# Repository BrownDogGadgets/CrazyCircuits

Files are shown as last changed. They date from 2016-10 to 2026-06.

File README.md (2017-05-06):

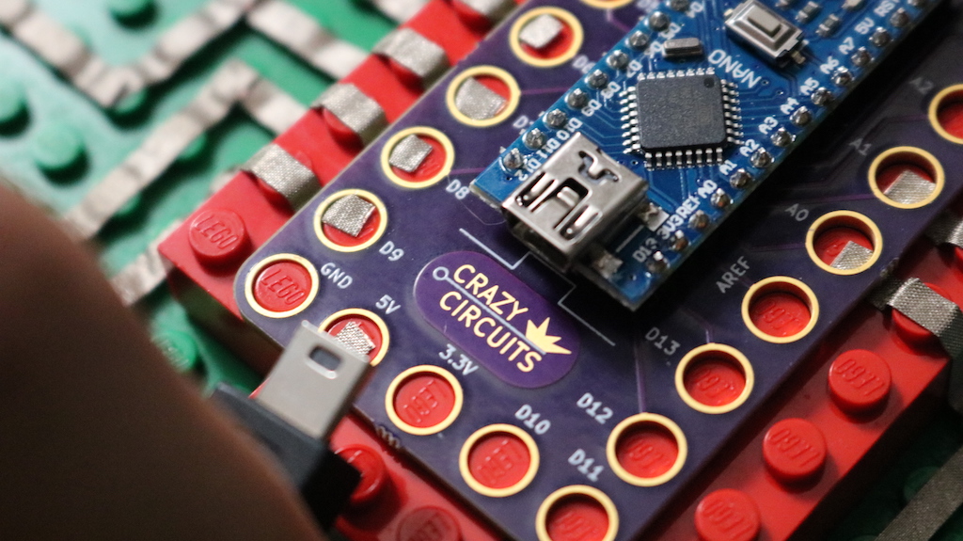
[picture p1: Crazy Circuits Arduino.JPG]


# Crazy Circuits 

Crazy Circuits is a project to create Lego-compatible circuit kits and modules by Brown Dog Gadgets. 

### Circuit Kits and Modules

The <a href="https://github.com/BrownDogGadgets/CrazyCircuits/tree/master/Circuit-Kits">Circuit Kits</a> section has finished zip files with manufacturing files and documentation.

### Development

The <a href="https://github.com/BrownDogGadgets/CrazyCircuits/tree/master/Development/">Developers</a> section has resources for hardware designers to create new modules.

### License

The hardware designs in this repository are distributed under the [CERN Open Hardware License v1.2](http://www.ohwr.org/documents/294). We have included a copy of the LICENSE file.

You may see, change, and share the source of these files. You may order and assemble your own boards from these hardware designs. We recommend the [OSH Park](http://oshpark.com/) board service. 

If you make changes, you must make those changed hardware files available under the same terms of the license. We accept pull requests if you'd like to add a module to our list of modules!

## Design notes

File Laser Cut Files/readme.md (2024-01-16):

Laser Cut Resources

Standalone files for laser cutting. Some may be part of larger projects, some may not.

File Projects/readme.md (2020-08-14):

# Crazy Circuits Projects

This repository holds code for many of our Crazy Circuits projects.

These are not step-by-step directions, and do not serve as full build guides.

For finished projects, instructions, and tutorials with photos and videos, as well as free templates, please visit [BrownDogGadgets.com](http://browndoggadgets.com/)

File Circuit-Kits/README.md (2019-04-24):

# Crazy Circuit Kits and Modules

These projects are all finished and ready to be downloaded. Each folder contains a single board (a module) or a kit that can be snapped apart. 

## Circuit Kits

|Project Name|Version|Documentation|Manufacturing Files|
|---|---|---|---|
|<a href="https://github.com/BrownDogGadgets/CrazyCircuits/tree/master/Circuit-Kits/Circuit-Kits/10mmLED-Button-Battery">10mmLED-Button-Battery</a>|v1.3|<a href="https://github.com/BrownDogGadgets/CrazyCircuits/blob/master/Circuit-Kits/Circuit-Kits/10mmLED-Button-Battery/10mmLED-Button-Battery-v1.3.pdf">View</a>|<a href="https://github.com/BrownDogGadgets/CrazyCircuits/raw/master/Circuit-Kits/Circuit-Kits/10mmLED-Button-Battery/10mmLED-Button-Battery-v1.3.zip">Zip</a>|
|<a href="https://github.com/BrownDogGadgets/CrazyCircuits/tree/master/Circuit-Kits/Circuit-Kits/LegoLED-Button-Battery">LegoLED-Button-Battery</a>|v1.5|<a href="https://github.com/BrownDogGadgets/CrazyCircuits/blob/master/Circuit-Kits/Circuit-Kits/LegoLED-Button-Battery/LegoLED-Button-Battery-v1.5.pdf">View</a>|<a href="https://github.com/BrownDogGadgets/CrazyCircuits/raw/master/Circuit-Kits/Circuit-Kits/LegoLED-Button-Battery/LegoLED-Button-Battery-v1.5.zip">Zip</a>|
|<a href="https://github.com/BrownDogGadgets/CrazyCircuits/tree/master/Circuit-Kits/Circuit-Kits/LegoLED-SMTButton-Battery">LegoLED-SMTButton-Battery</a>|v1.2|<a href="https://github.com/BrownDogGadgets/CrazyCircuits/blob/master/Circuit-Kits/Circuit-Kits/LegoLED-SMTButton-Battery/LegoLED-SMTButton-Battery-v1.2.pdf">View</a>|<a href="https://github.com/BrownDogGadgets/CrazyCircuits/raw/master/Circuit-Kits/Circuit-Kits/LegoLED-SMTButton-Battery/LegoLED-SMTButton-Battery-v1.2.zip">Zip</a>|
|<a href="https://github.com/BrownDogGadgets/CrazyCircuits/tree/master/Circuit-Kits/Circuit-Kits/SMTLimitLED-SMTButton-Battery">SMTLimitedLED-SMTButton-Battery</a>|v1.0|<a href="https://github.com/BrownDogGadgets/CrazyCircuits/blob/master/Circuit-Kits/Circuit-Kits/SMTLimitLED-SMTButton-Battery/SMTLimitLED-SMTButton-Battery-v1.0.pdf">View</a>|<a href="https://github.com/BrownDogGadgets/CrazyCircuits/raw/master/Circuit-Kits/Circuit-Kits/SMTLimitLED-SMTButton-Battery/SMTLimitLED-SMTButton-Battery-v1.0.zip">Zip</a>|
|<a href="https://github.com/BrownDogGadgets/CrazyCircuits/tree/master/Circuit-Kits/Circuit-Kits/USB-Breakout-with-Reset">USB-Breakout-with-Reset</a>|v1.0|<a href="https://github.com/BrownDogGadgets/CrazyCircuits/blob/master/Circuit-Kits/Circuit-Kits/USB-Breakout-with-Reset/USB-Breakout-with-Reset-v1.0.pdf">View</a>|<a href="https://github.com/BrownDogGadgets/CrazyCircuits/raw/master/Circuit-Kits/Circuit-Kits/USB-Breakout-with-Reset/USB-Breakout-with-Reset-v1.0.zip">Zip</a>|
|<a href="https://github.com/BrownDogGadgets/CrazyCircuits/tree/master/Circuit-Kits/Circuit-Kits/VibeMotor-Button-Battery">VibeMotor-Button-Battery</a>|v1.3|<a href="https://github.com/BrownDogGadgets/CrazyCircuits/blob/master/Circuit-Kits/Circuit-Kits/VibeMotor-Button-Battery/VibeMotor-Button-Battery-v1.3.pdf">View</a>|<a href="https://github.com/BrownDogGadgets/CrazyCircuits/raw/master/Circuit-Kits/Circuit-Kits/VibeMotor-Button-Battery/VibeMotor-Button-Battery-v1.3.zip">Zip</a>|

## Modules

- Buttons/Switches/Photocells
- Logos
- Capsense
- Battery/Power
- Microcontrollers
- LEDs
- Speakers, Potentiometers, Motors, Servos
- Generic Modules

### Input Buttons, Switches, Photocells

|Project Name|Ver|Doc|Gerber|Complete|Mask|Top Preview|
|---|---|---|---|---|----|---|
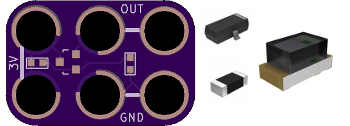
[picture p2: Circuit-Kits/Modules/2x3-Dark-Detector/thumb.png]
|<a href="https://github.com/BrownDogGadgets/CrazyCircuits/tree/master/Circuit-Kits/Modules/2x3-Dark-Detector">2x3 Dark Detector</a>|v1.0|<a href="https://github.com/BrownDogGadgets/CrazyCircuits/blob/master/Circuit-Kits/Modules/2x3-Dark-Detector/2x3-Dark-Detector-v1.0.pdf">View</a>|<a href="https://github.com/BrownDogGadgets/CrazyCircuits/blob/master/Circuit-Kits/Modules/2x3-Dark-Detector/gerbers/2x3-Dark-Detector-v1.0-gerbers.zip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">Zip</a>|<a href="https://github.com/BrownDogGadgets/CrazyCircuits/blob/master/Circuit-Kits/Modules/2x3-Dark-Detector/2x3-Dark-Detector-v1.0.zip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">Zip</a>|Red||
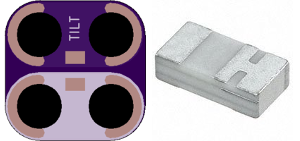
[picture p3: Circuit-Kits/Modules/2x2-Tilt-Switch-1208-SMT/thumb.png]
|<a href="https://github.com/BrownDogGadgets/CrazyCircuits/tree/master/Circuit-Kits/Modules/2x2-Tilt-Switch-1208-SMT">2x2 Tilt Switch SMT</a>|v1.1|<a href="https://github.com/BrownDogGadgets/CrazyCircuits/blob/master/Circuit-Kits/Modules/2x2-Tilt-Switch-1208-SMT/2x2-Tilt-Switch-1208-SMT-v1.1.pdf">View</a>|<a href="https://github.com/BrownDogGadgets/CrazyCircuits/blob/master/Circuit-Kits/Modules/2x2-Tilt-Switch-1208-SMT/gerbers/2x2-Tilt-Switch-1208-SMT-v1.1-gerbers.zip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">Zip</a>|<a href="https://github.com/BrownDogGadgets/CrazyCircuits/blob/master/Circuit-Kits/Modules/2x2-Tilt-Switch-1208-SMT/2x2-Tilt-Switch-1208-SMT-v1.1.zip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">Zip</a>|Red||
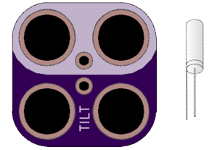
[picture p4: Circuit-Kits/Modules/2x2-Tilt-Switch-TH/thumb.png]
|<a href="https://github.com/BrownDogGadgets/CrazyCircuits/tree/master/Circuit-Kits/Modules/2x2-Tilt-Switch-TH">2x2 Tilt Switch TH</a>|v1.2|<a href="https://github.com/BrownDogGadgets/CrazyCircuits/blob/master/Circuit-Kits/Modules/2x2-Tilt-Switch-TH/2x2-Tilt-Switch-TH-v1.2.pdf">View</a>|<a href="https://github.com/BrownDogGadgets/CrazyCircuits/blob/master/Circuit-Kits/Modules/2x2-Tilt-Switch-TH/gerbers/2x2-Tilt-Switch-TH-v1.2-gerbers.zip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">Zip</a>|<a href="https://github.com/BrownDogGadgets/CrazyCircuits/blob/master/Circuit-Kits/Modules/2x2-Tilt-Switch-TH/2x2-Tilt-Switch-TH-v1.2.zip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">Zip</a>|Red||
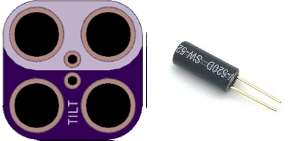
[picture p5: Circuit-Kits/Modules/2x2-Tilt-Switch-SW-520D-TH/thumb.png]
|<a href="https://github.com/BrownDogGadgets/CrazyCircuits/tree/master/Circuit-Kits/Modules/2x2-Tilt-Switch-SW-520D-TH">2x2 Tilt Switch (SW-520D) TH</a>|v1.1|<a href="https://github.com/BrownDogGadgets/CrazyCircuits/blob/master/Circuit-Kits/Modules/2x2-Tilt-Switch-SW-520D-TH/2x2-Tilt-Switch-SW-520D-TH-v1.1.pdf">View</a>|<a href="https://github.com/BrownDogGadgets/CrazyCircuits/blob/master/Circuit-Kits/Modules/2x2-Tilt-Switch-SW-520D-TH/gerbers/2x2-Tilt-Switch-SW-520D-TH-v1.1-gerbers.zip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">Zip</a>|<a href="https://github.com/BrownDogGadgets/CrazyCircuits/blob/master/Circuit-Kits/Modules/2x2-Tilt-Switch-SW-520D-TH/2x2-Tilt-Switch-SW-520D-TH-v1.1.zip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">Zip</a>|Red||
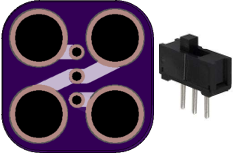
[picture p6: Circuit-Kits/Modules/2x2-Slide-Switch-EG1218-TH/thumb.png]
|<a href="https://github.com/BrownDogGadgets/CrazyCircuits/tree/master/Circuit-Kits/Modules/2x2-Slide-Switch-EG1218-TH">2x2 Three-pin TH Slide Switch (EG1218)</a>|v1.2|<a href="https://github.com/BrownDogGadgets/CrazyCircuits/blob/master/Circuit-Kits/Modules/2x2-Slide-Switch-EG1218-TH/2x2-Slide-Switch-EG1218-TH-v1.2.pdf">View</a>|<a href="https://github.com/BrownDogGadgets/CrazyCircuits/blob/master/Circuit-Kits/Modules/2x2-Slide-Switch-EG1218-TH/gerbers/2x2-Slide-Switch-EG1218-TH-v1.2-gerbers.zip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">Zip</a>|<a href="https://github.com/BrownDogGadgets/CrazyCircuits/blob/master/Circuit-Kits/Modules/2x2-Slide-Switch-EG1218-TH/2x2-Slide-Switch-EG1218-TH-v1.2.zip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">Zip</a>|Red||
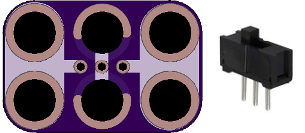
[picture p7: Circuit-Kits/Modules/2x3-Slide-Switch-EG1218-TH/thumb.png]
|<a href="https://github.com/BrownDogGadgets/CrazyCircuits/tree/master/Circuit-Kits/Modules/2x3-Slide-Switch-EG1218-TH">2x3 Three-pin TH Slide Switch (EG1218)</a>|v1.4|<a href="https://github.com/BrownDogGadgets/CrazyCircuits/blob/master/Circuit-Kits/Modules/2x3-Slide-Switch-EG1218-TH/2x3-Slide-Switch-EG1218-TH-v1.4.pdf">View</a>|<a href="https://github.com/BrownDogGadgets/CrazyCircuits/blob/master/Circuit-Kits/Modules/2x3-Slide-Switch-EG1218-TH/gerbers/2x3-Slide-Switch-EG1218-TH-v1.4-gerbers.zip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">Zip</a>|<a href="https://github.com/BrownDogGadgets/CrazyCircuits/blob/master/Circuit-Kits/Modules/2x3-Slide-Switch-EG1218-TH/2x3-Slide-Switch-EG1218-TH-v1.4.zip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">Zip</a>|Red||
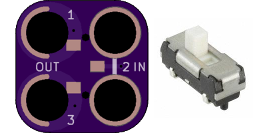
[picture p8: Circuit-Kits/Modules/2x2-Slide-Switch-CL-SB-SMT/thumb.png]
|<a href="https://github.com/BrownDogGadgets/CrazyCircuits/tree/master/Circuit-Kits/Modules/2x2-Slide-Switch-CL-SB-SMT">2x2 Three-pin SMT Slide Switch (CL-SB)</a>|v1.2|<a href="https://github.com/BrownDogGadgets/CrazyCircuits/blob/master/Circuit-Kits/Modules/2x2-Slide-Switch-CL-SB-SMT/2x2-Slide-Switch-CL-SB-SMT-v1.2.pdf">View</a>|<a href="https://github.com/BrownDogGadgets/CrazyCircuits/blob/master/Circuit-Kits/Modules/2x2-Slide-Switch-CL-SB-SMT/gerbers/2x2-Slide-Switch-CL-SB-SMT-v1.2-gerbers.zip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">Zip</a>|<a href="https://github.com/BrownDogGadgets/CrazyCircuits/blob/master/Circuit-Kits/Modules/2x2-Slide-Switch-CL-SB-SMT/2x2-Slide-Switch-CL-SB-SMT-v1.2.zip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">Zip</a>|Red||
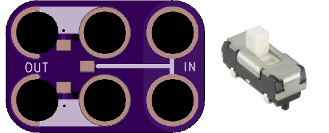
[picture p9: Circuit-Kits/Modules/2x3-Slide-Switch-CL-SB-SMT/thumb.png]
|<a href="https://github.com/BrownDogGadgets/CrazyCircuits/tree/master/Circuit-Kits/Modules/2x3-Slide-Switch-CL-SB-SMT">2x3 Three-pin SMT Slide Switch (CL-SB)</a>|v1.1|<a href="https://github.com/BrownDogGadgets/CrazyCircuits/blob/master/Circuit-Kits/Modules/2x3-Slide-Switch-CL-SB-SMT/2x3-Slide-Switch-CL-SB-SMT-v1.1.pdf">View</a>|<a href="https://github.com/BrownDogGadgets/CrazyCircuits/blob/master/Circuit-Kits/Modules/2x3-Slide-Switch-CL-SB-SMT/gerbers/2x3-Slide-Switch-CL-SB-SMT-v1.1-gerbers.zip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">Zip</a>|<a href="https://github.com/BrownDogGadgets/CrazyCircuits/blob/master/Circuit-Kits/Modules/2x3-Slide-Switch-CL-SB-SMT/2x3-Slide-Switch-CL-SB-SMT-v1.1.zip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">Zip</a>|Red||
|<a href="https://github.com/BrownDogGadgets/CrazyCircuits/tree/master/Circuit-Kits/Modules/1x3-Button-Momentary">1x3 Momentary Pushbutton</a>|v1.3|<a href="https://github.com/BrownDogGadgets/CrazyCircuits/blob/master/Circuit-Kits/Modules/1x3-Button-Momentary/1x3-Button-Momentary-1.3.pdf">View</a>|<a href="https://github.com/BrownDogGadgets/CrazyCircuits/blob/master/Circuit-Kits/Modules/1x3-Button-Momentary/gerbers/1x3-Button-Momentary-1.3-gerbers.zip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">Zip</a>|<a href="https://github.com/BrownDogGadgets/CrazyCircuits/blob/master/Circuit-Kits/Modules/1x3-Button-Momentary/1x3-Button-Momentary-1.3.zip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">Zip</a>|Red||
|<a href="https://github.com/BrownDogGadgets/CrazyCircuits/tree/master/Circuit-Kits/Modules/1x3-Button-Momentary-SMT">1x3 6mm Square SMT Pushbutton</a>|v1.2|<a href="https://github.com/BrownDogGadgets/CrazyCircuits/blob/master/Circuit-Kits/Modules/1x3-Button-Momentary-SMT/1x3-Button-Momentary-SMT-v1.2.pdf">View</a>|<a href="https://github.com/BrownDogGadgets/CrazyCircuits/raw/master/Circuit-Kits/Modules/1x3-Button-Momentary-SMT/gerbers/1x3-Button-Momentary-SMT-v1.2-gerbers.zip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">Zip</a>|<a href="https://github.com/BrownDogGadgets/CrazyCircuits/blob/master/Circuit-Kits/Modules/1x3-Button-Momentary-SMT/1x3-Button-Momentary-SMT-v1.2.zip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">Zip</a>|Red| 
|<a href="https://github.com/BrownDogGadgets/CrazyCircuits/tree/master/Circuit-Kits/Modules/2x3-6mm-Square-SMT-Pushbutton">2x3 6mm Square SMT Pushbutton</a>|v1.1|<a href="https://github.com/BrownDogGadgets/CrazyCircuits/blob/master/Circuit-Kits/Modules/2x3-6mm-Square-SMT-Pushbutton/2x3-6mm-Square-SMT-Pushbutton-v1.1.pdf">View</a>|<a href="https://github.com/BrownDogGadgets/CrazyCircuits/raw/master/Circuit-Kits/Modules/2x3-6mm-Square-SMT-Pushbutton/gerbers/2x3-6mm-Square-SMT-Pushbutton-v1.1-gerbers.zip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">Zip</a>|<a href="https://github.com/BrownDogGadgets/CrazyCircuits/blob/master/Circuit-Kits/Modules/2x3-6mm-Square-SMT-Pushbutton/2x3-6mm-Square-SMT-Pushbutton-v1.1.zip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">Zip</a>|Red| 
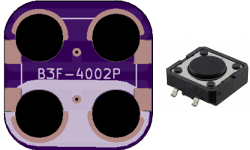
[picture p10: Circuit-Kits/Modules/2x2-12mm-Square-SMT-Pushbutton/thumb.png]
|<a href="https://github.com/BrownDogGadgets/CrazyCircuits/tree/master/Circuit-Kits/Modules/2x2-12mm-Square-SMT-Pushbutton">2x2 12mm Square SMT Pushbutton</a>|v1.1|<a href="https://github.com/BrownDogGadgets/CrazyCircuits/blob/master/Circuit-Kits/Modules/2x2-12mm-Square-SMT-Pushbutton/2x2-12mm-Square-SMT-Pushbutton-v1.1.pdf">View</a>|<a href="https://github.com/BrownDogGadgets/CrazyCircuits/raw/master/Circuit-Kits/Modules/2x2-12mm-Square-SMT-Pushbutton/gerbers/2x2-12mm-Square-SMT-Pushbutton-v1.1-gerbers.z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">Zip</a>|<a href="https://github.com/BrownDogGadgets/CrazyCircuits/blob/master/Circuit-Kits/Modules/2x2-12mm-Square-SMT-Pushbutton/2x2-12mm-Square-SMT-Pushbutton-v1.1.zip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">Zip</a>|Red| 
|<a href="https://github.com/BrownDogGadgets/CrazyCircuits/tree/master/Circuit-Kits/Modules/2x4-12mm-Square-SMT-Pushbutton">2x4 12mm Square SMT Pushbutton</a>|v1.4|<a href="https://github.com/BrownDogGadgets/CrazyCircuits/blob/master/Circuit-Kits/Modules/2x4-12mm-Square-SMT-Pushbutton/2x4-12mm-Square-SMT-Pushbutton-v1.4.pdf">View</a>|<a href="https://github.com/BrownDogGadgets/CrazyCircuits/raw/master/Circuit-Kits/Modules/2x4-12mm-Square-SMT-Pushbutton/gerbers/2x4-12mm-Square-SMT-Pushbutton-v1.4-gerbers.z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">Zip</a>|<a href="https://github.com/BrownDogGadgets/CrazyCircuits/blob/master/Circuit-Kits/Modules/2x4-12mm-Square-SMT-Pushbutton/2x4-12mm-Square-SMT-Pushbutton-v1.4.zip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">Zip</a>|Red| 
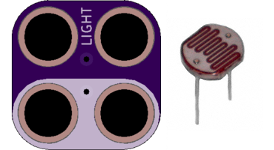
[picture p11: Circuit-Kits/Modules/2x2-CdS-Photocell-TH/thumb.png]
|<a href="https://github.com/BrownDogGadgets/CrazyCircuits/tree/master/Circuit-Kits/Modules/2x2-CdS-Photocell-TH">2x2 CdS Photocell TH</a>|v1.2|<a href="https://github.com/BrownDogGadgets/CrazyCircuits/blob/master/Circuit-Kits/Modules/2x2-CdS-Photocell-TH/2x2-CdS-Photocell-TH-v1.2.pdf">View</a>|<a href="https://github.com/BrownDogGadgets/CrazyCircuits/raw/master/Circuit-Kits/Modules/2x2-CdS-Photocell-TH/gerbers/2x2-CdS-Photocell-TH-v1.2-gerbers.zip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">Zip</a>|<a href="https://github.com/BrownDogGadgets/CrazyCircuits/raw/master/Circuit-Kits/Modules/2x2-CdS-Photocell-TH/2x2-CdS-Photocell-TH-v1.2.zip">Zip</a>|Red||

### Logos

|Project Name|Ver|Doc|Gerber|Complete|Mask|Top Preview|
|---|---|---|---|---|----|---|
|<a href="https://github.com/BrownDogGadgets/CrazyCircuits/tree/master/Circuit-Kits/Modules/1x2-Logo-Crazy-Circuits">1x2 Standalone Crazy Logo</a>|v1.0|<a href="https://github.com/BrownDogGadgets/CrazyCircuits/blob/master/Circuit-Kits/Modules/1x2-Logo-Crazy-Circuits/1x2-Logo-Crazy-Circuits-v1.0.pdf">View</a>|<a href="https://github.com/BrownDogGadgets/CrazyCircuits/raw/master/Circuit-Kits/Modules/1x2-Logo-Crazy-Circuits/gerbers/1x2-Logo-Crazy-Circuits-v1.0-gerbers.zip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">Zip</a>|<a href="https://github.com/BrownDogGadgets/CrazyCircuits/blob/master/Circuit-Kits/Modules/1x2-Logo-Crazy-Circuits/1x2-Logo-Crazy-Circuits-v1.0.zip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">Zip</a>|Blue| 
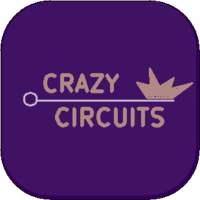
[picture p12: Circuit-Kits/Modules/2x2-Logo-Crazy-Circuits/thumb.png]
|<a href="https://github.com/BrownDogGadgets/CrazyCircuits/tree/master/Circuit-Kits/Modules/2x2-Logo-Crazy-Circuits">2x2 Standalone Crazy Logo</a>|v1.0|<a href="https://github.com/BrownDogGadgets/CrazyCircuits/blob/master/Circuit-Kits/Modules/2x2-Logo-Crazy-Circuits/2x2-Logo-Crazy-Circuits-v1.0.pdf">View</a>|<a href="https://github.com/BrownDogGadgets/CrazyCircuits/raw/master/Circuit-Kits/Modules/2x2-Logo-Crazy-Circuits/gerbers/2x2-Logo-Crazy-Circuits-v1.0-gerbers.zip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">Zip</a>|<a href="https://github.com/BrownDogGadgets/CrazyCircuits/blob/master/Circuit-Kits/Modules/2x2-Logo-Crazy-Circuits/2x2-Logo-Crazy-Circuits-v1.0.zip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">Zip</a>|Blue||

### Capsense

|Project Name|Ver|Doc|Gerber|Complete|Mask|Top Preview|
|---|---|---|---|---|----|---|
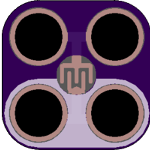
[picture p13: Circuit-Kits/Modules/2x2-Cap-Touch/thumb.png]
|<a href="https://github.com/BrownDogGadgets/CrazyCircuits/tree/master/Circuit-Kits/Modules/2x2-Cap-Touch">2x2 Capacitive Touch</a>|v1.2|<a href="https://github.com/BrownDogGadgets/CrazyCircuits/blob/master/Circuit-Kits/Modules/2x2-Cap-Touch/2x2-Cap-Touch-v1.2.pdf">View</a>|<a href="https://github.com/BrownDogGadgets/CrazyCircuits/raw/master/Circuit-Kits/Modules/2x2-Cap-Touch/gerbers/2x2-Cap-Touch-v1.2-gerbers.zip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">Zip</a>|<a href="https://github.com/BrownDogGadgets/CrazyCircuits/blob/master/Circuit-Kits/Modules/2x2-Cap-Touch/2x2-Cap-Touch-v1.2.zip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">Zip</a>|Red||
|<a href="https://github.com/BrownDogGadgets/CrazyCircuits/tree/master/Circuit-Kits/Modules/2x4-Cap-Touch-Slider">2x4 Capacitive Touch Slider</a>|v1.0|<a href="https://github.com/BrownDogGadgets/CrazyCircuits/blob/master/Circuit-Kits/Modules/2x4-Cap-Touch-Slider/2x4-Cap-Touch-Slider-v1.0.pdf">View</a>|<a href="https://github.com/BrownDogGadgets/CrazyCircuits/raw/master/Circuit-Kits/Modules/2x4-Cap-Touch-Slider/gerbers/2x4-Cap-Touch-Slider-v1.0-gerbers.zip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">Zip</a>|<a href="https://github.com/BrownDogGadgets/CrazyCircuits/blob/master/Circuit-Kits/Modules/2x4-Cap-Touch-Slider/2x4-Cap-Touch-Slider-v1.0.zip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">Zip</a>|Red||

### Battery and Power 

|Project Name|Ver|Doc|Gerber|Complete|Mask|Top Preview|
|---|---|---|---|---|----|---|
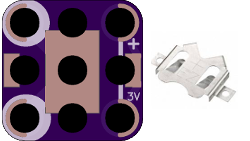
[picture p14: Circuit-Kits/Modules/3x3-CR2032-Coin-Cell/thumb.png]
|<a href="https://github.com/BrownDogGadgets/CrazyCircuits/tree/master/Circuit-Kits/Modules/3x3-CR2032-Coin-Cell">3x3 CR2032 Coin Cell</a>|v1.4|<a href="https://github.com/BrownDogGadgets/CrazyCircuits/blob/master/Circuit-Kits/Modules/3x3-CR2032-Coin-Cell/3x3-CR2032-Coin-Cell-v1.4.pdf">View</a>|<a href="https://github.com/BrownDogGadgets/CrazyCircuits/blob/master/Circuit-Kits/Modules/3x3-CR2032-Coin-Cell/gerbers/3x3-CR2032-Coin-Cell-v1.4-gerbers.zip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">Zip</a>|<a href="https://github.com/BrownDogGadgets/CrazyCircuits/blob/master/Circuit-Kits/Modules/3x3-CR2032-Coin-Cell/3x3-CR2032-Coin-Cell-v1.4.zip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">Zip</a>|Orange||
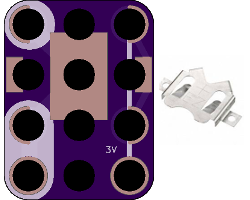
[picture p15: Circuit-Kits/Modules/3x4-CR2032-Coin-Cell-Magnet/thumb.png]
|<a href="https://github.com/BrownDogGadgets/CrazyCircuits/tree/master/Circuit-Kits/Modules/3x4-CR2032-Coin-Cell-Magnet">3x4 CR2032 Coin Cell (Magnet-friendly)</a>|v1.4|<a href="https://github.com/BrownDogGadgets/CrazyCircuits/blob/master/Circuit-Kits/Modules/3x4-CR2032-Coin-Cell-Magnet/3x4-CR2032-Coin-Cell-Magnet-v1.4.pdf">View</a>|<a href="https://github.com/BrownDogGadgets/CrazyCircuits/raw/master/Circuit-Kits/Modules/3x4-CR2032-Coin-Cell-Magnet/gerbers/3x4-CR2032-Coin-Cell-Magnet-v1.4-gerbers.zip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">Zip</a>|<a href="https://github.com/BrownDogGadgets/CrazyCircuits/blob/master/Circuit-Kits/Modules/3x4-CR2032-Coin-Cell-Magnet/3x4-CR2032-Coin-Cell-Magnet-v1.4.zip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">Zip</a>|Orange||
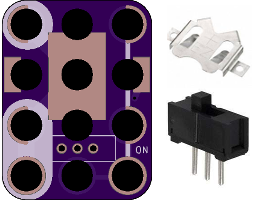
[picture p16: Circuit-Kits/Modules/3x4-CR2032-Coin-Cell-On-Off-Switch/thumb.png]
|<a href="https://github.com/BrownDogGadgets/CrazyCircuits/tree/master/Circuit-Kits/Modules/3x4-CR2032-Coin-Cell-On-Off-Switch">3x4 CR2032 Coin Cell with On/Off Switch</a>|v1.2|<a href="https://github.com/BrownDogGadgets/CrazyCircuits/blob/master/Circuit-Kits/Modules/3x4-CR2032-Coin-Cell-On-Off-Switch/3x4-CR2032-Coin-Cell-On-Off-Switch-v1.2.pdf">View</a>|<a href="https://github.com/BrownDogGadgets/CrazyCircuits/raw/master/Circuit-Kits/Modules/3x4-CR2032-Coin-Cell-On-Off-Switch/gerbers/3x4-CR2032-Coin-Cell-On-Off-Switch-v1.2-g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">Zip</a>|<a href="https://github.com/BrownDogGadgets/CrazyCircuits/blob/master/Circuit-Kits/Modules/3x4-CR2032-Coin-Cell-On-Off-Switch/3x4-CR2032-Coin-Cell-On-Off-Switch-v1.2.zip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">Zip</a>|Orange||
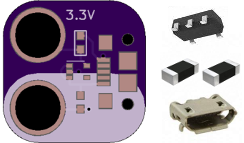
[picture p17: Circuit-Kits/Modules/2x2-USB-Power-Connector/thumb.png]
|<a href="https://github.com/BrownDogGadgets/CrazyCircuits/tree/master/Circuit-Kits/Modules/2x2-USB-Power-Connector">2x2 USB Power Connector</a>|v1.2|<a href="https://github.com/BrownDogGadgets/CrazyCircuits/blob/master/Circuit-Kits/Modules/2x2-USB-Power-Connector/2x2-USB-Power-Connector-v1.2.pdf">View</a>|<a href="https://github.com/BrownDogGadgets/CrazyCircuits/blob/master/Circuit-Kits/Modules/2x2-USB-Power-Connector/gerbers/2x2-USB-Power-Connector-v1.2-gerbers.zip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">Zip</a>|<a href="https://github.com/BrownDogGadgets/CrazyCircuits/blob/master/Circuit-Kits/Modules/2x2-USB-Power-Connector/2x2-USB-Power-Connector-v1.2.zip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">Zip</a>|Orange||
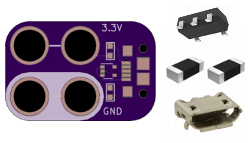
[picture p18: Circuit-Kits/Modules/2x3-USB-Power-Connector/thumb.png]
|<a href="https://github.com/BrownDogGadgets/CrazyCircuits/tree/master/Circuit-Kits/Modules/2x3-USB-Power-Connector">2x3 USB Power Connector</a>|v1.1|<a href="https://github.com/BrownDogGadgets/CrazyCircuits/blob/master/Circuit-Kits/Modules/2x3-USB-Power-Connector/2x3-USB-Power-Connector-v1.1.pdf">View</a>|<a href="https://github.com/BrownDogGadgets/CrazyCircuits/blob/master/Circuit-Kits/Modules/2x3-USB-Power-Connector/gerbers/2x3-USB-Power-Connector-v1.1-gerbers.zip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">Zip</a>|<a href="https://github.com/BrownDogGadgets/CrazyCircuits/blob/master/Circuit-Kits/Modules/2x3-USB-Power-Connector/2x3-USB-Power-Connector-v1.1.zip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">Zip</a>|Orange||

### Microcontrollers

|Project Name|Ver|Doc|Gerber|Complete|Mask|Top Preview|
|---|---|---|---|---|----|---|
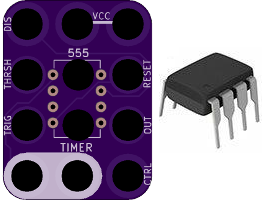
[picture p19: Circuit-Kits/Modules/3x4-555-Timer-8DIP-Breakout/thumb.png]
|<a href="https://github.com/BrownDogGadgets/CrazyCircuits/tree/master/Circuit-Kits/Modules/3x4-555-Timer-8DIP-Breakout">3x4 555 Timer 8DIP Breakout</a>|v1.1|<a href="https://github.com/BrownDogGadgets/CrazyCircuits/blob/master/Circuit-Kits/Modules/3x4-555-Timer-8DIP-Breakout/3x4-555-Timer-8DIP-Breakout-v1.1.pdf">View</a>|<a href="https://github.com/BrownDogGadgets/CrazyCircuits/blob/master/Circuit-Kits/Modules/3x4-555-Timer-8DIP-Breakout/gerbers/3x4-555-Timer-8DIP-Breakout-v1.1-gerbers.zip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">Zip</a>|<a href="https://github.com/BrownDogGadgets/CrazyCircuits/blob/master/Circuit-Kits/Modules/3x4-555-Timer-8DIP-Breakout/3x4-555-Timer-8DIP-Breakout-v1.1.zip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">Zip</a>|Green||
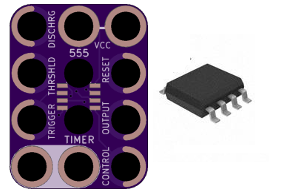
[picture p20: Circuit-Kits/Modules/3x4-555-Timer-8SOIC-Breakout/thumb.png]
|<a href="https://github.com/BrownDogGadgets/CrazyCircuits/tree/master/Circuit-Kits/Modules/3x4-555-Timer-8SOIC-Breakout">3x4 555 Timer 8SOIC Breakout</a>|v1.1|<a href="https://github.com/BrownDogGadgets/CrazyCircuits/blob/master/Circuit-Kits/Modules/3x4-555-Timer-8SOIC-Breakout/3x4-555-Timer-8SOIC-Breakout-v1.1.pdf">View</a>|<a href="https://github.com/BrownDogGadgets/CrazyCircuits/blob/master/Circuit-Kits/Modules/3x4-555-Timer-8SOIC-Breakout/gerbers/3x4-555-Timer-8SOIC-Breakout-v1.1-gerbers.zip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">Zip</a>|<a href="https://github.com/BrownDogGadgets/CrazyCircuits/blob/master/Circuit-Kits/Modules/3x4-555-Timer-8SOIC-Breakout/3x4-555-Timer-8SOIC-Breakout-v1.1.zip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">Zip</a>|Green||
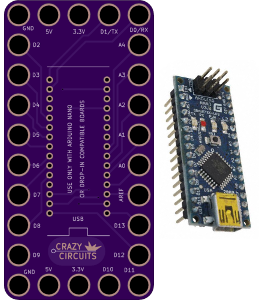
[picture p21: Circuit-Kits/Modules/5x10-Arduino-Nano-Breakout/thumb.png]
|<a href="https://github.com/BrownDogGadgets/CrazyCircuits/tree/master/Circuit-Kits/Modules/5x10-Arduino-Nano-Breakout">5x10 Arduino Nano Breakout</a>|v1.0|<a href="https://github.com/BrownDogGadgets/CrazyCircuits/blob/master/Circuit-Kits/Modules/5x10-Arduino-Nano-Breakout/5x10-Arduino-Nano-Breakout-v1.0.pdf">View</a>|<a href="https://github.com/BrownDogGadgets/CrazyCircuits/blob/master/Circuit-Kits/Modules/5x10-Arduino-Nano-Breakout/gerbers/5x10-Arduino-Nano-Breakout-v1.0-gerbers.zip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">Zip</a>|<a href="https://github.com/BrownDogGadgets/CrazyCircuits/blob/master/Circuit-Kits/Modules/5x10-Arduino-Nano-Breakout/5x10-Arduino-Nano-Breakout-v1.0.zip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">Zip</a>|Green||
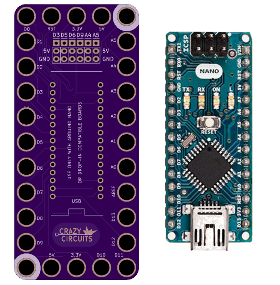
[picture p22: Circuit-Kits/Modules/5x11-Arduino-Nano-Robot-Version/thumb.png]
|<a href="https://github.com/BrownDogGadgets/CrazyCircuits/tree/b013f70d76e0ebcf8f093dcb177555245c25a9a0/Circuit-Kits/Modules/5x11-Arduino-Nano-Robot-Version">5x11 Arduino Nano (Robot Version 1.2)</a>|v1.2|<a href="https://github.com/BrownDogGadgets/CrazyCircuits/raw/b013f70d76e0ebcf8f093dcb177555245c25a9a0/Circuit-Kits/Modules/5x11-Arduino-Nano-Robot-Version/5x11-Arduino-Nano-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">View</a>|<a href="https://github.com/BrownDogGadgets/CrazyCircuits/blob/b013f70d76e0ebcf8f093dcb177555245c25a9a0/Circuit-Kits/Modules/5x11-Arduino-Nano-Robot-Version/gerbers/5x11-Ardu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">Zip</a>|<a href="https://github.com/BrownDogGadgets/CrazyCircuits/blob/b013f70d76e0ebcf8f093dcb177555245c25a9a0/Circuit-Kits/Modules/5x11-Arduino-Nano-Robot-Version/5x11-Arduino-Nano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">Zip</a>|Green||
|<a href="https://github.com/BrownDogGadgets/CrazyCircuits/tree/master/Circuit-Kits/Modules/5x11-Arduino-Nano-Robot-Version">5x11 Arduino Nano (Robot Version)</a>|v1.6|<a href="https://github.com/BrownDogGadgets/CrazyCircuits/blob/master/Circuit-Kits/Modules/5x11-Arduino-Nano-Robot-Version/5x11-Arduino-Nano-Robot-Version-v1.6.pdf">View</a>|<a href="https://github.com/BrownDogGadgets/CrazyCircuits/blob/master/Circuit-Kits/Modules/5x11-Arduino-Nano-Robot-Version/gerbers/5x11-Arduino-Nano-Robot-Version-v1.6-gerber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">Zip</a>|<a href="https://github.com/BrownDogGadgets/CrazyCircuits/blob/master/Circuit-Kits/Modules/5x11-Arduino-Nano-Robot-Version/5x11-Arduino-Nano-Robot-Version-v1.6.zip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">Zip</a>|Green||
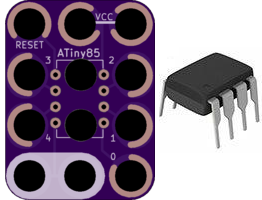
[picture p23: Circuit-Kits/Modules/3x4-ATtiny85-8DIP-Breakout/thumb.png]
|<a href="https://github.com/BrownDogGadgets/CrazyCircuits/tree/master/Circuit-Kits/Modules/3x4-ATtiny85-8DIP-Breakout">3x4 ATtiny85 8DIP Breakout</a>|v1.3|<a href="https://github.com/BrownDogGadgets/CrazyCircuits/blob/master/Circuit-Kits/Modules/3x4-ATtiny85-8DIP-Breakout/3x4-ATtiny85-8DIP-Breakout-v1.3.pdf">View</a>|<a href="https://github.com/BrownDogGadgets/CrazyCircuits/blob/master/Circuit-Kits/Modules/3x4-ATtiny85-8DIP-Breakout/gerbers/3x4-ATtiny85-8DIP-Breakout-v1.3-gerbers.zip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">Zip</a>|<a href="https://github.com/BrownDogGadgets/CrazyCircuits/blob/master/Circuit-Kits/Modules/3x4-ATtiny85-8DIP-Breakout/3x4-ATtiny85-8DIP-Breakout-v1.3.zip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">Zip</a>|Green||
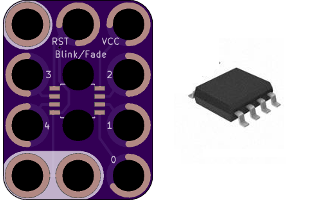
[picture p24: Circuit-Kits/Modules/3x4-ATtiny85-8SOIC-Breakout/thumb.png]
|<a href="https://github.com/BrownDogGadgets/CrazyCircuits/tree/master/Circuit-Kits/Modules/3x4-ATtiny85-8SOIC-Breakout">3x4 ATtiny85 8SOIC Breakout</a>|v1.3|<a href="https://github.com/BrownDogGadgets/CrazyCircuits/blob/master/Circuit-Kits/Modules/3x4-ATtiny85-8SOIC-Breakout/3x4-ATtiny85-8SOIC-Breakout-v1.3.pdf">View</a>|<a href="https://github.com/BrownDogGadgets/CrazyCircuits/blob/master/Circuit-Kits/Modules/3x4-ATtiny85-8SOIC-Breakout/gerbers/3x4-ATtiny85-8SOIC-Breakout-v1.3-gerbers.zip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">Zip</a>|<a href="https://github.com/BrownDogGadgets/CrazyCircuits/blob/master/Circuit-Kits/Modules/3x4-ATtiny85-8SOIC-Breakout/3x4-ATtiny85-8SOIC-Breakout-v1.3.zip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">Zip</a>|Green||
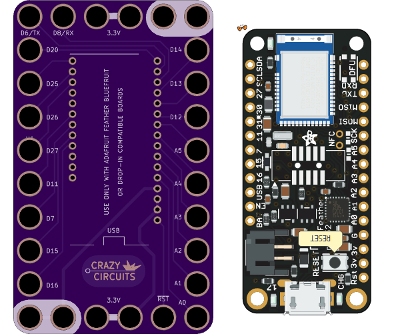
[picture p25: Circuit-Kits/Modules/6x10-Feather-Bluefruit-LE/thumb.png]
|<a href="https://github.com/BrownDogGadgets/CrazyCircuits/tree/master/Circuit-Kits/Modules/6x10-Feather-Bluefruit-LE">6x10 Feather Bluefruit nRF52 LE Breakout</a>|v1.0|<a href="https://github.com/BrownDogGadgets/CrazyCircuits/blob/master/Circuit-Kits/Modules/6x10-Feather-Bluefruit-LE/6x10-Feather-Bluefruit-LE-v1.0.pdf">View</a>|<a href="https://github.com/BrownDogGadgets/CrazyCircuits/blob/master/Circuit-Kits/Modules/6x10-Feather-Bluefruit-LE/gerbers/6x10-Feather-Bluefruit-LE-v1.0-gerbers.zip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">Zip</a>|<a href="https://github.com/BrownDogGadgets/CrazyCircuits/blob/master/Circuit-Kits/Modules/6x10-Feather-Bluefruit-LE/6x10-Feather-Bluefruit-LE-v1.0.zip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">Zip</a>|Green||
|<a href="https://github.com/BrownDogGadgets/CrazyCircuits/tree/master/Circuit-Kits/Modules/6x10-Feather-Huzzah-ESP8266">6x10 Feather ESP8266 Huzzah Breakout</a>|v1.0|<a href="https://github.com/BrownDogGadgets/CrazyCircuits/blob/master/Circuit-Kits/Modules/6x10-Feather-Huzzah-ESP8266/6x10-Feather-Huzzah-ESP8266-v1.0.pdf">View</a>|<a href="https://github.com/BrownDogGadgets/CrazyCircuits/blob/master/Circuit-Kits/Modules/6x10-Feather-Huzzah-ESP8266/gerbers/6x10-Feather-Huzzah-ESP8266-v1.0-gerbers.zip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">Zip</a>|<a href="https://github.com/BrownDogGadgets/CrazyCircuits/blob/master/Circuit-Kits/Modules/6x10-Feather-Huzzah-ESP8266/6x10-Feather-Huzzah-ESP8266-v1.0.zip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">Zip</a>|Green||
|<a href="https://github.com/BrownDogGadgets/CrazyCircuits/tree/master/Circuit-Kits/Modules/6x11-Microbit-Breakout">6x11 Microbit Breakout</a>|v1.0|<a href="https://github.com/BrownDogGadgets/CrazyCircuits/blob/master/Circuit-Kits/Modules/6x11-Microbit-Breakout/6x11-Microbit-Breakout-v1.0.pdf">View</a>|<a href="https://github.com/BrownDogGadgets/CrazyCircuits/blob/master/Circuit-Kits/Modules/6x11-Microbit-Breakout/gerbers/6x11-Microbit-Breakout-v1.0-gerbers.zip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">Zip</a>|<a href="https://github.com/BrownDogGadgets/CrazyCircuits/blob/master/Circuit-Kits/Modules/6x11-Microbit-Breakout/6x11-Microbit-Breakout-v1.0.zip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">Zip</a>|Green||
|<a href="https://github.com/BrownDogGadgets/CrazyCircuits/tree/master/Circuit-Kits/Modules/6x11-NodeMCU-V2-Breakout">6x11 NodeMCU V2 Breakout</a>|v1.0|<a href="https://github.com/BrownDogGadgets/CrazyCircuits/blob/master/Circuit-Kits/Modules/6x11-NodeMCU-V2-Breakout/6x11-NodeMCU-V2-Breakout-v1.0.pdf">View</a>|<a href="https://github.com/BrownDogGadgets/CrazyCircuits/blob/master/Circuit-Kits/Modules/6x11-NodeMCU-V2-Breakout/gerbers/6x11-NodeMCU-V2-Breakout-v1.0-gerbers.zip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">Zip</a>|<a href="https://github.com/BrownDogGadgets/CrazyCircuits/blob/master/Circuit-Kits/Modules/6x11-NodeMCU-V2-Breakout/6x11-NodeMCU-V2-Breakout-v1.0.zip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">Zip</a>|Green||
|<a href="https://github.com/BrownDogGadgets/CrazyCircuits/tree/master/Circuit-Kits/Modules/6x10-Photon-Breakout">6x10 Photon Breakout</a>|v1.1|<a href="https://github.com/BrownDogGadgets/CrazyCircuits/blob/master/Circuit-Kits/Modules/6x10-Photon-Breakout/6x10-Photon-Breakout-v1.1.pdf">View</a>|<a href="https://github.com/BrownDogGadgets/CrazyCircuits/blob/master/Circuit-Kits/Modules/6x10-Photon-Breakout/gerbers/6x10-Photon-Breakout-v1.1-gerbers.zip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">Zip</a>|<a href="https://github.com/BrownDogGadgets/CrazyCircuits/blob/master/Circuit-Kits/Modules/6x10-Photon-Breakout/6x10-Photon-Breakout-v1.1.zip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">Zip</a>|Green||
|<a href="https://github.com/BrownDogGadgets/CrazyCircuits/tree/master/Circuit-Kits/Modules/8x12-PocketBeagle-Breakout">8x12 PocketBeagle Breakout</a>|v1.0|<a href="https://github.com/BrownDogGadgets/CrazyCircuits/blob/master/Circuit-Kits/Modules/8x12-PocketBeagle-Breakout/8x12-PocketBeagle-Breakout-v1.0.pdf">View</a>|<a href="https://github.com/BrownDogGadgets/CrazyCircuits/blob/master/Circuit-Kits/Modules/8x12-PocketBeagle-Breakout/gerbers/8x12-PocketBeagle-Breakout-v1.0-gerbers.zip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">Zip</a>|<a href="https://github.com/BrownDogGadgets/CrazyCircuits/blob/master/Circuit-Kits/Modules/8x12-PocketBeagle-Breakout/8x12-PocketBeagle-Breakout-v1.0.zip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">Zip</a>|Green||
|<a href="https://github.com/BrownDogGadgets/CrazyCircuits/tree/master/Circuit-Kits/Modules/7x11-RasPi-Zero-Breakout">7x11 Raspberry Pi Zero Breakout</a>|v1.0|<a href="https://github.com/BrownDogGadgets/CrazyCircuits/blob/master/Circuit-Kits/Modules/7x11-RasPi-Zero-Breakout/7x11-RasPi-Zero-Breakout-v1.0.pdf">View</a>|<a href="https://github.com/BrownDogGadgets/CrazyCircuits/blob/master/Circuit-Kits/Modules/7x11-RasPi-Zero-Breakout/gerbers/7x11-RasPi-Zero-Breakout-v1.0-gerbers.zip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">Zip</a>|<a href="https://github.com/BrownDogGadgets/CrazyCircuits/blob/master/Circuit-Kits/Modules/7x11-RasPi-Zero-Breakout/7x11-RasPi-Zero-Breakout-v1.0.zip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">Zip</a>|Green||
|<a href="https://github.com/BrownDogGadgets/CrazyCircuits/tree/master/Circuit-Kits/Modules/4x7-Teensy-Breakout">4x7 Teensy LC Breakout</a>|v1.1|<a href="https://github.com/BrownDogGadgets/CrazyCircuits/blob/master/Circuit-Kits/Modules/4x7-Teensy-Breakout/4x7-Teensy-Breakout-v1.1.pdf">View</a>|<a href="https://github.com/BrownDogGadgets/CrazyCircuits/blob/master/Circuit-Kits/Modules/4x7-Teensy-Breakout/gerbers/4x7-Teensy-Breakout-v1.1-gerbers.zip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">Zip</a>|<a href="https://github.com/BrownDogGadgets/CrazyCircuits/blob/master/Circuit-Kits/Modules/4x7-Teensy-Breakout/4x7-Teensy-Breakout-v1.1.zip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">Zip</a>|Green||
|<a href="https://github.com/BrownDogGadgets/CrazyCircuits/tree/master/Circuit-Kits/Modules/4x10-Teensy-LC-Breakout">4x10 Teensy LC Breakout</a>|v1.1|<a href="https://github.com/BrownDogGadgets/CrazyCircuits/blob/master/Circuit-Kits/Modules/4x10-Teensy-LC-Breakout/4x10-Teensy-LC-Breakout-v1.1.pdf">View</a>|<a href="https://github.com/BrownDogGadgets/CrazyCircuits/blob/master/Circuit-Kits/Modules/4x10-Teensy-LC-Breakout/gerbers/4x10-Teensy-LC-Breakout-v1.1-gerbers.zip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">Zip</a>|<a href="https://github.com/BrownDogGadgets/CrazyCircuits/blob/master/Circuit-Kits/Modules/4x10-Teensy-LC-Breakout/4x10-Teensy-LC-Breakout-v1.1.zip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">Zip</a>|Green||
|<a href="https://github.com/BrownDogGadgets/CrazyCircuits/tree/master/Circuit-Kits/Modules/5x10-Teensy-LC-Breakout">5x10 Teensy LC Breakout</a>|v1.4|<a href="https://github.com/BrownDogGadgets/CrazyCircuits/blob/master/Circuit-Kits/Modules/5x10-Teensy-LC-Breakout/5x10-Teensy-LC-Breakout-v1.4.pdf">View</a>|<a href="https://github.com/BrownDogGadgets/CrazyCircuits/blob/master/Circuit-Kits/Modules/5x10-Teensy-LC-Breakout/gerbers/5x10-Teensy-LC-Breakout-v1.4-gerbers.zip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">Zip</a>|<a href="https://github.com/BrownDogGadgets/CrazyCircuits/blob/master/Circuit-Kits/Modules/5x10-Teensy-LC-Breakout/5x10-Teensy-LC-Breakout-v1.4.zip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">Zip</a>|Green||

### LEDs

|Project Name|Ver|Doc|Gerber|Complete|Mask|Top Preview|
|---|---|---|---|---|----|---|
|<a href="https://github.com/BrownDogGadgets/CrazyCircuits/tree/master/Circuit-Kits/Modules/2x2-LED-TH-2.54mm-Pitch">2x2 LED TH (2.54mm Pitch)</a>|v1.3|<a href="https://github.com/BrownDogGadgets/CrazyCircuits/blob/master/Circuit-Kits/Modules/2x2-LED-TH-2.54mm-Pitch/2x2-LED-TH-2.54mm-Pitch-v1.3.pdf">View</a>|<a href="https://github.com/BrownDogGadgets/CrazyCircuits/raw/master/Circuit-Kits/Modules/2x2-LED-TH-2.54mm-Pitch/gerbers/2x2-LED-TH-2.54mm-Pitch-v1.3-gerbers.zip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">Zip</a>|<a href="https://github.com/BrownDogGadgets/CrazyCircuits/raw/master/Circuit-Kits/Modules/2x2-LED-TH-2.54mm-Pitch/2x2-LED-TH-2.54mm-Pitch-v1.3.zip">Zip</a>|Black||
|<a href="https://github.com/BrownDogGadgets/CrazyCircuits/tree/master/Circuit-Kits/Modules/2x3-LED-TH-2.54mm-Pitch-Magnet">2x3 LED TH (2.54mm Pitch) (Magnet-friendly)</a>|v1.3|<a href="https://github.com/BrownDogGadgets/CrazyCircuits/blob/master/Circuit-Kits/Modules/2x3-LED-TH-2.54mm-Pitch-Magnet/2x3-LED-TH-2.54mm-Pitch-Magnet-v1.3.pdf">View</a>|<a href="https://github.com/BrownDogGadgets/CrazyCircuits/raw/master/Circuit-Kits/Modules/2x3-LED-TH-2.54mm-Pitch-Magnet/gerbers/2x3-LED-TH-2.54mm-Pitch-Magnet-v1.3-gerbers.z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">Zip</a>|<a href="https://github.com/BrownDogGadgets/CrazyCircuits/raw/master/Circuit-Kits/Modules/2x3-LED-TH-2.54mm-Pitch-Magnet/2x3-LED-TH-2.54mm-Pitch-Magnet-v1.3.zip">Zip</a>|Black||
|<a href="https://github.com/BrownDogGadgets/CrazyCircuits/tree/master/Circuit-Kits/Modules/1x2-LED-1206-SMT">1x2 LED SMT</a>|v1.2|<a href="https://github.com/BrownDogGadgets/CrazyCircuits/blob/master/Circuit-Kits/Modules/1x2-LED-1206-SMT/1x2-LED-1206-SMT-v1.2.pdf">View</a>|<a href="https://github.com/BrownDogGadgets/CrazyCircuits/raw/master/Circuit-Kits/Modules/1x2-LED-1206-SMT/gerbers/1x2-LED-1206-SMT-v1.2-gerbers.zip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">Zip</a>|<a href="https://github.com/BrownDogGadgets/CrazyCircuits/raw/master/Circuit-Kits/Modules/1x2-LED-1206-SMT/1x2-LED-1206-SMT-v1.2.zip">Zip</a>|Black||
|<a href="https://github.com/BrownDogGadgets/CrazyCircuits/tree/master/Circuit-Kits/Modules/2x2-LED-SMT">2x2 LED SMT</a>|v1.2|<a href="https://github.com/BrownDogGadgets/CrazyCircuits/blob/master/Circuit-Kits/Modules/2x2-LED-SMT/2x2-LED-SMT-v1.2.pdf">View</a>|<a href="https://github.com/BrownDogGadgets/CrazyCircuits/raw/master/Circuit-Kits/Modules/2x2-LED-SMT/gerbers/2x2-LED-SMT-v1.2-gerbers.zip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">Zip</a>|<a href="https://github.com/BrownDogGadgets/CrazyCircuits/raw/master/Circuit-Kits/Modules/2x2-LED-SMT/2x2-LED-SMT-v1.2.zip">Zip</a>|Black||
|<a href="https://github.com/BrownDogGadgets/CrazyCircuits/tree/master/Circuit-Kits/Modules/2x2-LED-SMT-LIMITED">2x2 LED SMT Limited</a>|v1.3|<a href="https://github.com/BrownDogGadgets/CrazyCircuits/blob/master/Circuit-Kits/Modules/2x2-LED-SMT-LIMITED/2x2-LED-SMT-LIMITED-v1.3.pdf">View</a>|<a href="https://github.com/BrownDogGadgets/CrazyCircuits/raw/master/Circuit-Kits/Modules/2x2-LED-SMT-LIMITED/gerbers/2x2-LED-SMT-LIMITED-v1.3-gerbers.zip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">Zip</a>|<a href="https://github.com/BrownDogGadgets/CrazyCircuits/raw/master/Circuit-Kits/Modules/2x2-LED-SMT-LIMITED/2x2-LED-SMT-LIMITED-v1.3.zip">Zip</a>|Black||
|<a href="https://github.com/BrownDogGadgets/CrazyCircuits/tree/master/Circuit-Kits/Modules/2x2-LED-RED-SMT-LIMITED">2x2 LED Red SMT Limited</a>|v1.0|<a href="https://github.com/BrownDogGadgets/CrazyCircuits/blob/master/Circuit-Kits/Modules/2x2-LED-RED-SMT-LIMITED/2x2-LED-RED-SMT-LIMITED-v1.0.pdf">View</a>|<a href="https://github.com/BrownDogGadgets/CrazyCircuits/raw/master/Circuit-Kits/Modules/2x2-LED-RED-SMT-LIMITED/gerbers/2x2-LED-RED-SMT-LIMITED-v1.0-gerbers.zip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">Zip</a>|<a href="https://github.com/BrownDogGadgets/CrazyCircuits/raw/master/Circuit-Kits/Modules/2x2-LED-RED-SMT-LIMITED/2x2-LED-RED-SMT-LIMITED-v1.0.zip">Zip</a>|Black||
|<a href="https://github.com/BrownDogGadgets/CrazyCircuits/tree/master/Circuit-Kits/Modules/2x2-LED-BLUE-SMT-LIMITED">2x2 LED Blue SMT Limited</a>|v1.0|<a href="https://github.com/BrownDogGadgets/CrazyCircuits/blob/master/Circuit-Kits/Modules/2x2-LED-BLUE-SMT-LIMITED/2x2-LED-BLUE-SMT-LIMITED-v1.0.pdf">View</a>|<a href="https://github.com/BrownDogGadgets/CrazyCircuits/raw/master/Circuit-Kits/Modules/2x2-LED-BLUE-SMT-LIMITED/gerbers/2x2-LED-BLUE-SMT-LIMITED-v1.0-gerbers.zip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">Zip</a>|<a href="https://github.com/BrownDogGadgets/CrazyCircuits/raw/master/Circuit-Kits/Modules/2x2-LED-BLUE-SMT-LIMITED/2x2-LED-BLUE-SMT-LIMITED-v1.0.zip">Zip</a>|Black||
|<a href="https://github.com/BrownDogGadgets/CrazyCircuits/tree/master/Circuit-Kits/Modules/2x2-LED-GREEN-SMT-LIMITED">2x2 LED Green SMT Limited</a>|v1.0|<a href="https://github.com/BrownDogGadgets/CrazyCircuits/blob/master/Circuit-Kits/Modules/2x2-LED-GREEN-SMT-LIMITED/2x2-LED-GREEN-SMT-LIMITED-v1.0.pdf">View</a>|<a href="https://github.com/BrownDogGadgets/CrazyCircuits/raw/master/Circuit-Kits/Modules/2x2-LED-GREEN-SMT-LIMITED/gerbers/2x2-LED-GREEN-SMT-LIMITED-v1.0-gerbers.zip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">Zip</a>|<a href="https://github.com/BrownDogGadgets/CrazyCircuits/raw/master/Circuit-Kits/Modules/2x2-LED-GREEN-SMT-LIMITED/2x2-LED-GREEN-SMT-LIMITED-v1.0.zip">Zip</a>|Black||
|<a href="https://github.com/BrownDogGadgets/CrazyCircuits/tree/master/Circuit-Kits/Modules/2x2-LED-YELLOW-SMT-LIMITED">2x2 LED Yellow SMT Limited</a>|v1.0|<a href="https://github.com/BrownDogGadgets/CrazyCircuits/blob/master/Circuit-Kits/Modules/2x2-LED-YELLOW-SMT-LIMITED/2x2-LED-YELLOW-SMT-LIMITED-v1.0.pdf">View</a>|<a href="https://github.com/BrownDogGadgets/CrazyCircuits/raw/master/Circuit-Kits/Modules/2x2-LED-YELLOW-SMT-LIMITED/gerbers/2x2-LED-YELLOW-SMT-LIMITED-v1.0-gerbers.zip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">Zip</a>|<a href="https://github.com/BrownDogGadgets/CrazyCircuits/raw/master/Circuit-Kits/Modules/2x2-LED-YELLOW-SMT-LIMITED/2x2-LED-YELLOW-SMT-LIMITED-v1.0.zip">Zip</a>|Black||
|<a href="https://github.com/BrownDogGadgets/CrazyCircuits/tree/master/Circuit-Kits/Modules/2x2-LED-WHITE-SMT-LIMITED">2x2 LED White SMT Limited</a>|v1.0|<a href="https://github.com/BrownDogGadgets/CrazyCircuits/blob/master/Circuit-Kits/Modules/2x2-LED-WHITE-SMT-LIMITED/2x2-LED-WHITE-SMT-LIMITED-v1.0.pdf">View</a>|<a href="https://github.com/BrownDogGadgets/CrazyCircuits/raw/master/Circuit-Kits/Modules/2x2-LED-WHITE-SMT-LIMITED/gerbers/2x2-LED-WHITE-SMT-LIMITED-v1.0-gerbers.zip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">Zip</a>|<a href="https://github.com/BrownDogGadgets/CrazyCircuits/raw/master/Circuit-Kits/Modules/2x2-LED-WHITE-SMT-LIMITED/2x2-LED-WHITE-SMT-LIMITED-v1.0.zip">Zip</a>|Black||
|<a href="https://github.com/BrownDogGadgets/CrazyCircuits/tree/master/Circuit-Kits/Modules/2x3-LED-RGB-SMT">2x3 LED RGB SMT</a>|v1.1|<a href="https://github.com/BrownDogGadgets/CrazyCircuits/blob/master/Circuit-Kits/Modules/2x3-LED-RGB-SMT/2x3-LED-RGB-SMT-v1.1.pdf">View</a>|<a href="https://github.com/BrownDogGadgets/CrazyCircuits/raw/master/Circuit-Kits/Modules/2x3-LED-RGB-SMT/gerbers/2x3-LED-RGB-SMT-v1.1-gerbers.zip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">Zip</a>|<a href="https://github.com/BrownDogGadgets/CrazyCircuits/raw/master/Circuit-Kits/Modules/2x3-LED-RGB-SMT/2x3-LED-RGB-SMT-v1.1.zip">Zip</a>|Black||
|<a href="https://github.com/BrownDogGadgets/CrazyCircuits/tree/master/Circuit-Kits/Modules/2x3-LED-RGB-A-SMT">2x3 LED RGB-A SMT</a>|v1.1|<a href="https://github.com/BrownDogGadgets/CrazyCircuits/blob/master/Circuit-Kits/Modules/2x3-LED-RGB-A-SMT/2x3-LED-RGB-A-SMT-v1.1.pdf">View</a>|<a href="https://github.com/BrownDogGadgets/CrazyCircuits/raw/master/Circuit-Kits/Modules/2x3-LED-RGB-A-SMT/gerbers/2x3-LED-RGB-A-SMT-v1.1-gerbers.zip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">Zip</a>|<a href="https://github.com/BrownDogGadgets/CrazyCircuits/raw/master/Circuit-Kits/Modules/2x3-LED-RGB-A-SMT/2x3-LED-RGB-A-SMT-v1.1.zip">Zip</a>|Black||
|<a href="https://github.com/BrownDogGadgets/CrazyCircuits/tree/master/Circuit-Kits/Modules/2x3-LED-RGB-SMT-Round-Flat-Top">2x3 LED RGB SMT Round Flat Top</a>|v1.0|<a href="https://github.com/BrownDogGadgets/CrazyCircuits/blob/master/Circuit-Kits/Modules/2x3-LED-RGB-SMT-Round-Flat-Top/2x3-LED-RGB-SMT-Round-Flat-Top-v1.0.pdf">View</a>|<a href="https://github.com/BrownDogGadgets/CrazyCircuits/raw/master/Circuit-Kits/Modules/2x3-LED-RGB-SMT-Round-Flat-Top/gerbers/2x3-LED-RGB-SMT-Round-Flat-Top-v1.0-gerbers.z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">Zip</a>|<a href="https://github.com/BrownDogGadgets/CrazyCircuits/raw/master/Circuit-Kits/Modules/2x3-LED-RGB-SMT-Round-Flat-Top/2x3-LED-RGB-SMT-Round-Flat-Top-v1.0.zip">Zip</a>|Black||
|<a href="https://github.com/BrownDogGadgets/CrazyCircuits/tree/master/Circuit-Kits/Modules/2x2-LED-RGB-NeoPixel-SMT">2x2 LED RGB NeoPixel (WS2812B) SMT</a>|v1.1|<a href="https://github.com/BrownDogGadgets/CrazyCircuits/blob/master/Circuit-Kits/Modules/2x2-LED-RGB-NeoPixel-SMT/2x2-LED-RGB-NeoPixel-SMT-v1.1.pdf">View</a>|<a href="https://github.com/BrownDogGadgets/CrazyCircuits/raw/master/Circuit-Kits/Modules/2x2-LED-RGB-NeoPixel-SMT/gerbers/2x2-LED-RGB-NeoPixel-SMT-v1.1-gerbers.zip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">Zip</a>|<a href="https://github.com/BrownDogGadgets/CrazyCircuits/raw/master/Circuit-Kits/Modules/2x2-LED-RGB-NeoPixel-SMT/2x2-LED-RGB-NeoPixel-SMT-v1.1.zip">Zip</a>|Black||
|<a href="https://github.com/BrownDogGadgets/CrazyCircuits/tree/master/Circuit-Kits/Modules/2x3-LED-RGB-NeoPixel-SMT">2x3 LED RGB NeoPixel (WS2812B) SMT</a>|v1.2|<a href="https://github.com/BrownDogGadgets/CrazyCircuits/blob/master/Circuit-Kits/Modules/2x3-LED-RGB-NeoPixel-SMT/2x3-LED-RGB-NeoPixel-SMT-v1.2.pdf">View</a>|<a href="https://github.com/BrownDogGadgets/CrazyCircuits/raw/master/Circuit-Kits/Modules/2x3-LED-RGB-NeoPixel-SMT/gerbers/2x3-LED-RGB-NeoPixel-SMT-v1.2-gerbers.zip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">Zip</a>|<a href="https://github.com/BrownDogGadgets/CrazyCircuits/raw/master/Circuit-Kits/Modules/2x3-LED-RGB-NeoPixel-SMT/2x3-LED-RGB-NeoPixel-SMT-v1.2.zip">Zip</a>|Black||
|<a href="https://github.com/BrownDogGadgets/CrazyCircuits/tree/master/Circuit-Kits/Modules/2x3-LED-RGB-Mini-Neopixel-SMT">2x3 LED RGB Neopixel Mini (SK6812) SMT</a>|v1.0|<a href="https://github.com/BrownDogGadgets/CrazyCircuits/blob/master/Circuit-Kits/Modules/2x3-LED-RGB-Mini-Neopixel-SMT/2x3-LED-RGB-Mini-Neopixel-SMT-v1.0.pdf">View</a>|<a href="https://github.com/BrownDogGadgets/CrazyCircuits/raw/master/Circuit-Kits/Modules/2x3-LED-RGB-Mini-Neopixel-SMT/gerbers/2x3-LED-RGB-Mini-Neopixel-SMT-v1.0-gerbers.zip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">Zip</a>|<a href="https://github.com/BrownDogGadgets/CrazyCircuits/raw/master/Circuit-Kits/Modules/2x3-LED-RGB-Mini-Neopixel-SMT/2x3-LED-RGB-Mini-Neopixel-SMT-v1.0.zip">Zip</a>|Black||
|<a href="https://github.com/BrownDogGadgets/CrazyCircuits/tree/master/Circuit-Kits/Modules/2x2-LED-RGB-SMT">2x2 LED RGB SMT</a>|v1.1|<a href="https://github.com/BrownDogGadgets/CrazyCircuits/blob/master/Circuit-Kits/Modules/2x2-LED-RGB-SMT/2x2-LED-RGB-SMT-v1.1.pdf">View</a>|<a href="https://github.com/BrownDogGadgets/CrazyCircuits/raw/master/Circuit-Kits/Modules/2x2-LED-RGB-SMT/gerbers/2x2-LED-RGB-SMT-v1.1-gerbers.zip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">Zip</a>|<a href="https://github.com/BrownDogGadgets/CrazyCircuits/raw/master/Circuit-Kits/Modules/2x2-LED-RGB-SMT/2x2-LED-RGB-SMT-v1.1.zip">Zip</a>|Black||
|<a href="https://github.com/BrownDogGadgets/CrazyCircuits/tree/master/Circuit-Kits/Modules/2x3-LED-RGB-TH-4PIN">2x3 LED RGB TH</a>|v1.0|<a href="https://github.com/BrownDogGadgets/CrazyCircuits/blob/master/Circuit-Kits/Modules/2x3-LED-RGB-TH-4PIN/2x3-LED-RGB-TH-4PIN-v1.0.pdf">View</a>|<a href="https://github.com/BrownDogGadgets/CrazyCircuits/raw/master/Circuit-Kits/Modules/2x3-LED-RGB-TH-4PIN/gerbers/2x3-LED-RGB-TH-4PIN-v1.0-gerbers.zip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">Zip</a>|<a href="https://github.com/BrownDogGadgets/CrazyCircuits/raw/master/Circuit-Kits/Modules/2x3-LED-RGB-TH-4PIN/2x3-LED-RGB-TH-4PIN-v1.0.zip">Zip</a>|Black||
|<a href="https://github.com/BrownDogGadgets/CrazyCircuits/tree/master/Circuit-Kits/Modules/2x2-LED-RGB-TH-4PIN">2x2 LED RGB TH</a>|v1.1|<a href="https://github.com/BrownDogGadgets/CrazyCircuits/blob/master/Circuit-Kits/Modules/2x2-LED-RGB-TH-4PIN/2x2-LED-RGB-TH-4PIN-v1.1.pdf">View</a>|<a href="https://github.com/BrownDogGadgets/CrazyCircuits/raw/master/Circuit-Kits/Modules/2x2-LED-RGB-TH-4PIN/gerbers/2x2-LED-RGB-TH-4PIN-v1.1-gerbers.zip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">Zip</a>|<a href="https://github.com/BrownDogGadgets/CrazyCircuits/raw/master/Circuit-Kits/Modules/2x2-LED-RGB-TH-4PIN/2x2-LED-RGB-TH-4PIN-v1.1.zip">Zip</a>|Black||

### Speakers, Potentiometers, Motors, Servos, Screw Terminals, Sensors

|Project Name|Ver|Doc|Gerber|Complete|Mask|Top Preview|
|---|---|---|---|---|----|---|
|<a href="https://github.com/BrownDogGadgets/CrazyCircuits/tree/master/Circuit-Kits/Modules/2x4-Grove-Sensor">2x4 Seeed Grove Sensor</a>|v1.0|<a href="https://github.com/BrownDogGadgets/CrazyCircuits/blob/master/Circuit-Kits/Modules/2x4-Grove-Sensor/2x4-Grove-Sensor-v1.0.pdf">View</a>|<a href="https://github.com/BrownDogGadgets/CrazyCircuits/raw/master/Circuit-Kits/Modules/2x4-Grove-Sensor/gerbers/2x4-Grove-Sensor-v1.0-gerbers.zip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">Zip</a>|<a href="https://github.com/BrownDogGadgets/CrazyCircuits/raw/master/Circuit-Kits/Modules/2x4-Grove-Sensor/2x4-Grove-Sensor-v1.0.zip">Zip</a>|Purple||
|<a href="https://github.com/BrownDogGadgets/CrazyCircuits/tree/master/Circuit-Kits/Modules/2x4-Grove-Sensor-Inline">2x4 Seeed Grove Sensor (Inline)</a>|v1.0|<a href="https://github.com/BrownDogGadgets/CrazyCircuits/blob/master/Circuit-Kits/Modules/2x4-Grove-Sensor-Inline/2x4-Grove-Sensor-Inline-v1.0.pdf">View</a>|<a href="https://github.com/BrownDogGadgets/CrazyCircuits/raw/master/Circuit-Kits/Modules/2x4-Grove-Sensor-Inline/gerbers/2x4-Grove-Sensor-Inline-v1.0-gerbers.zip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">Zip</a>|<a href="https://github.com/BrownDogGadgets/CrazyCircuits/raw/master/Circuit-Kits/Modules/2x4-Grove-Sensor-Inline/2x4-Grove-Sensor-Inline-v1.0.zip">Zip</a>|Purple||
|<a href="https://github.com/BrownDogGadgets/CrazyCircuits/tree/master/Circuit-Kits/Modules/2x2-Screw-Terminal-3.5mm-Pitch">2x2 Screw Terminal 3.5mm Pitch</a>|v1.2|<a href="https://github.com/BrownDogGadgets/CrazyCircuits/blob/master/Circuit-Kits/Modules/2x2-Screw-Terminal-3.5mm-Pitch/2x2-Screw-Terminal-3.5mm-Pitch-v1.2.pdf">View</a>|<a href="https://github.com/BrownDogGadgets/CrazyCircuits/raw/master/Circuit-Kits/Modules/2x2-Screw-Terminal-3.5mm-Pitch/gerbers/2x2-Screw-Terminal-3.5mm-Pitch-v1.2-gerbers.z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">Zip</a>|<a href="https://github.com/BrownDogGadgets/CrazyCircuits/raw/master/Circuit-Kits/Modules/2x2-Screw-Terminal-3.5mm-Pitch/2x2-Screw-Terminal-3.5mm-Pitch-v1.2.zip">Zip</a>|Purple||
|<a href="https://github.com/BrownDogGadgets/CrazyCircuits/tree/master/Circuit-Kits/Modules/2x3-Screw-Terminal-3.5mm-Pitch">2x3 Screw Terminal 3.5mm Pitch</a>|v1.2|<a href="https://github.com/BrownDogGadgets/CrazyCircuits/blob/master/Circuit-Kits/Modules/2x3-Screw-Terminal-3.5mm-Pitch/2x3-Screw-Terminal-3.5mm-Pitch-v1.2.pdf">View</a>|<a href="https://github.com/BrownDogGadgets/CrazyCircuits/raw/master/Circuit-Kits/Modules/2x3-Screw-Terminal-3.5mm-Pitch/gerbers/2x3-Screw-Terminal-3.5mm-Pitch-v1.2-gerbers.z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">Zip</a>|<a href="https://github.com/BrownDogGadgets/CrazyCircuits/raw/master/Circuit-Kits/Modules/2x3-Screw-Terminal-3.5mm-Pitch/2x3-Screw-Terminal-3.5mm-Pitch-v1.2.zip">Zip</a>|Purple||
|<a href="https://github.com/BrownDogGadgets/CrazyCircuits/tree/master/Circuit-Kits/Modules/2x2-Push-Terminal-3mm-Pitch-SMT">2x2 Push Terminal 3mm Pitch SMT</a>|v1.1|<a href="https://github.com/BrownDogGadgets/CrazyCircuits/blob/master/Circuit-Kits/Modules/2x2-Push-Terminal-3mm-Pitch-SMT/2x2-Push-Terminal-3mm-Pitch-SMT-v1.1.pdf">View</a>|<a href="https://github.com/BrownDogGadgets/CrazyCircuits/raw/master/Circuit-Kits/Modules/2x2-Push-Terminal-3mm-Pitch-SMT/gerbers/2x2-Push-Terminal-3mm-Pitch-SMT-v1.1-gerbers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">Zip</a>|<a href="https://github.com/BrownDogGadgets/CrazyCircuits/raw/master/Circuit-Kits/Modules/2x2-Push-Terminal-3mm-Pitch-SMT/2x2-Push-Terminal-3mm-Pitch-SMT-v1.1.zip">Zip</a>|Purple||
|<a href="https://github.com/BrownDogGadgets/CrazyCircuits/tree/master/Circuit-Kits/Modules/2x3-Push-Terminal-3mm-Pitch-SMT">2x3 Push Terminal 3mm Pitch SMT</a>|v1.1|<a href="https://github.com/BrownDogGadgets/CrazyCircuits/blob/master/Circuit-Kits/Modules/2x3-Push-Terminal-3mm-Pitch-SMT/2x3-Push-Terminal-3mm-Pitch-SMT-v1.1.pdf">View</a>|<a href="https://github.com/BrownDogGadgets/CrazyCircuits/raw/master/Circuit-Kits/Modules/2x3-Push-Terminal-3mm-Pitch-SMT/gerbers/2x3-Push-Terminal-3mm-Pitch-SMT-v1.1-gerbers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">Zip</a>|<a href="https://github.com/BrownDogGadgets/CrazyCircuits/raw/master/Circuit-Kits/Modules/2x3-Push-Terminal-3mm-Pitch-SMT/2x3-Push-Terminal-3mm-Pitch-SMT-v1.1.zip">Zip</a>|Purple||
|<a href="https://github.com/BrownDogGadgets/CrazyCircuits/tree/master/Circuit-Kits/Modules/2x3-Mini-Potentiometer-3361P-SMT">2x3 Mini Potentiometer 3361P SMT</a>|v1.1|<a href="https://github.com/BrownDogGadgets/CrazyCircuits/blob/master/Circuit-Kits/Modules/2x3-Mini-Potentiometer-3361P-SMT/2x3-Mini-Potentiometer-3361P-SMT-v1.1.pdf">View</a>|<a href="https://github.com/BrownDogGadgets/CrazyCircuits/raw/master/Circuit-Kits/Modules/2x3-Mini-Potentiometer-3361P-SMT/gerbers/2x3-Mini-Potentiometer-3361P-SMT-v1.1-gerbe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">Zip</a>|<a href="https://github.com/BrownDogGadgets/CrazyCircuits/raw/master/Circuit-Kits/Modules/2x3-Mini-Potentiometer-3361P-SMT/2x3-Mini-Potentiometer-3361P-SMT-v1.1.zip">Zip</a>|Red||
|<a href="https://github.com/BrownDogGadgets/CrazyCircuits/tree/master/Circuit-Kits/Modules/2x3-Mini-Potentiometer-3386P-TH">2x3 Mini Potentiometer 3386P TH</a>|v1.2|<a href="https://github.com/BrownDogGadgets/CrazyCircuits/blob/master/Circuit-Kits/Modules/2x3-Mini-Potentiometer-3386P-TH/2x3-Mini-Potentiometer-3386P-TH-v1.2.pdf">View</a>|<a href="https://github.com/BrownDogGadgets/CrazyCircuits/raw/master/Circuit-Kits/Modules/2x3-Mini-Potentiometer-3386P-TH/gerbers/2x3-Mini-Potentiometer-3386P-TH-v1.2-gerbers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">Zip</a>|<a href="https://github.com/BrownDogGadgets/CrazyCircuits/raw/master/Circuit-Kits/Modules/2x3-Mini-Potentiometer-3386P-TH/2x3-Mini-Potentiometer-3386P-TH-v1.2.zip">Zip</a>|Red||
|<a href="https://github.com/BrownDogGadgets/CrazyCircuits/tree/master/Circuit-Kits/Modules/2x3-Potentiometer-P160K-TH">2x3 Potentiometer P160K TH</a>|v1.3|<a href="https://github.com/BrownDogGadgets/CrazyCircuits/blob/master/Circuit-Kits/Modules/2x3-Potentiometer-P160K-TH/2x3-Potentiometer-P160K-TH-v1.3.pdf">View</a>|<a href="https://github.com/BrownDogGadgets/CrazyCircuits/raw/master/Circuit-Kits/Modules/2x3-Potentiometer-P160K-TH/gerbers/2x3-Potentiometer-P160K-TH-v1.3-gerbers.zip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">Zip</a>|<a href="https://github.com/BrownDogGadgets/CrazyCircuits/raw/master/Circuit-Kits/Modules/2x3-Potentiometer-P160K-TH/2x3-Potentiometer-P160K-TH-v1.3.zip">Zip</a>|Red||
|<a href="https://github.com/BrownDogGadgets/CrazyCircuits/tree/master/Circuit-Kits/Modules/2x2-Servo-Header">2x2 Servo Header TH</a>|v1.2|<a href="https://github.com/BrownDogGadgets/CrazyCircuits/blob/master/Circuit-Kits/Modules/2x2-Servo-Header/2x2-Servo-Header-v1.2.pdf">View</a>|<a href="https://github.com/BrownDogGadgets/CrazyCircuits/raw/master/Circuit-Kits/Modules/2x2-Servo-Header/gerbers/2x2-Servo-Header-v1.2-gerbers.zip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">Zip</a>|<a href="https://github.com/BrownDogGadgets/CrazyCircuits/raw/master/Circuit-Kits/Modules/2x2-Servo-Header/2x2-Servo-Header-v1.2.zip">Zip</a>|Black||
|<a href="https://github.com/BrownDogGadgets/CrazyCircuits/tree/master/Circuit-Kits/Modules/2x3-Servo-Header">2x3 Male Servo Header TH</a>|v1.4|<a href="https://github.com/BrownDogGadgets/CrazyCircuits/blob/master/Circuit-Kits/Modules/2x3-Servo-Header/2x3-Servo-Header-v1.4.pdf">View</a>|<a href="https://github.com/BrownDogGadgets/CrazyCircuits/raw/master/Circuit-Kits/Modules/2x3-Servo-Header/gerbers/2x3-Servo-Header-v1.4-gerbers.zip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">Zip</a>|<a href="https://github.com/BrownDogGadgets/CrazyCircuits/raw/master/Circuit-Kits/Modules/2x3-Servo-Header/2x3-Servo-Header-v1.4.zip">Zip</a>|Black||
|<a href="https://github.com/BrownDogGadgets/CrazyCircuits/tree/master/Circuit-Kits/Modules/2x3-Female-Servo-Header">2x3 Female Servo Header TH</a>|v1.0|<a href="https://github.com/BrownDogGadgets/CrazyCircuits/blob/master/Circuit-Kits/Modules/2x3-Female-Servo-Header/2x3-Female-Servo-Header-v1.0.pdf">View</a>|<a href="https://github.com/BrownDogGadgets/CrazyCircuits/raw/master/Circuit-Kits/Modules/2x3-Female-Servo-Header/gerbers/2x3-Female-Servo-Header-v1.0-gerbers.zip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">Zip</a>|<a href="https://github.com/BrownDogGadgets/CrazyCircuits/raw/master/Circuit-Kits/Modules/2x3-Female-Servo-Header/2x3-Female-Servo-Header-v1.0.zip">Zip</a>|Black||
|<a href="https://github.com/BrownDogGadgets/CrazyCircuits/tree/master/Circuit-Kits/Modules/2x3-Speaker-TH-5mm-Pitch">2x3 Speaker Piezo TH 5mm Pitch</a>|v1.1|<a href="https://github.com/BrownDogGadgets/CrazyCircuits/blob/master/Circuit-Kits/Modules/2x3-Speaker-TH-5mm-Pitch/2x3-Speaker-TH-5mm-Pitch-v1.1.pdf">View</a>|<a href="https://github.com/BrownDogGadgets/CrazyCircuits/raw/master/Circuit-Kits/Modules/2x3-Speaker-TH-5mm-Pitch/gerbers/2x3-Speaker-TH-5mm-Pitch-v1.1-gerbers.zip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">Zip</a>|<a href="https://github.com/BrownDogGadgets/CrazyCircuits/raw/master/Circuit-Kits/Modules/2x3-Speaker-TH-5mm-Pitch/2x3-Speaker-TH-5mm-Pitch-v1.1.zip">Zip</a>|Black||
|<a href="https://github.com/BrownDogGadgets/CrazyCircuits/tree/master/Circuit-Kits/Modules/2x3-Speaker-SMT-11mm-Pitch">2x3 Speaker Piezo SMT 11mm Pitch</a>|v1.1|<a href="https://github.com/BrownDogGadgets/CrazyCircuits/blob/master/Circuit-Kits/Modules/2x3-Speaker-SMT-11mm-Pitch/2x3-Speaker-SMT-11mm-Pitch-v1.1.pdf">View</a>|<a href="https://github.com/BrownDogGadgets/CrazyCircuits/raw/master/Circuit-Kits/Modules/2x3-Speaker-SMT-11mm-Pitch/gerbers/2x3-Speaker-SMT-11mm-Pitch-v1.1-gerbers.zip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">Zip</a>|<a href="https://github.com/BrownDogGadgets/CrazyCircuits/raw/master/Circuit-Kits/Modules/2x3-Speaker-SMT-11mm-Pitch/2x3-Speaker-SMT-11mm-Pitch-v1.1.zip">Zip</a>|Black||
|<a href="https://github.com/BrownDogGadgets/CrazyCircuits/tree/master/Circuit-Kits/Modules/2x3-Vibe-Motor-TH">2x3 Vibe Motor TH</a>|v1.2|<a href="https://github.com/BrownDogGadgets/CrazyCircuits/blob/master/Circuit-Kits/Modules/2x3-Vibe-Motor-TH/2x3-Vibe-Motor-TH-v1.2.pdf">View</a>|<a href="https://github.com/BrownDogGadgets/CrazyCircuits/raw/master/Circuit-Kits/Modules/2x3-Vibe-Motor-TH/gerbers/2x3-Vibe-Motor-TH-v1.2-gerbers.zip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">Zip</a>|<a href="https://github.com/BrownDogGadgets/CrazyCircuits/raw/master/Circuit-Kits/Modules/2x3-Vibe-Motor-TH/2x3-Vibe-Motor-TH-v1.2.zip">Zip</a>|Black||

### Generic and Prototypable Modules 

These are for prototyping and reference only. 

**These are not suitable for wave solder manufacturing.**

|Project Name|Ver|Doc|Gerber|Complete|Top Preview|
|---|---|---|---|---|---|
|<a href="https://github.com/BrownDogGadgets/CrazyCircuits/tree/master/Circuit-Kits/Modules/2x2-LED-TH-5mm-Pitch">2x2 LED TH (5mm Pitch)</a>|v1.1|<a href="https://github.com/BrownDogGadgets/CrazyCircuits/blob/master/Circuit-Kits/Modules/2x2-LED-TH-5mm-Pitch/2x2-LED-TH-5mm-Pitch-v1.1.pdf">View</a>|<a href="https://github.com/BrownDogGadgets/CrazyCircuits/raw/master/Circuit-Kits/Modules/2x2-LED-TH-5mm-Pitch/gerbers/2x2-LED-TH-5mm-Pitch-v1.1-gerbers.zip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">Zip</a>|<a href="https://github.com/BrownDogGadgets/CrazyCircuits/raw/master/Circuit-Kits/Modules/2x2-LED-TH-5mm-Pitch/2x2-LED-TH-5mm-Pitch-v1.1.zip">Zip</a>||
|<a href="https://github.com/BrownDogGadgets/CrazyCircuits/tree/master/Circuit-Kits/Modules/2x3-LED-TH-5mm-Pitch-Magnet">2x3 LED TH (5mm Pitch) (Magnet-friendly)</a>|v1.1|<a href="https://github.com/BrownDogGadgets/CrazyCircuits/blob/master/Circuit-Kits/Modules/2x3-LED-TH-5mm-Pitch-Magnet/2x3-LED-TH-5mm-Pitch-Magnet-v1.1.pdf">View</a>|<a href="https://github.com/BrownDogGadgets/CrazyCircuits/raw/master/Circuit-Kits/Modules/2x3-LED-TH-5mm-Pitch-Magnet/gerbers/2x3-LED-TH-5mm-Pitch-Magnet-v1.1-gerbers.zip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">Zip</a>|<a href="https://github.com/BrownDogGadgets/CrazyCircuits/raw/master/Circuit-Kits/Modules/2x3-LED-TH-5mm-Pitch-Magnet/2x3-LED-TH-5mm-Pitch-Magnet-v1.1.zip">Zip</a>||
|<a href="https://github.com/BrownDogGadgets/CrazyCircuits/tree/master/Circuit-Kits/Modules/2x2-Generic-2.54mm-Pitch">2x2 Generic 2.54mm Pitch</a>|v1.1|<a href="https://github.com/BrownDogGadgets/CrazyCircuits/blob/master/Circuit-Kits/Modules/2x2-Generic-2.54mm-Pitch/2x2-Generic-2.54mm-Pitch-v1.1.pdf">View</a>|<a href="https://github.com/BrownDogGadgets/CrazyCircuits/blob/master/Circuit-Kits/Modules/2x2-Generic-2.54mm-Pitch/gerbers/2x2-Generic-2.54mm-Pitch-v1.1-gerbers.zip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">Zip</a>|<a href="https://github.com/BrownDogGadgets/CrazyCircuits/blob/master/Circuit-Kits/Modules/2x2-Generic-2.54mm-Pitch/2x2-Generic-2.54mm-Pitch-v1.1.zip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">Zip</a>||
|<a href="https://github.com/BrownDogGadgets/CrazyCircuits/tree/master/Circuit-Kits/Modules/2x2-Generic-3.5mm-Pitch">2x2 Generic 3.5mm Pitch</a>|v1.0|<a href="https://github.com/BrownDogGadgets/CrazyCircuits/blob/master/Circuit-Kits/Modules/2x2-Generic-3.5mm-Pitch/2x2-Generic-3.5mm-Pitch-v1.0.pdf">View</a>|<a href="https://github.com/BrownDogGadgets/CrazyCircuits/raw/master/Circuit-Kits/Modules/2x2-Generic-3.5mm-Pitch/gerbers/2x2-Generic-3.5mm-Pitch-v1.0-gerbers.zip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">Zip</a>|<a href="https://github.com/BrownDogGadgets/CrazyCircuits/blob/master/Circuit-Kits/Modules/2x2-Generic-3.5mm-Pitch/2x2-Generic-3.5mm-Pitch-v1.0.zip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">Zip</a>||
|<a href="https://github.com/BrownDogGadgets/CrazyCircuits/tree/master/Circuit-Kits/Modules/2x2-Generic-5mm-Pitch">2x2 Generic 5mm Pitch</a>|v1.1|<a href="https://github.com/BrownDogGadgets/CrazyCircuits/blob/master/Circuit-Kits/Modules/2x2-Generic-5mm-Pitch/2x2-Generic-5mm-Pitch-v1.1.pdf">View</a>|<a href="https://github.com/BrownDogGadgets/CrazyCircuits/blob/master/Circuit-Kits/Modules/2x2-Generic-5mm-Pitch/gerbers/2x2-Generic-5mm-Pitch-v1.1-gerbers.zip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">Zip</a>|<a href="https://github.com/BrownDogGadgets/CrazyCircuits/blob/master/Circuit-Kits/Modules/2x2-Generic-5mm-Pitch/2x2-Generic-5mm-Pitch-v1.1.zip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">Zip</a>||
|<a href="https://github.com/BrownDogGadgets/CrazyCircuits/tree/master/Circuit-Kits/Modules/2x3-Generic-2.54mm-Pitch-Magnet">2x3 Generic 2.54mm Pitch (Magnet-friendly)</a>|v1.1|<a href="https://github.com/BrownDogGadgets/CrazyCircuits/blob/master/Circuit-Kits/Modules/2x3-Generic-2.54mm-Pitch-Magnet/2x3-Generic-2.54mm-Pitch-Magnet-v1.1.pdf">View</a>|<a href="https://github.com/BrownDogGadgets/CrazyCircuits/blob/master/Circuit-Kits/Modules/2x3-Generic-2.54mm-Pitch-Magnet/gerbers/2x3-Generic-2.54mm-Pitch-Magnet-v1.1-gerber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">Zip</a>|<a href="https://github.com/BrownDogGadgets/CrazyCircuits/blob/master/Circuit-Kits/Modules/2x3-Generic-2.54mm-Pitch-Magnet/2x3-Generic-2.54mm-Pitch-Magnet-v1.1.zip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">Zip</a>||
|<a href="https://github.com/BrownDogGadgets/CrazyCircuits/tree/master/Circuit-Kits/Modules/2x3-Generic-3.5mm-Pitch-Magnet">2x3 Generic 3.5mm Pitch (Magnet-friendly)</a>|v1.0|<a href="https://github.com/BrownDogGadgets/CrazyCircuits/blob/master/Circuit-Kits/Modules/2x3-Generic-3.5mm-Pitch-Magnet/2x3-Generic-3.5mm-Pitch-Magnet-v1.0.pdf">View</a>|<a href="https://github.com/BrownDogGadgets/CrazyCircuits/raw/master/Circuit-Kits/Modules/2x3-Generic-3.5mm-Pitch-Magnet/gerbers/2x3-Generic-3.5mm-Pitch-Magnet-v1.0-gerbers.z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">Zip</a>|<a href="https://github.com/BrownDogGadgets/CrazyCircuits/blob/master/Circuit-Kits/Modules/2x3-Generic-3.5mm-Pitch-Magnet/2x3-Generic-3.5mm-Pitch-Magnet-v1.0.zip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">Zip</a>||
|<a href="https://github.com/BrownDogGadgets/CrazyCircuits/tree/master/Circuit-Kits/Modules/2x3-Generic-5mm-Pitch-Magnet">2x3 Generic 5mm Pitch (Magnet-friendly)</a>|v1.1|<a href="https://github.com/BrownDogGadgets/CrazyCircuits/blob/master/Circuit-Kits/Modules/2x3-Generic-5mm-Pitch-Magnet/2x3-Generic-5mm-Pitch-Magnet-v1.1.pdf">View</a>|<a href="https://github.com/BrownDogGadgets/CrazyCircuits/blob/master/Circuit-Kits/Modules/2x3-Generic-5mm-Pitch-Magnet/gerbers/2x3-Generic-5mm-Pitch-Magnet-v1.1-gerbers.zip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">Zip</a>|<a href="https://github.com/BrownDogGadgets/CrazyCircuits/blob/master/Circuit-Kits/Modules/2x3-Generic-5mm-Pitch-Magnet/2x3-Generic-5mm-Pitch-Magnet-v1.1.zip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">Zip</a>||
|<a href="https://github.com/BrownDogGadgets/CrazyCircuits/tree/master/Circuit-Kits/Modules/1x2-Generic-1206-SMT">1x2 Generic 1206 SMT</a>|v1.2|<a href="https://github.com/BrownDogGadgets/CrazyCircuits/blob/master/Circuit-Kits/Modules/1x2-Generic-1206-SMT/1x2-Generic-1206-SMT-v1.2.pdf">View</a>|<a href="https://github.com/BrownDogGadgets/CrazyCircuits/blob/master/Circuit-Kits/Modules/1x2-Generic-1206-SMT/gerbers/1x2-Generic-1206-SMT-v1.2-gerbers.zip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">Zip</a>|<a href="https://github.com/BrownDogGadgets/CrazyCircuits/blob/master/Circuit-Kits/Modules/1x2-Generic-1206-SMT/1x2-Generic-1206-SMT-v1.2.zip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">Zip</a>||
|<a href="https://github.com/BrownDogGadgets/CrazyCircuits/tree/master/Circuit-Kits/Modules/2x2-Generic-1206-SMT">2x2 Generic 1206 SMT</a>|v1.1|<a href="https://github.com/BrownDogGadgets/CrazyCircuits/blob/master/Circuit-Kits/Modules/2x2-Generic-1206-SMT/2x2-Generic-1206-SMT-v1.1.pdf">View</a>|<a href="https://github.com/BrownDogGadgets/CrazyCircuits/blob/master/Circuit-Kits/Modules/2x2-Generic-1206-SMT/gerbers/2x2-Generic-1206-SMT-v1.1-gerbers.zip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">Zip</a>|<a href="https://github.com/BrownDogGadgets/CrazyCircuits/blob/master/Circuit-Kits/Modules/2x2-Generic-1206-SMT/2x2-Generic-1206-SMT-v1.1.zip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">Zip</a>||

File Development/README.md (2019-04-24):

# Creating New Circuits and Modules

This section is for developers to create new Crazy Circuits modules in KiCad 5.

### Submit a Module Request

If you don't use KiCad and want us to create a module for you, please follow the instructions here:

	&raquo; [Submit a Module Request](submit-a-module-request.md).

## Table of Contents

We love contributions! Here's how to do it:

1. Install KiCad and git
1. Fork the Crazy Circuits GitHub Repository
1. Name the New Module
1. Unpack the new-project.zip into that folder
1. Rename and edit as needed
1. Design Decisions and the KiCad Libraries
1. Create the schematic and any new symbols
   1. Schematic Style
   1. Art and Logos
   1. Working with Component Symbols
   1. Creating a New Symbol
   1. Edit the Symbol Fields
   1. Generate the Netlist
1. Create the layout and any new footprints
   1. Design Rules and Layer Setup
   1. Design Decisions
   1. Footprint Guidelines
1. Edit the fabrication notes to specify module color
1. Fill in the description section of the README
1. Optionally create the BOM, gerbers, and pos file
1. Otherwise, we will auto-generate the docs
1. Submit a pull request

## How to Contribute

### 1. Install KiCad and git

This guide assumes you're comfortable with KiCad, GitHub, and git. 

KiCad is a free, open source schematic capture and board layout tool that can be downloaded for Linux, Mac, and Windows. [Get KiCad here](kicad-pcb.org). The Crazy Circuits project prefers modules made with KiCad 5. 

Complete documentation can be found at [KiCad docs](http://docs.kicad-pcb.org/).

If you don't use KiCad and want us to create a module for you, please follow the instructions here:

	&raquo; [Submit a Module Request](submit-a-module-request.md).

### 2. Fork the Crazy Circuits GitHub Repository

First, fork your the CrazyCircuits repository to your own GitHub account. It's easiest for us if you make changes to that forked repository and then submit a pull request.



Clone your forked repository to your local machine. On the command line, this looks something like:

	`git clone https://github.com/YOURNAME/CrazyCircuits.git`

### 3. Name the New Module

We've automated how we generate the project documentation. If you name the module in a particular way, you only have to create the design files and edit the project README before submitting the pull request. We will run a one-liner to create all the output zip files, output BOMs, and PDF documentation. 

The name of the module's folder and files should have dashes instead of spaces. 

The longform name of the module for the documentation should follow the same 

Versions are tracked separately and should not be added to the module name.

In general, names should start with the size/shape of the Lego-compatible holes. Then go from most general to most specific, up to and including the part number and SMT/TH if necessary. If this is a version on an existing module, copy that module naming pattern and adjust only the minimum necessary, such as changing SMT to TH. 

**Examples:**

| Folder/Files Name | Longform Module Name |
| --- | --- |
| 2x4-Grove-Sensor | 2x4 Seeed Grove Sensor Module |
| 2x2-Screw-Terminal-3.5mm-Pitch | 2x2 Screw Terminal 3.5mm-Pitch Module |
| 2x2-LED-Blue-SMT-Limited | 2x2 Current-Limited Blue SMT LED Module |
| 2x3-Dark-Detector | 2x3 Dark Detector Module |
| 3x4-ATtiny85-8DIP-Breakout | 3x4 ATTiny85 8DIP Breakout Module |
| 2x3-Mini-Potentiometer-3361P-SMT | 2x3 Mini Potentiometer 3361P SMT Module |
| 2x3-Mini-Potentiometer-3386P-TH  | 2x3 Mini Potentiometer 3386P TH Module  |
| 5x11-Arduino-Nano-Robot-Version  | 5x22 Arduino Nano Robot Breakout Module |
| 7x11-RasPi-Zero-Breakout | 7x11 RasPi Zero Breakout Module |

### 4. Copy the new-project.zip into that folder

We provide a module template that includes a blank KiCad 5 project template, the README, and a proj.json file with all the information we'll need to automatically generate all the project documentation.  

Create a folder in  `CrazyCircuits/Circuit-Kits/Modules` using the folder module name.

New Module

Unpack the contents of [newproject.zip](templates/newproject.zip) into this new folder.

Unpacked project template

### 5. Rename and edit as needed

First, rename the three KiCad project files.

| Default | Example Name |
| --- | --- |
| crazy.kicad_pcb | 2x4-LED-Example-Project-TH.kicad_pcb |
| crazy.pro | 2x4-LED-Example-Project-TH.pro |
| crazy.sch | 2x4-LED-Example-Project-TH.sch |

Next, set up the library locations to reflect the absolute path the CrazyCircuits repository on your machine.

Because KiCad doesn't support relative library paths, all the files currently have library paths reflecting the Brown Dog Gadgets development environment:`/home/wicker/proj/CrazyCircuits`.

1. Open the `.pro` file and replace `/home/wicker/proj` on line 40 with your path.  Save and close the file.
2. Open the `fp-lib-table` file, do the same on lines 2 and 3.
3. Open the `sym-lib-table` file and do the same on line 2.

Finally, manually open and edit the following files in the text editor of your choice.

#### proj.json

1. Change line 4: "date_create" to today's date in the same `DD MON YEAR` format.
2. Change line 5: "date_update" to today's date in the same `DD MON YEAR` format.
3. Change line 11: "proj_name" to the file/folder name.
4. Change line 15: "title" to your longform module name.

#### README.md

1. Change the module name on line 2 to your longform module name. 

2. There's no need to change the updated date if you don't want to. This will be updated automatically when we generate all the project docs. 

3. Replace the line containing `THIS IS THE DESCRIPTION SECTION...` with a short (or long!) description of the module. Here are a couple of examples: 

   ```
   This robot controller module comes with an Arduino Nano, four servo headers, and two analog headers.
   
   We recommend buying one 20-pin Harwin connector (P/N M20-9992046) and breaking it into pieces to place the six male headers.
   ```

   ```
   This simple tilt switch is either closed or open, depending on which end of the tube the ball has rolled down.
   ```

   ```
   Surface mount RGB LED with a common anode. Connect the Common (C) to 3.3V.
   ```

### 6. Design Decisions and the KiCad Libraries

First, it's important to understand that KiCad separates the schematic and component symbols from the board layout and component footprints. 

We at Crazy Circuits put all the bill of material information in the schematic symbols. We then play somewhat fast and loose with our footprint library. Each module is small and easy to check by hand, so we have made some inadvisable design choices ... please don't use existing module footprints and layouts as an example of best practices. Please follow this guide instead.

Schematic symbols can be found in the crazy.lib and crazy.dcm files. Do not edit these files by hand. 

Component footprints are individual .kicad_mod files in the Crazy_Circuits.pretty and Crazy_NonLego.pretty libraries. Do not edit these files by hand. 

### 7. Create the schematic and any new symbols

#### Schematic Style

The schematics are often included in the educational materials so we prefer a fully wired schematic where all the components are laid out spatially in a way easily understood by kids who are learning electronics. We may not use the entire schematic in the final educational materials, but the more info you give us here, the more the curriculum folks have to work with.

Here are some examples of the style we're looking for:

Example schematic of the Feather Huzzah breakout

Example schematic of the Neopixel RGB LED

Example schematic of a switch

Example schematic of a pushbutton switch

#### Art and Logo Modules

If you're creating a module without any components, place a line of text in the middle of the schematic and generate a netlist so we know the schematic is empty on purpose. 

Text to confirm an empty schematic

Create a netlist

#### Working with Component Symbols

We use typical KiCad symbols in terms of look. We recommend opening up the schematic editor and adding symbols to quickly sort through the library. 

The most important thing to know is that we add our bills of materials information to our symbols using the built-in KiCad 'fields' tool. A complete symbol looks like this: 

Symbol with all additional BOM fields filled in   	

When making a module that will use a new part we don't have in our library, the first step is to identify the manufacturer, the manufacturer part number, a vendor with the item currently in stock, and the vendor part number. We frequently use Digikey and Mouser, but also commonly Adafruit and Sparkfun. 

#### Create a New Symbol

To create a new symbol, it's easiest to start with a similar symbol that has all the fields we're looking for. Find this reference symbol and add it to the schematic:

Add a reference symbol to the schematic

Hover over the symbol and press Ctrl+E to open this symbol in the library symbol editor.

Open the symbol in the library editor

The first order of business is to duplicate this symbol and rename it. For this example, let's say we wanted to add a 470-ohm resistor in the same 5%, 1/4W family as this 100-ohm resistor. Find and right click on the symbol in the list on the left.  

Duplicate the symbol in the library

The green entry in the left-hand list shows the symbol you're currently editing. In this case, it's still the original 100-ohm resistor. Clicking on Duplicate Symbol creates a new, black, bold symbol entry in the list that ends in `_0` with an asterisk next to it. This just means that symbol has unsaved changes. 

Because we want to edit that new 100-ohm resistor symbol (to make it a 470-ohm resistor), double click on the bolded black symbol entry. When it turns green, you know it's the one that's open in your editor.

Duplicate the symbol in the library

Change this symbol's value in the editor window by using 'e' over the value text. Follow the same sort of naming scheme. In this case, just change 100 to 470, since all other values will be the same. 

Rename the value of the duplicate symbol

Click OK and the symbol will show the new value in both the editor and the left-hand symbol list.

Rename the value of the duplicate symbol

 Hit Ctrl+S or use the GUI menu to save the symbol.

#### Edit the symbol fields 

The pile of gray text strings at the bottom is actually the set of fields. You can hover and hit 'e' to edit them one by one, but it's easier to open the fields editor by clicking on the T symbol in the top menu bar.

Click the symbol for the fields editor

Use the mouse or the arrow keys to edit each of the fields. 

Fields editor in action

The last three fields contain information for the automated assembly process. The XSize_mils and YSize_mils are the dimensions of the part in mils (thousandths of an inch), and this can be approximate from the datasheet. The type is either `th` for 'through-hole' or `smt` for 'surface mount'. 

For art with no corresponding assembly requirements, such as a logo, use `dnp` for 'do not place'.

#### Generate the Netlist

When the symbols are created, placed, and connected with wires according to the examples above, the last step is to create the netlist. Click on the green 'NET' symbol in the top bar and 'Generate Netlist'.

Create a netlist

Then you can save and exit the schematic editor.

### 8. Create the layout and any new footprints

*The project template comes with a set of design rules that we've found to work nicely with our most common fabricators and with some of KiCad's auto layout quirks. We've also included a text box containing the Fabrication Notes on the Dwgs.User layer.* 

All modules should have components only on one side, hereafter referred to as the "top" side.

To start, get an idea of the size of the components and draw out the rough layout of the module on a piece of paper or a dry erase board. Figure out where VCC and GND should go. Signals should only be broken out on the outer ring of the module, so as to be compatible with conductive tape in projects. 

Remember, these modules should be friendly and easy to use for kids and their teachers.   

#### Design Rules and Layer Setup

Our KiCad template comes with design rules included. You can find them under `Setup` in the top menu.

It's important to know that 0.006 inches is also called 6 mils, which is the same as 6 thousandths of an inch, and both are equivalent to 0.1524 mm. We will use mils in this document. 

While the minimum track width is 6 mils in the design rules for trace minimum, we recommend a 10 mils minimum and have set that as a default in the net classes editor. There shouldn't be a need to edit either of these templates, but the following screenshots show the default settings just in case you need them.

Global Design Rules

Net Classes Editor

KiCad's layout editor lets you show and hide layers while you're editing. We expect info on all of the layers on the next screenshot, and this guide will refer to the layers according to their names as shown here:

Layer setup with 'layout' and 'items' tabs.

#### Design Decisions

There are two ways to approach making a new module. 

**For the first way**, you can make one footprint for the entire module, which we prefer, but which is more complicated. You'll open a generic module in the KiCad footprint editor, save it as the new name of your module, and add the component footprints, copper routing, and any silk by hand to the module. When saved, you can go back to the KiCad layout editor and add the whole module as a component. Doing it this way means the Design Rules Checker will not work, so you have to check against the design rules by hand. 

That's obviously a lot more complicated for a first-time KiCad designer, so we totally accept the second way!

**For the second way**, you can create the component footprints you need in the Crazy_NonLego library, then go back to the KiCad layout tool and add a generic Lego-compatible module from the Crazy_Circuits library, add those added Crazy_NonLego components, and wire them up in the KiCad layout tool with the 'x' command. The footprint pads have to match the expected pads from the schematic symbols (through the netlist) and you'll be able to use the Design Rules Checker.   

#### Footprint Guidelines

In either case, here are some module guidelines. 

We remap the hotkeys so 'd' instead of 'bksp' is delete, because it's right in the home row and easier to hit.   

##### License

All modules should be released under the CERN Open Hardware License v1.2.

##### Pads and Drills

The easiest thing is to set KiCad to use millimeters, which you can do by clicking 'mm' on the left menu.

The holes for Lego studs must be 4.98mm diameter.

Minimum total Lego hole total annular ring diameter is 6mm.

Verify lowest leftmost pad is at the origin

##### New Lego-Compatible Module

Even if you're making a totally new generic Lego-compatible module footprint because you need a new size that we don't have, it's best to start with one that's most of the way there. 

For example, if you need a 2x6, open a 2x3 and rename it to be the generic 2x6. Once you set the custom user grid size, you can just select the 2x3 pads, duplicate with Ctrl+D, and move them along the grid into the correct position.

Set the KiCad layout grid size to 8mm by going to `View > Grid Settings` in the top menu: 

Set custom grid

You can set the KiCad grid by right clicking in the background and choosing  `Grid > Custom User Grid`:

Use the custom grid

The big Lego-compatible holes should always be centered on grid lines. The origin (where the blue lines of the x and y axis cross) should be centered in the lowest leftmost hole. Many of our modules are not currently set up that way, but we'd appreciate if all new modules are.

Module orientation on the grid

To verify, click 'e' to edit the pad properties of the lowest leftmost pad and make sure its origin is at 0,0. You can also verify the size of the pad is 6mm (hole + both sides of the annular ring) and the hole itself is a circular plated through-hole of width 4.98mm.

Verify lowest leftmost pad is at the origin

##### Silk Markings

All modules will have white silk.

We designate the VCC, VIN, other reference high voltage pin, or 'pin 1' of a bidirectional part in white silk with a cross (+) or explicitly with the name of the signal (VIN, VCC), and so on.

We designate the reference ground or the 'pin 2' of a bidirectional part with white silk. Add a graphic line on the F.Silk layer with thickness of 7 mm and cover this pin or pins, extending all the way to the edge of the board. KiCad will remove any silk from exposed copper automatically, so don't worry about covering them. 

If there are only two pins on a part, you can just mark the ground side.

A good example module for both silk and mask is the `SWITCH-12mm-SQUARE-B3FS-4000-SMT-2x2` module in the Crazy_Circuits footprint library. It demonstrates some interesting silk, copper, and mask adjustments to accommodate a surface mount part.

The holes are not plated in this module, because the surface mount pads made that impossible.

Example

##### Mask Guidelines

The template comes with a preset Pad-to-Mask clearance of 10 mils (0.01 inches or 0.254 mm) to accommodate a range of fab house tolerances. 

Any marks on the F.Mask or B.Mask layers are interpreted as *negative*. That is, solder mask will be placed everywhere except for where those markings are. All pads should have F.Mask and B.Mask markings included by default, which exposes the copper annular ring and allows kids to connect to the signals with conductive tape, conductive thread, or alligator clips. 

If you have a surface mount part, you must leave 30 mils of mask as a solder dam between any surface mount pad and any Lego-compatible plated hole. Otherwise, the solder may flow from the surface mount pads into the hole and make it so the module can't fit down onto the Lego block.  

To make a solder dam, hit 'e' while hovering over that pad and uncheck the F.Mask box on that pad. 

Uncheck F.Mask on a pad

Then use the `Add graphic arc` tool

Add graphic arc 

With the grid at some larger size so you can start at the center of the pad, add the graphic arc to expose the copper ring. One of the white squares on the arc will allow you to make the diameter larger or smaller, and the other will allow you to cover more of the ring. The arc should have a thickness of 0.5 mm. 

Once you've placed the arc for the first time, lowering the grid setting to 1 or 2 mils will let you have more fine control on placement of the mask.

Half arc F.Mask 1mm to expose copper ring

### 9. Edit the fabrication notes to specify module color

The fabrication notes included on the Dwgs.User layer are the same for all modules, except for the mask color, which depends on the type of module.

| Mask Color | **Module Purpose** |
| --- | --- |
| Red | Inputs: Buttons, Switches, Photocells, Cap Touch |
| Blue | Logos, Art |
| Orange | Power: Batteries, USB |
| Black | Outputs: LEDs, Lamps, Speakers, Servos, Motors, Buzzers |
| Green | Microcontrollers |
| Purple | Connectors: Push Terminals, Screw Terminals, Breakout Headers |

Edit the Fabrication Notes and change the words `ANY COLOR` in item #6 to be the actual module color.

```
FABRICATION NOTES

1. THIS IS A 2 LAYER BOARD. 
2. EXTERNAL LAYERS SHALL HAVE 1 OZ COPPER.
3. MATERIAL: FR4 AND 0.062 INCH +/- 10% THICK.
4. BOARDS SHALL BE ROHS COMPLIANT. 
5. MANUFACTURE IN ACCORDANCE WITH IPC-6012 CLASS 2
6. MASK: BOTH SIDES OF THE BOARD SHALL HAVE 
   SOLDER MASK (ANY COLOR) OVER BARE COPPER. 
7. SILK: BOTH SIDES OF THE BOARD SHALL HAVE 
   WHITE SILKSCREEN. DO NOT PLACE SILK OVER BARE COPPER.
8. FINISH: ENIG.
9. MINIMUM TRACE WIDTH - 0.006 INCH.
   MINIMUM SPACE - 0.006 INCH.
   MINIMUM HOLE DIA - 0.013 INCH. 
10. MAX HOLE PLACEMENT TOLERANCE OF +/- 0.003 INCH.
11. MAX HOLE DIAMETER TOLERANCE OF +/- 0.003 INCH AFTER PLATING.
12. PANELIZING: V-SCORE ONLY. 
   DO NOT USE SUPPORT TABS OR MOUSEBITES.
```

The example below is a coin cell battery module (Power type) so the mask color should be orange:

Fabrication Notes example

### 10. Fill in the description section of the README

If you haven't already, update the README description with anything you want the end users to know. Keep in mind that many of the folks using modules are teachers and students! Make it simple, clear, and helpful. 

Consider noting whether this module takes 3.3V or 5V, and if there are any external parts (like resistors) that are recommended with higher voltages. We'll also probably adjust this when we review the pull request, so don't worry too much about it.

### 11. Optionally create the gerbers

You can create them from the board layout screen by choosing `File > Plot`.  Make sure the output directory is set to `gerbers` and then click on `Plot` .

KiCad Plot panel to generate gerbers

To generate the drills file, click on `Generate Drill Files...` at the bottom of the Plot panel. Make sure the output directory is the same and then click `Generate Drill File`. 

KiCad Plot panel to generate drills

You can double check the gerbers in `gerbv`, a free and open source gerber viewer, or in KiCad's gerber viewer. OSH Park's gerber previews are pretty handy and user friendly -- just zip up the gerbers and drill file, and upload the zip file at [oshpark.com](http://oshpark.com). You don't have to save the project to view the image previews, but they're helpful to give you an idea about how the board will look. 

### 12. We will auto-generate the docs

We will generate the bill of materials, a set of gerbers which will overwrite the ones you create, combine the files into zips based particular vendor requirements, automatically create formatted PDFs. 

If you're curious, the process has been open sourced at [KiFisher](https://github.com/wickerbox/KiFisher). We use gerbv to generate preview images, Pandoc to create PDFs, and the whole thing's written in Python.

### 13. Submit a pull request

When you're ready for a review, send us a pull request. Log into GitHub to the CrazyCircuits repository under your account. Click on the Pull Request tab and then choose New Pull Request.

Submit a pull request

Select 'master' for BrownDogGadgets/CrazyCircuits and select your local branch with your new module.

Compare the Pull Request

Click `Create Pull Request` and fill in as much information in the comment box as you want: who you are, if you have a particular project in mind, if there are any design decisions you had to make (such as if the surface mount pads made layout difficult), and so on.

Compare the Pull Request

Click `Create Pull Request` one last time and we'll be in touch as soon as possible, probably within one or two business days. If you haven't heard from us in a few days, please add a comment and keep after us. Don't ever feel like you're bugging us -- on the contrary, we're excited that other people are getting value out of this project! 

If you have any questions, send an email to help@browndoggadgets.com and we'll do our best to help!

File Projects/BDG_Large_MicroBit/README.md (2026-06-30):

# BDG Large MicroBit

We've provided the HEX files `BDG_Large_MicroBit.ino.uf2` and `BDG_Large_MicroBit_Flipped.ino.uf2` if you just want to load the firmware and get it working.

We've also provided the Arduino sketch `BDG_Large_MicroBit.ino` if you want to make any changes.

Full build guide: https://learn.browndoggadgets.com/Guide/3D+Printed+(Large)+Micro:Bit/934 

Wiring Diagram

---

Brown Dog Gadgets  
https://www.browndoggadgets.com/.

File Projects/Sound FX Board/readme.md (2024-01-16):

# Sound FX Board

This project allows you to use the Crazy Circuits Invention Board (or Teensy LC) to create a capacitive touch sound wall. We use a cheap YX5300 mp3 module to play MP3 or WAV files.

You can find a full write up of this project on our website as well as Instructables.com. We also have a YouTube video you can watch that shows how to build the thing.

Full build instructions: https://learn.browndoggadgets.com/Guide/MP3+Playing+Sound+FX+Wall/176

YouTube Video Build: https://www.youtube.com/watch?v=dt47v8oeJfE

Sound Wall

All the resources are found in the ZIP file. The code and test files set up in folders. Download that to get started.

The code is set up so that certain pins play certain files. We have them set up with a 1 second delay after each sound effect is triggered. You can change that length if you really want to. You can also change the sensitivity of the capacitive touch feature. This is handy if you want to trigger a touch point BEHIND something, like a sheet of paper or a vinyl sticker.

Download the `Test Sound Effects` folder and copy all the folders inside it to your micro SD card. Format the card as MS-DOS (FAT32). To change the sound effect just delete the test .WAV file in each folder and replace it with your own MP3 or WAV file.

**For macOS users:** You'll need to download the DotClean Application: https://github.com/raster/DotClean

We use Bare Conductive paint as our touch points, however most anything conductive will work. You could just make a simple shape with conductive tape and the place paper over the top of it or even a vinyl sticker.

---

Brown Dog Gadgets

https://www.browndoggadgets.com/

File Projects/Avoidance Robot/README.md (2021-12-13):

# Avoidance Robot

Avoidance Robot

An Avoidance Robot built with Crazy Circuits components and LEGO parts.

Full build guide here: https://www.instructables.com/id/Obstacle-Avoiding-LEGO-Robot/

Electronic Parts Needed:
* 1 x [Crazy Circuits Robotics Board](https://www.browndoggadgets.com/collections/new-crazy-circuits-kits/products/crazy-circuits-robotics-board)
* 2 x [Brick Compatible Continuous Rotation 360 Degree Servo](https://www.browndoggadgets.com/products/brick-compatible-360-degree-servo)
* 1 x HC-SR04 Ultrasonic Distance Sensor
* 1 x USB Power Bank

We used the following LEGO parts, but you can use other parts as you see fit:

* 1 x [LEGO Wedge Belt Wheel (4185 / 49750)](https://www.brickowl.com/catalog/lego-wedge-belt-wheel-4185-49750)
* 1 x [LEGO EV3 Technic Ball Pivots Set 5003245](https://www.brickowl.com/catalog/lego-ev3-technic-ball-pivots-set-5003245)
* 1 x [LEGO Technic Cross Block Beam 3 with Four Pins (48989 / 65489)](https://www.brickowl.com/catalog/lego-technic-cross-block-beam-3-with-four-pins-48989-65489)
* 1 x [LEGO Technic Brick 1 x 6 with Holes (3894)](https://www.brickowl.com/catalog/lego-technic-brick-1-x-6-with-holes-3894)
* 4 x [LEGO Axle 4 with End Stop (87083)](https://www.brickowl.com/catalog/lego-axle-4-with-end-stop-87083)
* 4 x [LEGO Half Bushing (32123 / 42136)](https://technicforall.brickowl.com/store/lego-half-bushing-32123-42136)
* 4 x [LEGO Brick 2 x 2 Round (3941 / 6143)](https://technicforall.brickowl.com/store/lego-brick-2-x-2-round-3941-6143)
* 1 x [LEGO Plate 6 x 12 (3028)](https://www.brickowl.com/catalog/lego-plate-6-x-12-3028)
* Variety of micellaneous LEGO pieces

The Arduino sketch `AvoidanceRobot` is included.

You will also need the NewPing library, which can be found here: https://bitbucket.org/teckel12/arduino-new-ping/wiki/Home

---

Brown Dog Gadgets

https://www.browndoggadgets.com/

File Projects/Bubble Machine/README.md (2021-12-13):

# Bubble Machine



A LEGO-based Bubble Machine utilizing the Crazy Circuits Bit Board along with a servo and DC motor. You can control it using an Adafruit Clue or a micro:bit

Parts needed:
* 1 x Crazy Circuits Bit Board (Coming Soon!)
* 1 x [Adafruit Clue](https://www.adafruit.com/product/4500) - or - [micro:bit](https://microbit.org/buy/)
* 1 x [Roll of 1/8" Maker Tape](https://www.browndoggadgets.com/products/nylon-conductive-tape)
* 1 x [Brick Compatible 270 Degree Servo](https://www.browndoggadgets.com/products/brick-compatible-270-degree-servo)
* 1 x [Crazy Circuits Standard Pushbutton Chip](https://www.browndoggadgets.com/products/1x3-pushbutton-chip)
* 1 x [Crazy Circuits Screw Terminal Chip](https://www.browndoggadgets.com/products/screw-terminal-chip)
* 1 x DC Motor with Fan Blade
* 1 x DC Power
* 1 x Small Cup
* 1 x LEGO Baseplate
* Misc LEGO pieces
* Bubble Wand & Bubble Soap

The Bit Board has a built-in relay on Pin 16 which we use to turn on and off the fan so we can blow bubbles. A servo on Pin 0 is activated by a button connected to Pin 1 to start the bubble blowing process.

## Adafruit Clue

The code is written in CircuitPython and to use it as-is just copy it to the Clue after you connect it to your computer with a USB cable.

## micro:bit

The code can be loaded into the MakeCode Editor: [Bubble Machine](https://makecode.microbit.org/_05vhF0CH27ML)

Full build instructions: https://browndoggadgets.dozuki.com/Guide/Bubble+Machine/237

---

Brown Dog Gadgets

https://www.browndoggadgets.com/

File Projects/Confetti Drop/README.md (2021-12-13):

# Confetti Drop



Confetti Drop uses a Crazy Circuits Robotics Board along with a distance sensor and a servo to drop confetti on someone. Hilarious!

Parts needed:
* 1 x [Crazy Circuits Robotics Board](https://www.browndoggadgets.com/collections/tbm/products/crazy-circuits-robotics-board)
* 1 x [Brick Compatible 270 Degree Servo](https://www.browndoggadgets.com/products/brick-compatible-270-degree-servo)
* 1 x [HC-SR04 Ultrasonic Distance Sensor](https://www.browndoggadgets.com/products/distance-sensor)
* 1 x LEGO Baseplate
* Misc LEGO pieces

The Arduino sketch `Confetti-Drop` can be found in the **Arduino** folder.

Full build guide: https://browndoggadgets.dozuki.com/Guide/Confetti+Drop/311



---

Brown Dog Gadgets

https://www.browndoggadgets.com/

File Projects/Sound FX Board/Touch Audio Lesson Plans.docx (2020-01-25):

DIY Arduino-powered Sound Board for the Classroom

What the device is and what it does: This simple Arduino-controlled project can be made very quickly with:

- 1 Crazy CircuitsÔ Invention Board
- 11 Maker TapeÔ conductive tape lengths
- 4 ribbon wires
- 2 Crazy CircuitsÔ 2 pin headers
- A variety of conductive materials for touch surfaces (conductive paint, foil tape, more Maker Tape, conductive dough
- Our free, downloadable code
- MP3 modulator/player
- MP3 Audio Files of your choice

By itself, this is a device that allows a user to load and assign any MP3 audio file to any of 11 separate Arduino-Code-Controlled touch points that, when triggered, play the audio file assigned to them. Within a classroom context, this device can be effectively used as a semi-permanent station with an elastic purpose. Think of it as a “Speak and Spell” mixed with a “See and Say” that can be set and reset to serve the needs of any content that might benefit from being reviewed via connected audio/visual information.

Although simple enough to approach this build AND the electronics/programming concepts which drive it with students, the touch board is even easier to assemble solely by the classroom educator. It can be affixed to nearly any surface in a classroom setting from tables to walls. When completed, an educator may load individual audio files that play when each separate touch pad is triggered. This can be useful in a variety of ways but primarily as a fun, classroom self-quiz station. Weave it into your classroom stations rotation…use it to motivate lame but still effective drill-and-kill practice sessions.

Potential Sound Board Quizmaster Activities

- In the ESL Classroom Setting: “Sights, Sounds, Symbols: A multiple intelligence approach to strengthening language concepts”

General Procedure:

Students first create a picture representation of any unit’s new vocabulary words to serve as their “button” label for each of 11 pads representing 11 new vocabulary words. Afterward, they match a given picture label to a word already labeling each touch pad. Students will activate the pads they create and actively copy the pronunciation consistently to connect word to meaning and both to sound as well as their own experiences. Once vocab familiarity has been established, students can then quiz themselves consistently in reverse by removing the word labels for each touch pad, pressing the pad FIRST to hear the word and matching correct word cards to each vocabulary word.

*Other Ideas:

This activity can be used as a station to facilitate independent skill practice or a way for an educator to quickly verify vocabulary proficiency for those with special accommodations made relative to writing. The same device can be used in non-ESL vocabulary scenarios as well.

- In the Language Arts Classroom Setting: “Retelling Remixed: Narrative Chronology Retelling with Sound and Picture”

General Procedure:

The sound board can be configured to serve as a tool that facilitates independent practice in story recall and understanding narrative chronology in a language arts context. Simply add audio files out of chronological order and label each position pad with a letter. Allow students to visit this as a station, listening to the audio at each touch position and placing the letter labels in correct chronological order to correctly retell the story. This basic arrangement can be used to review the chronology of a narrative that a class may be reading. It can also be used to introduce and reinforce the idea of chronology in a number of writing styles from narrative to informative. “Retelling remixed” can even be used as an assessment accommodation for those students will special needs.

*Other Ideas:

Verb Conjugation/ Verb & Adverb Pairing/ Noun & Adjective Pairing

- In The Mathematics Classroom Setting: “Touch Tables: Audio/Visual Multiplication Table Practice”

General Procedure:

Tell students that each day they are working on learning their multiplication tables, the Sound Board will be assigned a digit. Simply load either spoken numeric answers OR stated multiplication problems for that single digit to each of the 11 positions on the sound board. If the educator has loaded audio ANSWERS randomly to each position, have students write the 11 possible multiplication problems associated with the digit (call this their “factor/factor” deck) on separate index cards that will serve to label each position when it is their turn. If the educator has loaded audio multiplication problems randomly to each position, have students write the 11 possible ANSWERS associated with the digit on separate index cards (call this their “product” deck) that will serve to label each position when it is their turn. Students can now work in pairs to rotate in and out of this station throughout the day and the sound board can quiz them for you. One student pressing an unlabeled position pad, hearing either the ANSWER and matching their card to the pad position. The second student can use a multiplication table to check their answers and then switch roles. As students become better and better at recalling these important mental math facts, an educator COULD go farther and (for example) assign audio statements of several multiplication problems that yield the same product. The student pairs would have to select the card (from their product stack) that serves as the product that satisfies all of the statements…or the cardS (from their factor/factor deck) that produce the product loaded to each position.

*Other Ideas:

Fraction/Decimal Equivalents, Square Roots…basically any math “fact” where memorization can lead to better mental math can be drilled and killed in an INDEPENDENT and more fun way with the sound board.

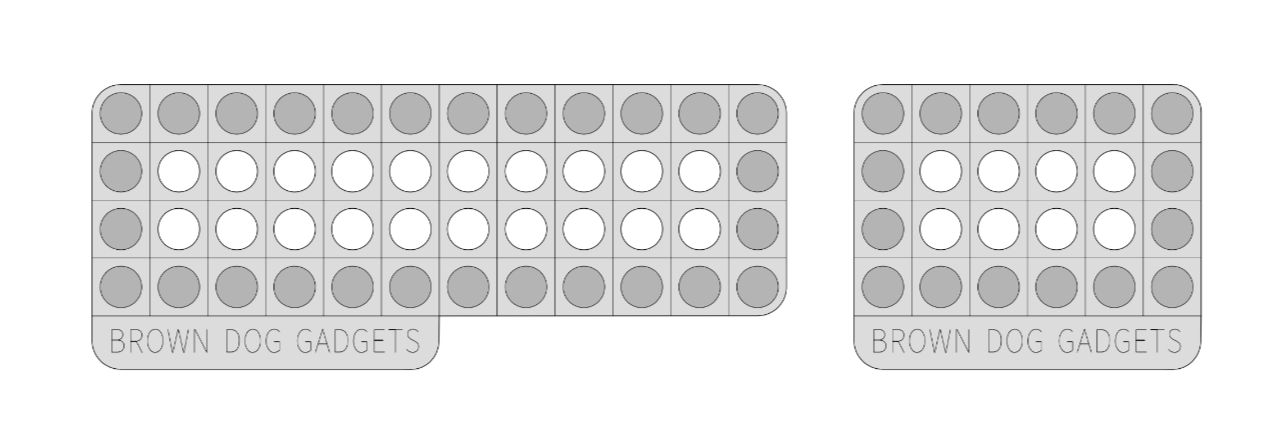
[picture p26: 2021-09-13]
Projects/LEGO Hole Punch/Images/Paper.png

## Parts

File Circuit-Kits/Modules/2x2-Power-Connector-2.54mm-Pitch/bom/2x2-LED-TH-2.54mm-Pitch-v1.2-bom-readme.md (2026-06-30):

|Ref|Qty|Description|Digikey PN|
|---|---|---|---|
|J1|1|HEADER RIGHT ANGLE 2.54MM PITCH|952-2244-ND|

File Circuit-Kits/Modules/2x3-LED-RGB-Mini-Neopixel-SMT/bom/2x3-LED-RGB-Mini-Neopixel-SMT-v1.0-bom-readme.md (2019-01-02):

|Ref|Qty|Description|Digikey PN|
|---|---|---|---|
|C1|1|CAP CER 0.1UF 25V X7R 0603|311-1341-1-ND|
|LED1|1|LED RGB SK6812MINI 4SMD|1528-1542-ND|
|R1|1|RES SMD 470 OHM 5% 1/4W 0603|RHM470DCT-ND|

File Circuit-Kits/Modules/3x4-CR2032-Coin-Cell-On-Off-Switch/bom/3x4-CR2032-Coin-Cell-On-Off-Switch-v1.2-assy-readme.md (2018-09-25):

Individual Placements per board: 2

Number of Parts: 2

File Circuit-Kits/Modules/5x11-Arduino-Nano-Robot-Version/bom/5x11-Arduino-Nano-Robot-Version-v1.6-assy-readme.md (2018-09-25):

Individual Placements per board: 2

Number of Parts: 7

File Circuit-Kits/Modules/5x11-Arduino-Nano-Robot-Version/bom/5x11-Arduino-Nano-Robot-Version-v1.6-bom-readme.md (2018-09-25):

|Ref|Qty|Description|Digikey PN|
|---|---|---|---|
|J1-6|6|HEADER MALE 3POS TH 1x03 0.1IN|952-2264-ND|
|U1|1|ARDUINO NANO BOARD|1050-1001-ND|

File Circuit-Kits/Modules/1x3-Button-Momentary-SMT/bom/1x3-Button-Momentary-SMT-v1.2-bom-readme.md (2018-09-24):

|Ref|Qty|Description|Digikey PN|
|---|---|---|---|
|SW1|1|SWITCH MOMENT SPST-NO 0.05A 12V SMT PTS645|CKN9112CT-ND|

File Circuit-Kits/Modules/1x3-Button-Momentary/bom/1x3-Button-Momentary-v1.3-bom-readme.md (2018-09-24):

|Ref|Qty|Description|Digikey PN|
|---|---|---|---|
|SW1|1|SWITCH MOMENT SPST-NO 0.05A 24V SMT B3F-1000|SW400-ND|

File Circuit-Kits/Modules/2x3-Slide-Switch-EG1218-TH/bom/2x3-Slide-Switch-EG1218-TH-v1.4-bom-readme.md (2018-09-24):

|Ref|Qty|Description|Digikey PN|
|---|---|---|---|
|SW1|1|SWITCH SLIDE SPDT 200MA 30V|EG1903-ND|

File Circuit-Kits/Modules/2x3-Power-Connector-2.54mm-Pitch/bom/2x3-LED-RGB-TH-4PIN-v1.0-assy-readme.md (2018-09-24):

Individual Placements per board: 1

Number of Parts: 1

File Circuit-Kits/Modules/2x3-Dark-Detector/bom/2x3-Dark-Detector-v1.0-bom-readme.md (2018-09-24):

|Ref|Qty|Description|Digikey PN|
|---|---|---|---|
|LDR1|1|PHOTOTRANSISTOR FLAT BK MINI SMD|1080-1383-1-ND|
|Q1|1|TRANS NPN 40V 0.2A SOT-23|MMBT3904TPMSCT-ND|
|R1|1|RES SMD 100K OHM 5% 1/10W 0603|311-100KGRCT-ND|

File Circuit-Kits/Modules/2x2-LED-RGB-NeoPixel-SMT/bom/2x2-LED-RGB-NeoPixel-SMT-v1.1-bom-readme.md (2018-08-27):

|Ref|Qty|Description|Digikey PN|
|---|---|---|---|
|C1|1|CAP CER 0.1UF 16V X7R 0603|490-4774-1-ND|
|LED1|1|LED RGB WS2812B W/DVR 4SMD|1528-1104-ND|
|R1|1|RES SMD 470 OHM 5% 1/4W 0603|RHM470DCT-ND|

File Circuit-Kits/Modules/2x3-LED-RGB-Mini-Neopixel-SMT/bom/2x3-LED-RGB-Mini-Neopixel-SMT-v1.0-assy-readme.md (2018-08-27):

Individual Placements per board: 3

Number of Parts: 3

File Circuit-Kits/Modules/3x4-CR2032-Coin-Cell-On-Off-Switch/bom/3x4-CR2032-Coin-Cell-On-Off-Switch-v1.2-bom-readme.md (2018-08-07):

|Ref|Qty|Description|Digikey PN|
|---|---|---|---|
|BT1|1|HOLDER BATT COIN CR2032/20MM|BK-912-ND|
|S1|1|SWITCH SLIDE SPDT 200MA 30V|EG1903-ND|

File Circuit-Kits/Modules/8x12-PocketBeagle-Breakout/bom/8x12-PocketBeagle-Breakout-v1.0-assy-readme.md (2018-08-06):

Individual Placements per board: 2

Number of Parts: 6

Board size is 2.51 x 3.77 inches (63.80 x 95.80 mm)

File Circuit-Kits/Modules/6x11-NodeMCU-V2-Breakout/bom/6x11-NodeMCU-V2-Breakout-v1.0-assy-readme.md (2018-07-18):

Individual Placements per board: 2

Number of Parts: 5

Board size is 1.88 x 3.46 inches (47.80 x 87.80 mm)

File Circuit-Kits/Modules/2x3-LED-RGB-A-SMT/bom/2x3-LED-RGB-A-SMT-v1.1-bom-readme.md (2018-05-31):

|Ref|Qty|Description|Digikey PN|
|---|---|---|---|
|LED1|1|LED CHIP RGB 19-237 A01/2T SMD |19-237/R6GHBHC-A01/2T-ND|
|R1 R2|2|RES SMD 100 OHM 1% 1/10W 0603|A106047CT-ND|
|R3|1|RES 47 OHM 5% 1/10W 0603|311-47GRCT-ND|

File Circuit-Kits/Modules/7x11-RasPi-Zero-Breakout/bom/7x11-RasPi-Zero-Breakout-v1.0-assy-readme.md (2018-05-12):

Individual Placements per board: 1

Number of Parts: 1

Board size is 2.20 x 3.46 inches (55.80 x 87.80 mm)

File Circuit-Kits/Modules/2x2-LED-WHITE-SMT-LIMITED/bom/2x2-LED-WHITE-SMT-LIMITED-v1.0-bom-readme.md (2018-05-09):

|Ref|Qty|Description|Digikey PN|
|---|---|---|---|
|LED1|1|LED WHITE CLEAR SMT 1206|1516-1164-1-ND|
|R1|1|RES 100 OHM 5% 1/4W 1206|311-100FRCT-ND|

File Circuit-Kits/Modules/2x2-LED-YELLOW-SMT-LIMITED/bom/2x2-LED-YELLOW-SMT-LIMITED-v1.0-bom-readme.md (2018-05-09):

|Ref|Qty|Description|Digikey PN|
|---|---|---|---|
|LED1|1|LED YELLOW CLEAR SMT 1206|732-4994-1-ND|
|R1|1|RES 100 OHM 5% 1/4W 1206|311-100FRCT-ND|

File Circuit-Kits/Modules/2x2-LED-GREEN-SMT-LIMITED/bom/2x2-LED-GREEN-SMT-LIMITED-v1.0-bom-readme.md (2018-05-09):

|Ref|Qty|Description|Digikey PN|
|---|---|---|---|
|LED1|1|LED GREEN CLEAR SMT 1206|732-4993-1-ND|
|R1|1|RES 100 OHM 5% 1/4W 1206|311-100FRCT-ND|

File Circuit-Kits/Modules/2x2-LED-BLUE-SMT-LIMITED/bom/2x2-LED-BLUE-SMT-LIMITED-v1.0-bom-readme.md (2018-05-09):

|Ref|Qty|Description|Digikey PN|
|---|---|---|---|
|LED1|1|LED BLUE CLEAR SMT 1206|732-4989-1-ND|
|R1|1|RES 100 OHM 5% 1/4W 1206|311-100FRCT-ND|

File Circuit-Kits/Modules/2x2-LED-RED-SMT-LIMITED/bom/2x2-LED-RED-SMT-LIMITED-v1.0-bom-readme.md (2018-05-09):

|Ref|Qty|Description|Digikey PN|
|---|---|---|---|
|LED1|1|LED RED CLEAR SMT 1206|732-4991-1-ND|
|R1|1|RES 100 OHM 5% 1/4W 1206|311-100FRCT-ND|

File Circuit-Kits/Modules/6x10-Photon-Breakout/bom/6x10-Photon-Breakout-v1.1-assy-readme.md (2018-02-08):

Individual Placements per board: 1

Number of Parts: 1

Board size is 1.88 x 3.14 inches (47.80 x 79.80 mm)

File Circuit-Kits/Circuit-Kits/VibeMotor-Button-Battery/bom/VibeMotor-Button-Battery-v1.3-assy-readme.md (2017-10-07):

Individual Placements per board: 3

Number of Parts: 3

Board size is 1.33 x 1.65 inches (33.90 x 41.93 mm)

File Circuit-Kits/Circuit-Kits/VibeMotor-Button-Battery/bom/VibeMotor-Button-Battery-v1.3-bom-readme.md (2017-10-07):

|Ref|Qty|Description|Digikey PN|
|---|---|---|---|
|BT1|1|HOLDER BATT COIN CR2032/20MM|952-1735-1-ND|
|SW1|1|SWITCH TACTILE SPST-NO 0.05A 24V|SW400-ND|

|Ref|Qty|Description|Precision Microdrives PN|
|---|---|---|---|
|M1|1|MOTOR VIBE PCB 6MM - 10MM TYPE|306-114|

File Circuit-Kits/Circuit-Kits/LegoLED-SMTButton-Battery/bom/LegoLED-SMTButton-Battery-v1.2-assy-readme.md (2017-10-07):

Individual Placements per board: 3

Number of Parts: 3

Board size is 1.65 x 1.64 inches (41.79 x 41.68 mm)

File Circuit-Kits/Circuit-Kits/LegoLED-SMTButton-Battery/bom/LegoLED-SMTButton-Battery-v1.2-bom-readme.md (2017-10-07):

|Ref|Qty|Description|Digikey PN|
|---|---|---|---|
|BT1|1|HOLDER BATT COIN CR2032/20MM|BK-912-ND|
|SW1|1|SWITCH MOMENT SPST-NO 0.05A 14V SMT PTS645|CKN9112TR-ND|

|Ref|Qty|Description|Lunchbox Electronics PN|
|---|---|---|---|
|LED1|1|LED LEGO NOVELTY COLOR 5MM PITCH|COM-005|

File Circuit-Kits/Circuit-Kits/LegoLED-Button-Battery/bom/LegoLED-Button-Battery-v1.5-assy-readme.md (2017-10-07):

Individual Placements per board: 3

Number of Parts: 3

Board size is 1.64 x 1.35 inches (41.78 x 34.22 mm)

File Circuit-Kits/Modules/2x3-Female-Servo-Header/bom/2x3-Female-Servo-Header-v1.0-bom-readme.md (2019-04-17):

|Ref|Qty|Description|Digikey PN|
|---|---|---|---|
|J1|1|HEADER FEMALE 3POS TH 1x03 0.1IN|952-1784-ND|

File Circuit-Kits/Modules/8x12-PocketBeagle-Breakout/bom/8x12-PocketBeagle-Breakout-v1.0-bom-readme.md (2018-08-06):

|Ref|Qty|Description|Digikey PN|
|---|---|---|---|
|J1 J2 J3 J4 J5|5|HEADER MALE 3POS TH 1x03 0.1IN|952-1902-ND|
|J6|1|POCKETBEAGLE|POCKETBEAGLE-SC-569-ND|

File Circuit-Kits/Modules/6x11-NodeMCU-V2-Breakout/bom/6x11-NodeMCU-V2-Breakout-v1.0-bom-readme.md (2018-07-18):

|Ref|Qty|Description|Banggood PN|
|---|---|---|---|
|U1|1|NODEMCU LUA V2 ESP-12E DEV KIT|1097112|

|Ref|Qty|Description|Digikey PN|
|---|---|---|---|
|J1 J2 J3 J4|4|HEADER MALE 3POS TH 1x03 0.1IN|952-1902-ND|

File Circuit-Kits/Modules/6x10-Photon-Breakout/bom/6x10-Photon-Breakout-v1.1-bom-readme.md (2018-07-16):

|Ref|Qty|Description|Digikey PN|
|---|---|---|---|
|U1|1|PARTICLE PHOTON V016|1878-1000-ND|

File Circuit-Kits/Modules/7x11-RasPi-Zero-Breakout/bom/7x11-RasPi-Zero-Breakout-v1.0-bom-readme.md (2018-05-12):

|Ref|Qty|Description|Digikey PN|
|---|---|---|---|
|J1|1|HEADER FEMALE 20POS TH 2x20 0.1IN|S6106-ND|

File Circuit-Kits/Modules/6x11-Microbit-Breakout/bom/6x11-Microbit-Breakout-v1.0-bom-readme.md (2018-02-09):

|Ref|Qty|Description|Adafruit PN|
|---|---|---|---|
|J1|1|HEADER MALE 80POS TH 4x20 MICROBIT R/A|3342|

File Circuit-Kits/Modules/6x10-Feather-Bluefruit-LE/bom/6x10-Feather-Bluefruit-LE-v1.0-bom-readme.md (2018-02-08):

|Ref|Qty|Description|Digikey PN|
|---|---|---|---|
|U1|1|ADAFRUIT FEATHER BLUEFRUIT LE|1528-2095-ND|

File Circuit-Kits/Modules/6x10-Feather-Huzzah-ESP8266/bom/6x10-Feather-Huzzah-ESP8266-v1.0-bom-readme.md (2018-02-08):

|Ref|Qty|Description|Digikey PN|
|---|---|---|---|
|U1|1|ADAFRUIT FEATHER ESP8266 HUZZAH|1528-1530-ND|

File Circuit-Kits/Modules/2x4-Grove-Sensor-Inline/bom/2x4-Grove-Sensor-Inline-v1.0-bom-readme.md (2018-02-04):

|Ref|Qty|Description|Digikey PN|
|---|---|---|---|
|J1|1|HEADER MALE 4POS TH 1x04 SEEED GROVE|1597-1082-ND|

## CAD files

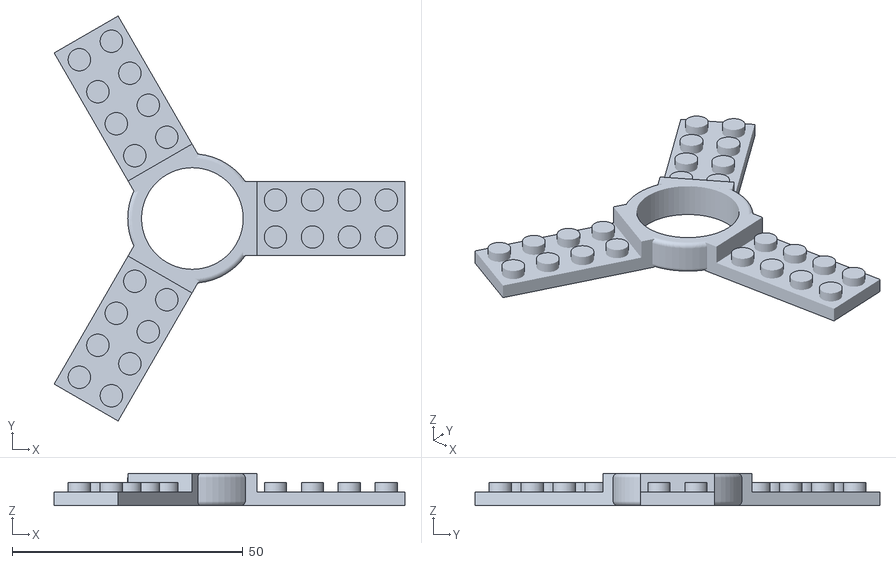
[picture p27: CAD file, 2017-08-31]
Projects/LEGO Fidget/3D Models/spin-3arms-2across-4down-crazzy-circuits.stl
75.9 x 87.7 x 7.00

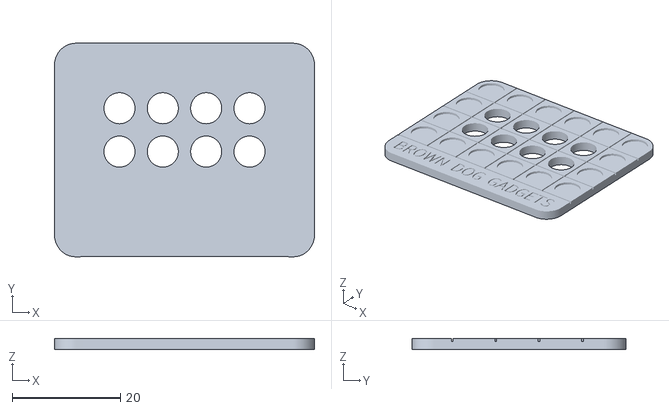
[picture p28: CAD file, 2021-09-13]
Projects/LEGO Hole Punch/3D Printer/BDG LEGO Hole Punch 3D Print Small.stl
48.0 x 39.4 x 2.00

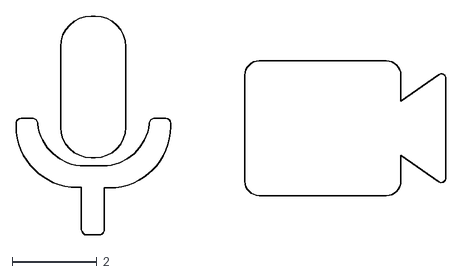
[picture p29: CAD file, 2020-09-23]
Projects/Meeting Controls/Icons/Icons.dxf
10.1 x 5.16

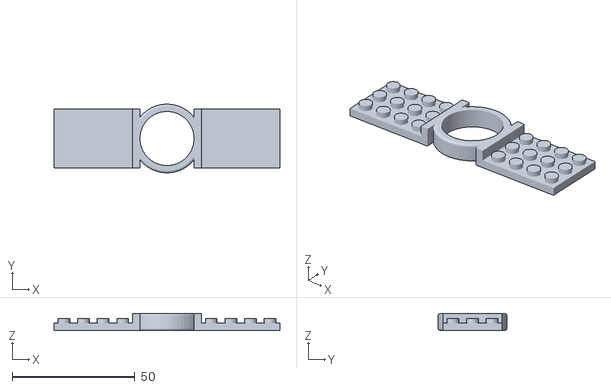
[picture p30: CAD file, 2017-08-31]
Projects/LEGO Fidget/3D Models/spin-2arms-3across-4down-crazy-circuits.stl
92.0 x 28.0 x 7.00

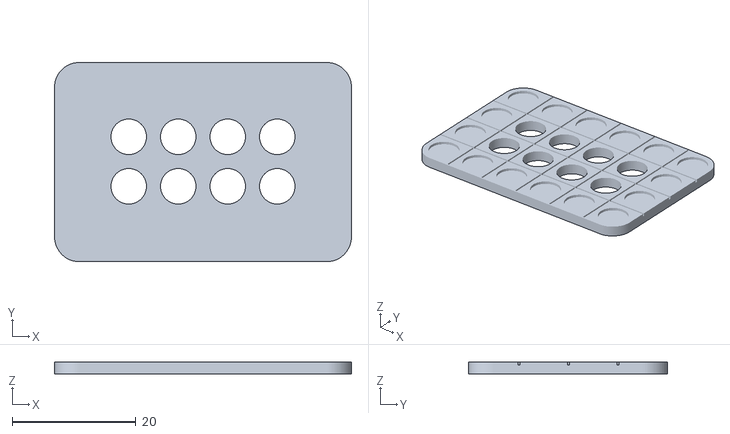
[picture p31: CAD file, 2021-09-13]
Projects/LEGO Hole Punch/3D Printer/BDG LEGO Hole Punch 3D Print Small Alt.stl
48.0 x 32.2 x 2.00

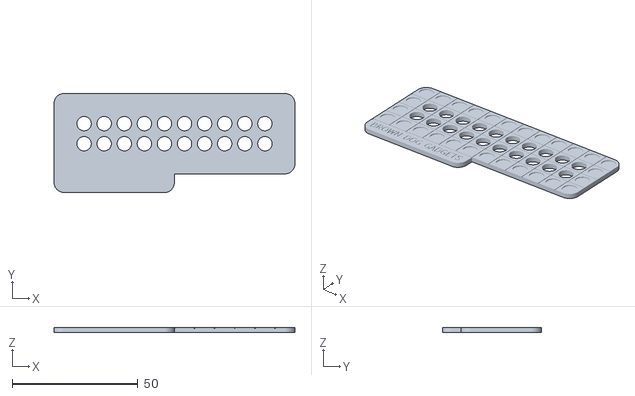
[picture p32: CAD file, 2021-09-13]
Projects/LEGO Hole Punch/3D Printer/BDG LEGO Hole Punch 3D Print.stl
96.0 x 39.4 x 2.00

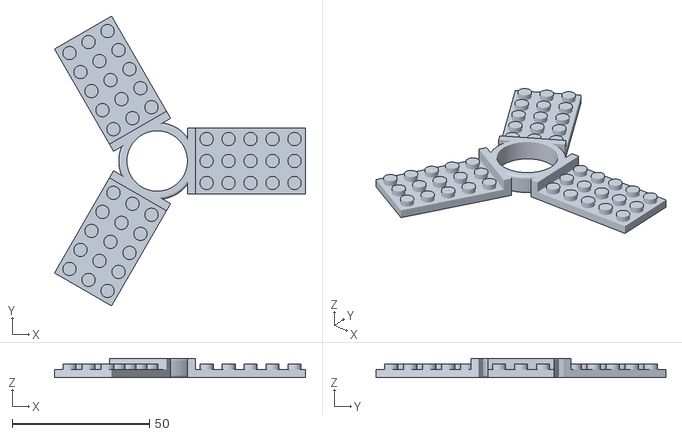
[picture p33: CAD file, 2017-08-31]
Projects/LEGO Fidget/3D Models/spin-3arms-3across-5down-no-logo.stl
91.4 x 105.5 x 7.00

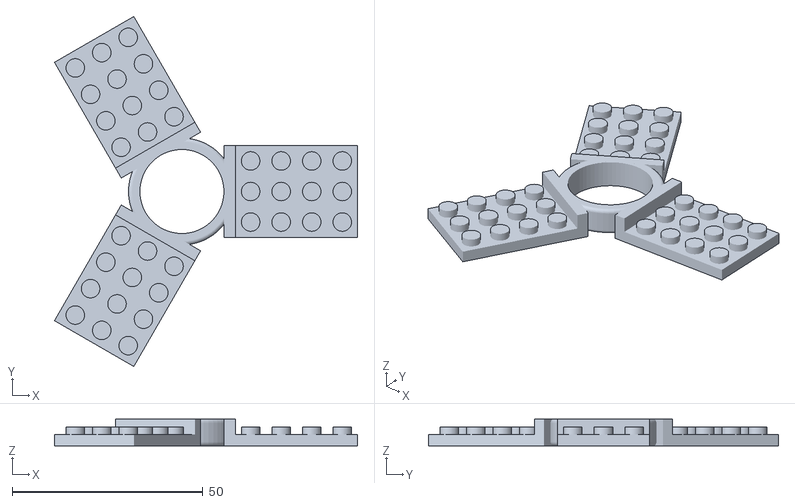
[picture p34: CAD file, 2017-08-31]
Projects/LEGO Fidget/3D Models/spin-3arms-3across-4down-crazy-circuits-uc.stl
79.4 x 91.7 x 7.00

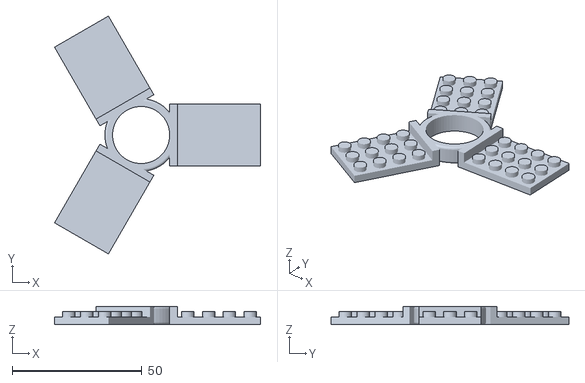
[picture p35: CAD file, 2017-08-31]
Projects/LEGO Fidget/3D Models/spin-3arms-3across-4down.stl
79.4 x 91.7 x 7.00

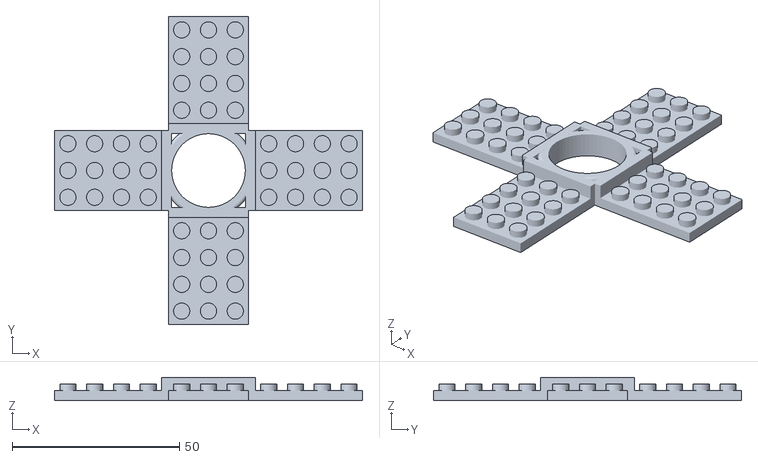
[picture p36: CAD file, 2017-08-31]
Projects/LEGO Fidget/3D Models/spin-4arms-3across-4down-crazy-circuits.stl
92.0 x 92.0 x 7.00

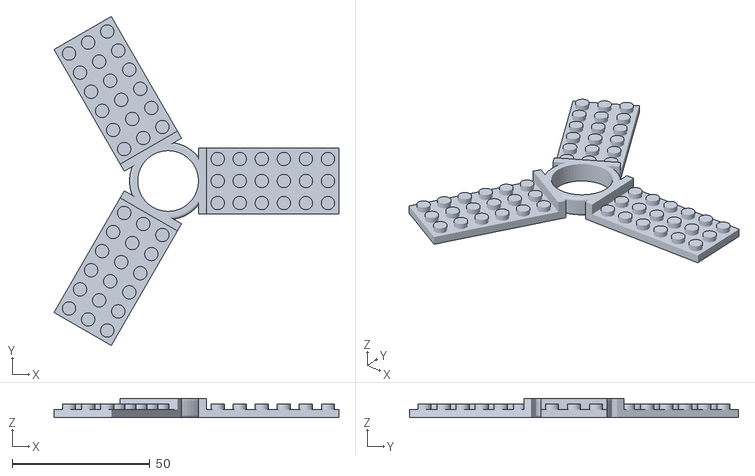
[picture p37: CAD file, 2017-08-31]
Projects/LEGO Fidget/3D Models/spin-3arms-3across-6down-no-logo.stl
103.4 x 119.4 x 7.00

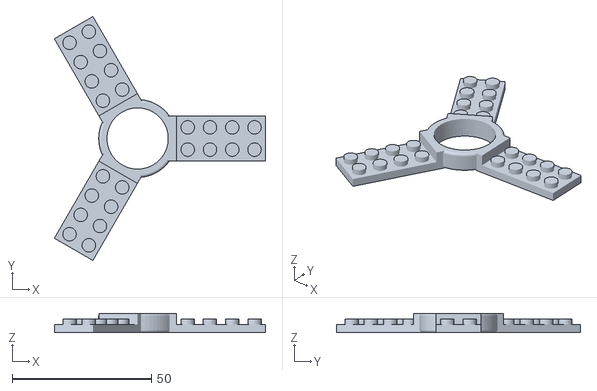
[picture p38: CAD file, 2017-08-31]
Projects/LEGO Fidget/3D Models/spin-3arms-2across-4down-crazy-circuits-uc.stl
75.9 x 87.7 x 7.00

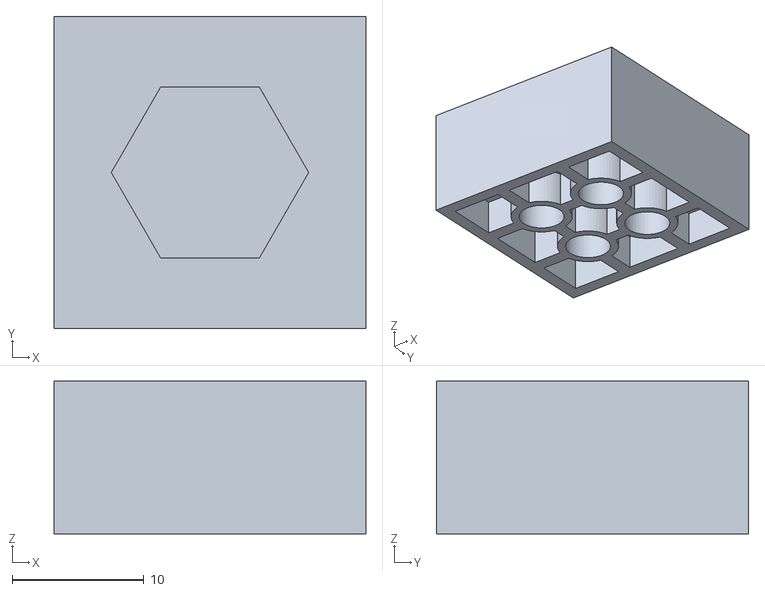
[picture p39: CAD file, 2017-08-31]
Projects/LEGO Fidget/3D Models/nut-brick-3x3-M8.stl
23.7 x 23.7 x 11.6

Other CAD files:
Projects/LEGO Fidget/3D Models/spin-3arms-3across-4down-crazy-circuits.stl
Projects/LEGO Fidget/3D Models/nut-brick-3x3-516.stl
Projects/LEGO Fidget/3D Models/nut-brick-2x2-516.stl
Projects/LEGO Fidget/3D Models/nut-brick-2x2-M8.stl
Projects/LEGO Fidget/3D Models/nut-brick-3x2-516.stl
Projects/LEGO Fidget/3D Models/nut-brick-3x2-M8.stl

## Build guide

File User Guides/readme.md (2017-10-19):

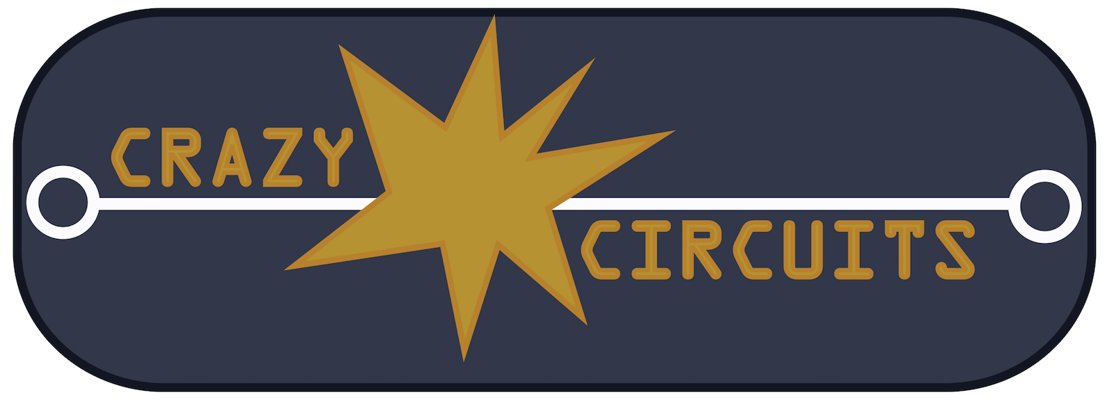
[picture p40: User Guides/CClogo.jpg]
cc logo

# Crazy Circuits User Guides

Download these various user guides to help with your next Crazy Circuits creation.

You can also view a basic overview [Guide](https://www.youtube.com/watch?v=8BR6lTN7iAI) Video on our youtube channel.

What you'll find here are:

* Basic User Guide
* Touch Board Guide
* Robotics Board Guide
* Individual Part "Mini" Guides (Same as found in kits)
* Individual Part Graphics for Digital Circuit Creation
* Practice "Paper" For Printing and Drawing Circuits

For larger step by step project guides and resources, please view our [Projects](https://github.com/BrownDogGadgets/CrazyCircuits/tree/master/Projects) area.

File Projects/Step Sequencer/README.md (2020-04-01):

# Step Sequencer

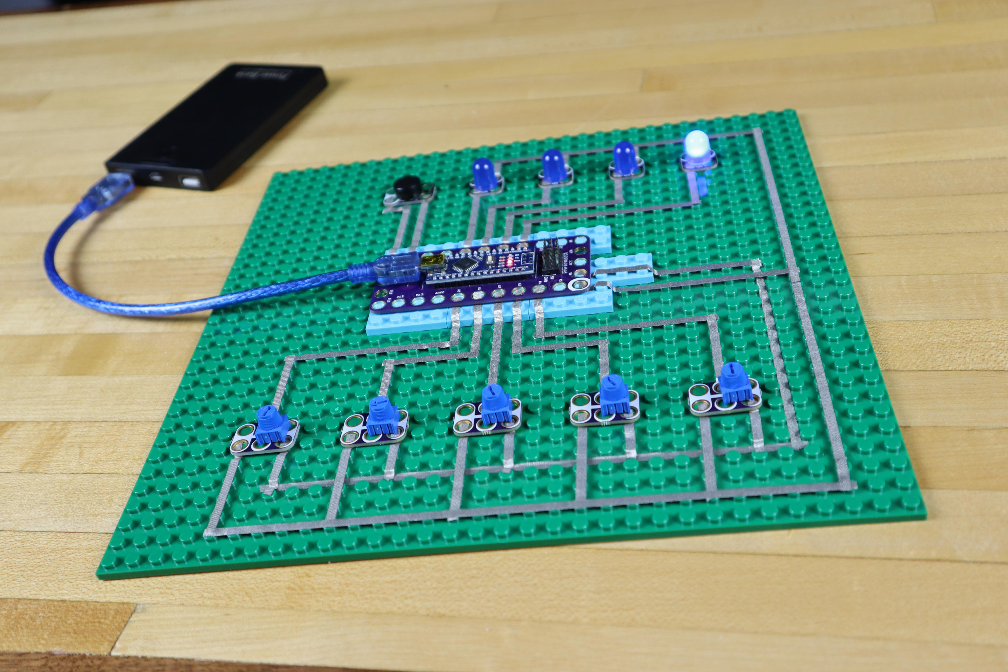
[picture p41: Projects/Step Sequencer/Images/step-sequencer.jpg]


A Step Sequencer built with Crazy Circuits parts on a LEGO baseplate. You can experiment with making your own beats using the four step audio sequencer. Set the frequency for each of the four notes and control the speed with the tempo potentiometer. The LEDs will light up to correspond with the note being played.

Parts needed:
* 1 x [Crazy Circuits Robotics Board](https://www.browndoggadgets.com/collections/new-crazy-circuits-kits/products/crazy-circuits-robotics-board)
* 4 x [Crazy Circuits LEDs](https://www.browndoggadgets.com/collections/all/products/blue-jumbo-diffused-led-chip)
* 5 x Crazy Circuit Potentiometers (Coming Soon!)
* 1 x [Crazy Circuits Piezo Speaker Chip](https://www.browndoggadgets.com/collections/all/products/piezoelectric-speaker-chip)
* 1 x [Roll of 1/8" Maker Tape](https://www.browndoggadgets.com/collections/new-crazy-circuits-supplies/products/nylon-conductive-tape)
* 1 x LEGO Baseplate
* Misc LEGO pieces

The Arduino sketch `StepSequencer` is included along with a circuit diagram.

Full build instructions: https://browndoggadgets.dozuki.com/Guide/Step+Sequencer/156

---

Brown Dog Gadgets

https://www.browndoggadgets.com/

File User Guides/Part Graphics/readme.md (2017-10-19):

# Part Graphics

Download and use these parts to create digital diagrams in your favorite drawing program.

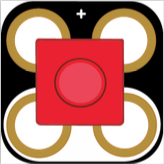
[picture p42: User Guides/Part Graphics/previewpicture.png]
BrickLED


If you want to draw out circuits by hand, use our [Printable Paper Templates.](https://github.com/BrownDogGadgets/CrazyCircuits/tree/master/User%20Guides/Printable%20Test%20Paper)

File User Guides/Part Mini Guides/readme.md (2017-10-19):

# Part Mini Guides

These are the same cards that are included in all our kits. If you lose yours or need more, just print these off.

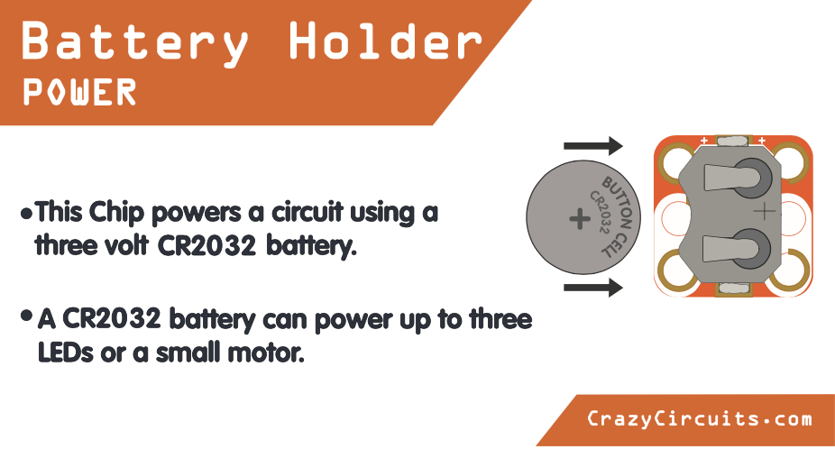
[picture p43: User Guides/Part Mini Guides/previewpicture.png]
Preview


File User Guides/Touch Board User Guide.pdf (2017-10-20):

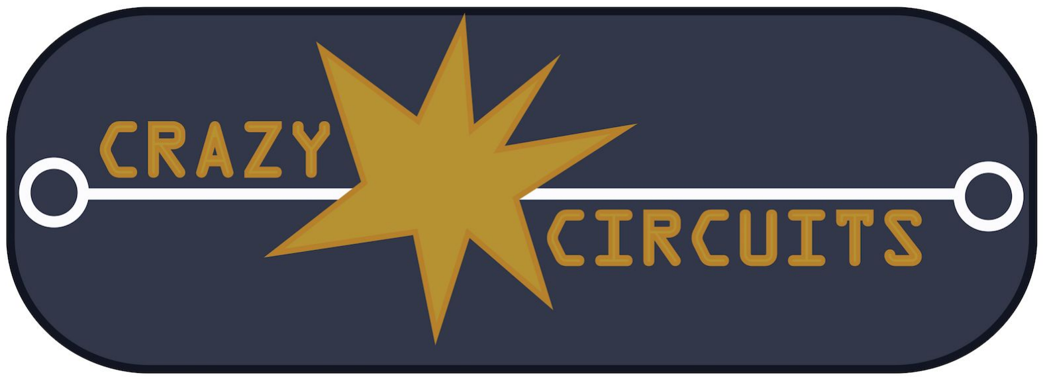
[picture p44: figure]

Touch Board User Guide

Introduction

The Crazy Circuits Touch Board is a fun way to create interactive projects. The Touch Board has 11 built in Touch Points for use with projects and also features built in KeyBoard emulation, which allows it to interface with any computer.

This User Guide will show you how to install the needed Touch Board Software, upload code, and how to connect it to components. At the end of this guide we’ll walk you through a couple of simple projects using the Touch Board. For more complicated projects please visit please visit our Project Galley or Forums on CrazyCircuits.com.

Technical Details

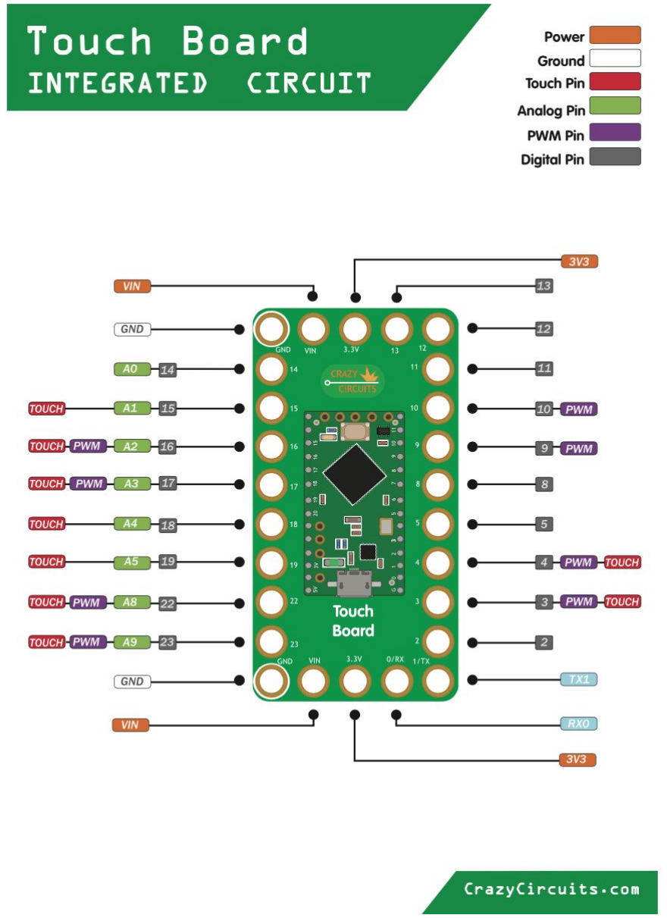
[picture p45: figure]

The Crazy Circuits Touch Board is based off the Teensy LC development board. Advanced users can find all sorts of resources at pjrc.com and their forums. In general, these boards act like a standard Arduino and can run any standard Arduino code.

Two features we really enjoy about the Teensy LC is its built in Capacitive Touch capability and KeyBoard Emulation. These features are heavily relied on for many of our Projects. For a full list of board features and abilities, click the link below.

https://www.pjrc.com/teensy/teensyLC.html

Blank, unsoldered, Touch Board PCBs are available for sale on CrazyCircuits.com. The Touch Board PCB also accepts the Teensy 3.2 development board if more advanced features are needed.

Software

In order to upload projects and code to the Touch Board you’ll need to install some software. The software will run on any Mac, PC, or Linux computer with built in USB ports, which is pretty much most all computers these days.

First you’ll need to download the free Arduino IDE software from the Arduino Website. This is the computer program that will let you upload code to your Touch Board. Download version 1.8.4 for with Mac or PC. (Version 1.8.5 does not work with our board yet.)

https://www.arduino.cc/en/Main/OldSoftwareReleases#previous

Next, you’ll need to install the Teensyduino software add-on. This installs the necessary drivers into the Arduino software to run the Teensy.

https://www.pjrc.com/teensy/td_download.html

Follow the install directions for your type of computer

Arduino IDE

Millions of people around the world use the Arduino IDE software to interact with their Arduino Compatible development boards. Our Touch Board is no different.

Before you start uploading code and projects to your Touch Board we want to walk through a few basic sections of the Arduino IDE, as it can be a bit confusing for new users. These are tips and directions specific to our Touch Board, which means we won’t be explaining everything.

More or less you’re going to mostly be dealing with Sketch writing window and the Tools drop down Menu.

The Sketch writing window is where you type in or paste in your code. If you’re just following allow with our existing Project Guides you’ll mainly be doing a Copy and Paste into this window and hitting Upload.

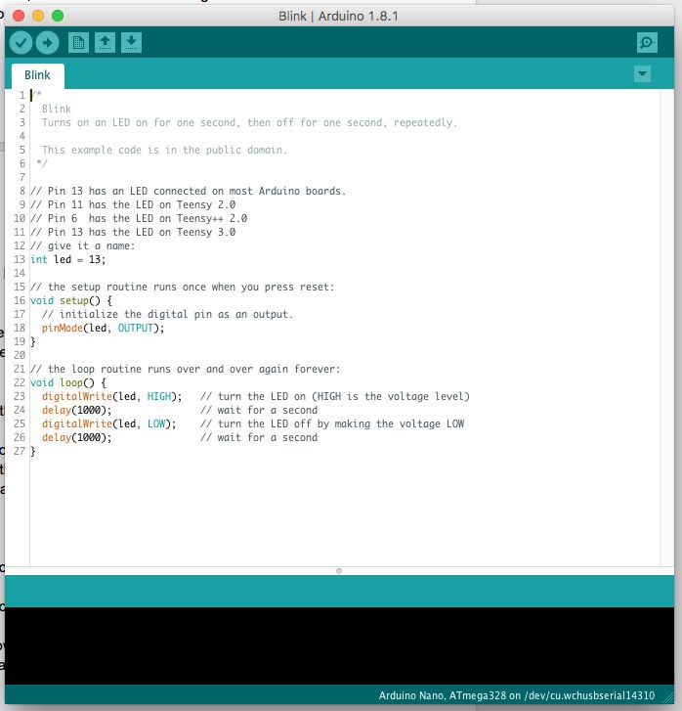
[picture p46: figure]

Before you can upload your code you’ll need to select a few settings. (If you’re only ever going to be using our Touch Board these settings will rarely need to be changed in the future) Click
on the drop down Tool | menu at the top of your screen.

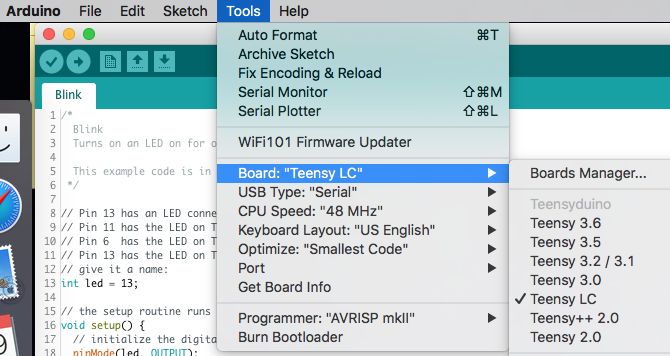
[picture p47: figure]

Mouse down to Board | and then choose Teensy LC. Then, plug in your Touch Board to your
computer.

In general your settings should always look like this:

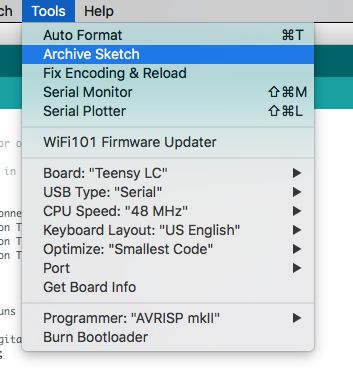
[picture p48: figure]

If you use different types of Arduino Boards, such as our Robotics Board or a standard Arduino Uno, you’ll need to change Board Types in the Tools Menu.

Note: For nearly all Arduino variations a user usually has to select which “port” their board is on. With the Teensy (which is used on the Touch Board) you don’t. This is because the Arduino software throws the compiled code over to the Teensy loader program. Thats why it pops up whenever you’re programing.

Uploading | Code | and | Projects

Lets walk through a simple code upload to make sure that everything is installed and working properly.

We’re going to start by uploading the Arduino Blink Sketch to our board. This uses the built in LED (Pin 13) on the Touch Board and makes its blink. If you want to you can hook up a Crazy Circuits LED to Pin 13 on the board via Conductive Tape. Check the diagram below to see how that would look.

1) Plug in your Touch Board
2) Open the Arduino Software
3) Double check to make sure that you’ve selected the Teensy LC from the Tools menu.
4) Copy and Paste the below code into the Arduino Sketch Window. (You can first delete everything else if you’d like.)
5) If this is the first time uploading a project to your Touch Board, you’ll need to click the Verify Checkmark, and then press the little button on the Touch Board.
6) Otherwise, click the Upload button.
7) Check to see if your LED is blinking. (Next to the button on the middle of your Board.)

If you want to play around with the blink speed, chance the delay(1000) code to a higher or lower number. A number of 1000 equals 1 second of time. Once you’ve changed the number click the Upload button to send the new code to the Touch Board.

/*
Blink
Turns on an LED on for one second, then off for one second, repeatedly.

This example code is in the public domain.
*/

// Pin 13 has an LED connected on most Arduino boards. // Pin 11 has the LED on Teensy 2.0
// Pin 6 has the LED on Teensy++ 2.0
// Pin 13 has the LED on Teensy 3.0
// give it a name:
int led = 13;

// the setup routine runs once when you press reset: void setup() {
// initialize the digital pin as an output.
pinMode(led, OUTPUT);

}

// the loop routine runs over and over again forever:
void loop() {
digitalWrite(led, HIGH); // turn the LED on (HIGH is the voltage level)
delay(1000); | // wait for a second
digitalWrite(led, LOW); // turn the LED off by making the voltage LOW
delay(1000); | // wait for a second
}

Using the Touch Features

The Touch Board features 11 Capacitive Touch Points which allow you to turn anything conductive into a button. Typically we use Conductive Tape to create a path to a conductive item (such as a ball of foil or spot of conductive paint) but Alligator Clips work as well.

Below is an example demo of how to use the Capacitive Touch features to turn on one of two LEDs. One Touch Point turns on LED A, and the second Touch Point turns on LED B. Only one LED is on at a time.

Copy the code found at this link:

https://github.com/BrownDogGadgets/CrazyCircuits/blob/master/Projects/Status%20Light/Status_Light.ino (https://github.com/BrownDogGadgets/CrazyCircuits/blob/master/Projects/Status%20Light/Status_Light.ino)

Paste it into the Arduino Software and upload it to your Touch Board.

Important: Touch Board Calibration

Typically all our Touch based code has a built in “Calibration Mode.” When the code starts up the Touch Board calibrates to whatever the activated Touch Points are hooked up to. In short, don’t Touch your Touch Points for 3-5 seconds when you initially turn on/ upload your code.

Once the Touch Board is calibrated it’ll stay Calibrated until it’s unplugged from power or you press the Reset Button on the board.

Use Conductive Tape to create this circuit.

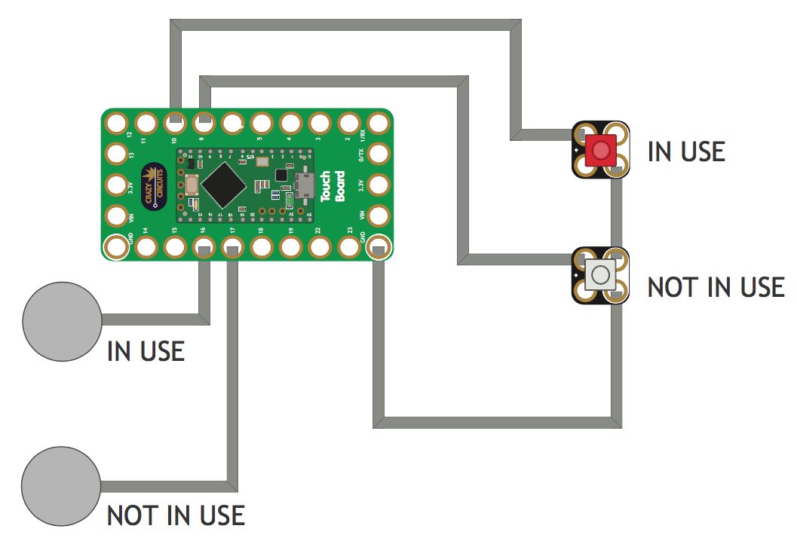
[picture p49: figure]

As | a | KeyBoard | Input

The Touch Board can emulate a standard USB Keyboard. This means you can make your own input devices.

Our favorite example of this is creating our own old school NES Controller using a Touch Board, some LEGOs, and six pushbuttons.

Download the code at this link and upload it to your Touch Board:

https://github.com/BrownDogGadgets/CrazyCircuits/blob/master/Projects/NES%20Controller/Teensy_NES_Controller.ino (https://github.com/BrownDogGadgets/CrazyCircuits/blob/master/Projects/NES%20Controller/Teensy_NES_Controller.ino)

By default the code emulates the four arrow keys as well as keys A and B. If you want to change those to different keyboard commands you just have to change a couple of letters in the code.

Look at line number 111 (use the above link again). Right now it says:

Keyboard.set_key6(KEY_A);

Change that to:

Keyboard.set_key6(KEY_M);

Now when you press the Pushbutton connected to Pin 20 your computer will type the letter “M”.

Follow the diagram below to create a hand sized NES controller!

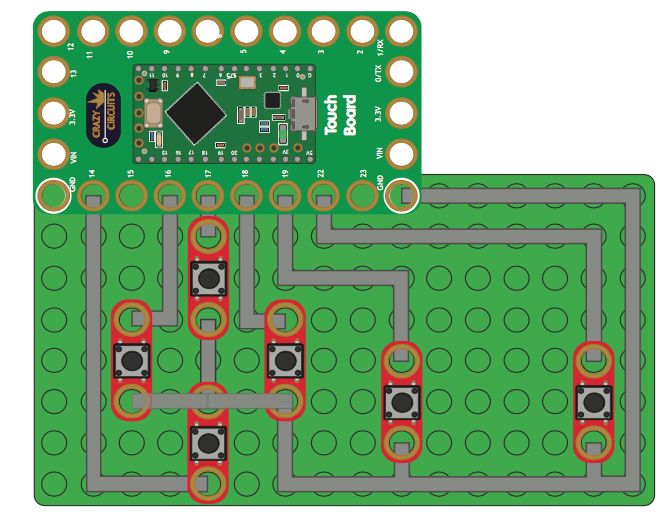
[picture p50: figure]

We used a similar design to create a GIANT NES Controller made entirely out of LEGOs.

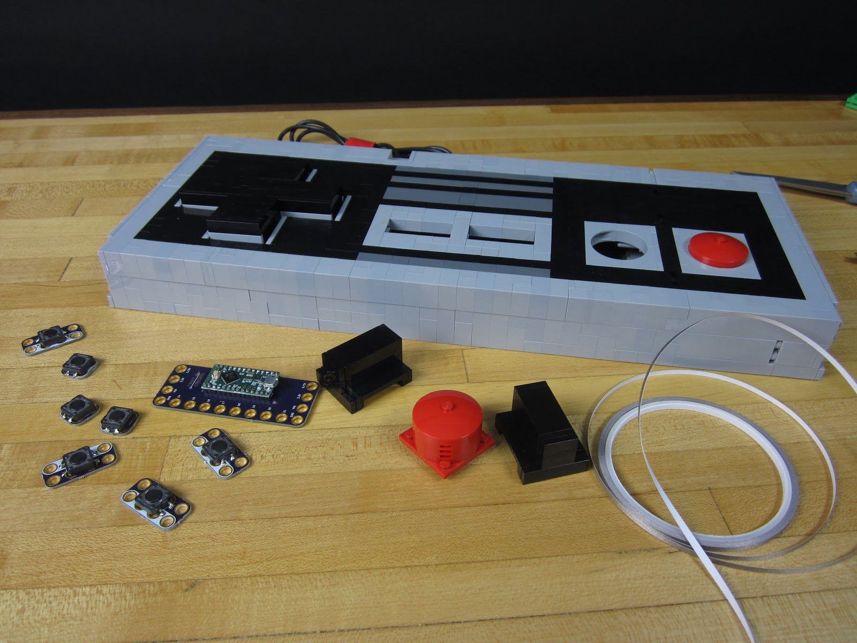
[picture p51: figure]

What Crazy things will you make?

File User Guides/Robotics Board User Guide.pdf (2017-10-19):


Robotics | Board | User | Guide

Introduction

The Crazy Circuits Robotics Board is a fun way to create robotics and programing projects. The Robotics board features a wide range of handy features for creating projects.

This User Guide will show you how to install the needed Robotics Board Software, upload code, and how to connect it to components. At the end of this guide we’ll walk you through a couple of simple projects using the Robotics Board. For more complicated projects please visit please visit our Project Galley or Forums on CrazyCircuits.com.

GitHub | Projects | Repo

https://github.com/BrownDogGadgets/CrazyCircuits/

Forums

TBA

Technical Details

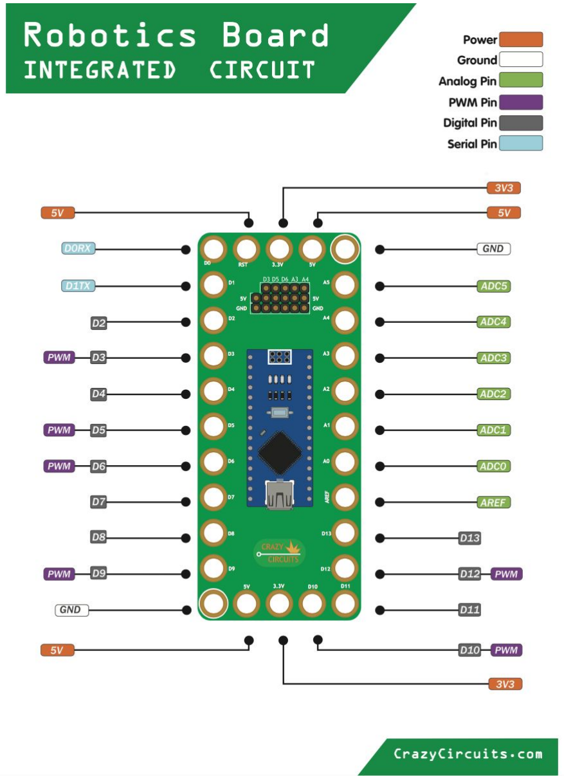
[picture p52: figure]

The Crazy Circuits Robotics Board is based off the open source Arduino Nano development board. Advanced users can find all sorts of resources at https://www.arduino.cc and their forums. In general, these boards act like a standard Arduino and can run any standard Arduino code.

In addition to connecting components with Conductive Tape or Thread we’ve added six sets of Row Headers along the back of the board. These allow for a quick and easy way to plug in Servos, Sensor Modules, and Power.

Please note that unlike our Touch Board, our Robotics Board does not have built in Keyboard Emulation or Touch capabilities and will not work with all the projects we have listed on our website. However, it is recommended for most projects that use Servos and third party sensors.

Blank, unsoldered, Robotics Board PCBs are available for sale on CrazyCircuits.com.

Software

In order to upload projects and code to the Robotics Board you’ll need to install some software. The software will run on any Mac, PC, or Linux computer with built in USB ports, which is pretty much most all computers these days.

First you’ll need to download the free Arduino IDE software from the Arduino Website. This is the computer program that will let you upload code to your Touch Board. Download version 1.8.4 for with Mac or PC. (Version 1.8.5 does not work with our board yet.)

https://www.arduino.cc/en/Main/OldSoftwareReleases#previous

Drivers for Mac and PC may be needed from this website.

https://kig.re/2014/12/31/how-to-use-arduino-nano-mini-pro-with-CH340G-on-mac-osx-yosemite .html

Arduino IDE

Millions of people around the world use the Arduino IDE software to interact with their Arduino Compatible development boards. Our Robotics Board is no different.

Before you start uploading code and projects to your Robotics Board we want to walk through a few basic sections of the Arduino IDE, as it can be a bit confusing for new users. These are tips and directions specific to our Touch Board, which means we won’t be explaining everything.

More or less you’re going to mostly be dealing with Sketch writing window and the Tools drop down Menu.

The Sketch writing window is where you type in or paste in your code. If you’re just following allow with our existing Project Guides you’ll mainly be doing a Copy and Paste into this window and hitting Upload.


Before you can upload your code you’ll need to select a few settings. (If you’re only ever going to be using our Touch Board these settings will rarely need to be changed in the future) Click
on the drop down Tool | menu at the top of your screen.
Mouse down to Board | and then choose Arduino Nano.

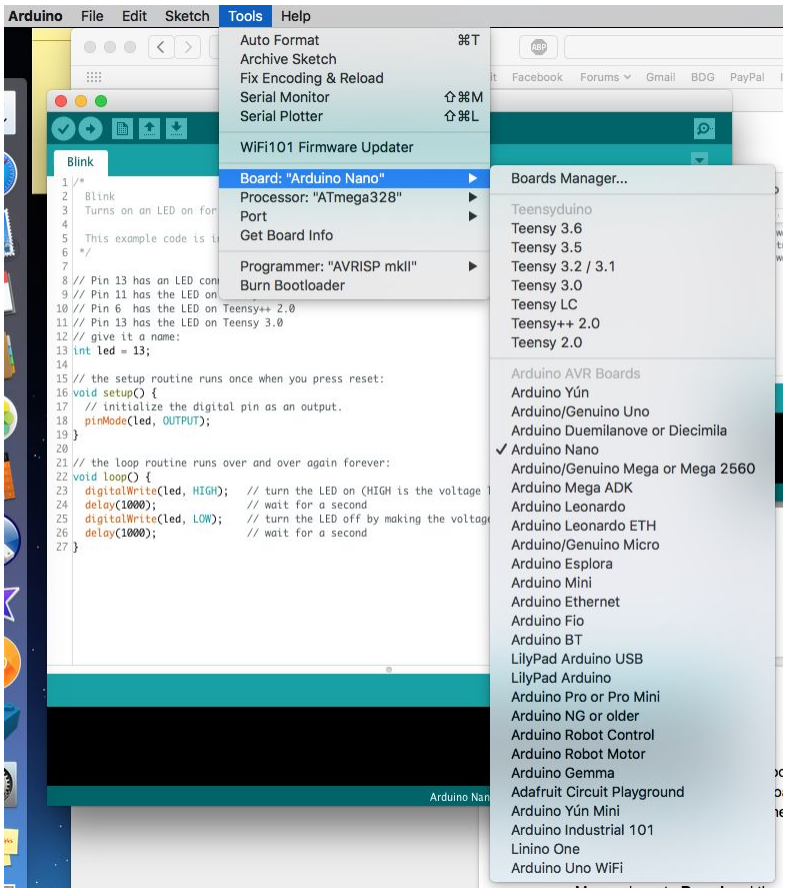
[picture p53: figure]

Next, plug in your Robotics Board to your computer.

Again, go to the Tools Menu and down to Port. Choose the USB Serial Option. Depending on if you’re using a Mac or PC, you may get different options.

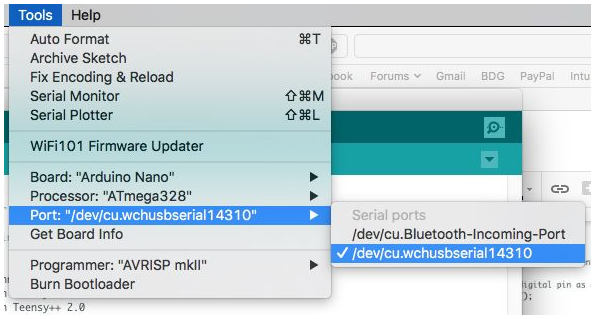
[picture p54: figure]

If you use different types of Arduino Boards, such as our Touch Board or a standard Arduino
Uno, you’ll need to change Board Types in the Tools | Menu.
Uploading | Code | and | Projects

Lets walk through a simple code upload to make sure that everything is installed and working properly.

We’re going to start by uploading the Arduino Blink Sketch to our board. This uses the built in LED (Pin 13) on the Robotics Board Board and makes its blink. If you want to you can hook up a Crazy Circuits LED to Pin 13 on the board via Conductive Tape.

1) Plug in your Robotics Board
2) Open the Arduino Software
3) Double check to make sure that you’ve selected the Arduino Nano from the Tools menu.
4) Make sure you’ve selected the Arduino Nano in Tools -> Port.
5) Copy and Paste the below code into the Arduino Sketch Window. (You can first delete everything else if you’d like.)
6) Otherwise, click the Upload button.

7) Check to see if your LED is blinking.

If you want to play around with the blink speed, chance the delay(1000) code to a higher or lower number. A number of 1000 equals 1 second of time. Once you’ve changed the number click the Upload button to send the new code to the Touch Board.

Example Blink Code (Same as built into the Arduino Software)

/*
Blink
Turns on an LED on for one second, then off for one second, repeatedly.

This example code is in the public domain.
*/

// Pin 13 has an LED connected on most Arduino boards. // Pin 11 has the LED on Teensy 2.0
// Pin 6 has the LED on Teensy++ 2.0
// Pin 13 has the LED on Teensy 3.0
// give it a name:
int led = 13;

// the setup routine runs once when you press reset: void setup() {
// initialize the digital pin as an output.
pinMode(led, OUTPUT);
}

// the loop routine runs over and over again forever:
void loop() {
digitalWrite(led, HIGH); // turn the LED on (HIGH is the voltage level)
delay(1000); | // wait for a second
digitalWrite(led, LOW); // turn the LED off by making the voltage LOW
delay(1000); | // wait for a second
}

RGB LED

You can control the color of an RGB LED using some simple code.

Below is a simple diagram and code. Try building this and uploading the project.

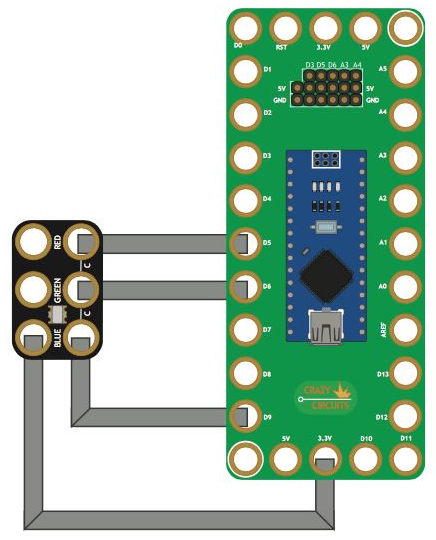
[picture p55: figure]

int redPin= 5;
int greenPin = 6;
int bluePin = 9;

void setup() {
pinMode(redPin, OUTPUT);
pinMode(greenPin, OUTPUT); pinMode(bluePin, OUTPUT);
}

void loop() {
setColor(255, 0, 0); // Red Color delay(1000);
setColor(0, 255, 0); // Green Color delay(1000);
setColor(0, 0, 255); // Blue Color delay(1000);
setColor(255, 255, 255); // White Color delay(1000);
setColor(170, 0, 255); // Purple Color
delay(1000);
}

void setColor(int redValue, int greenValue, int blueValue) { analogWrite(redPin, redValue);
analogWrite(greenPin, greenValue); analogWrite(bluePin, blueValue);
}

Simple | Tone | Generation

Use a Piezo Speaker to generate some sound.

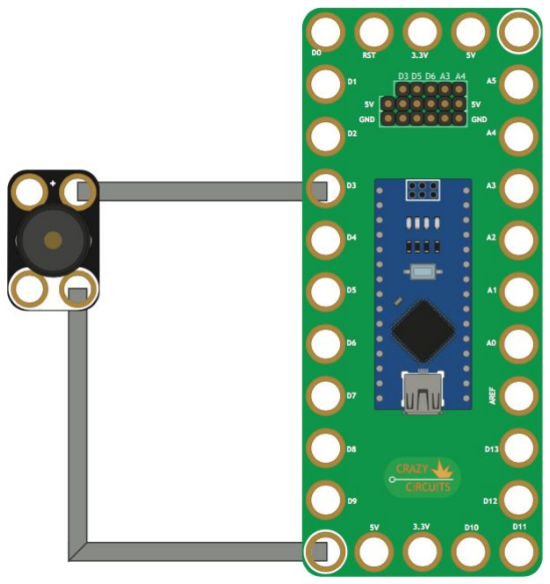
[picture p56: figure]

const int buzzer = 3; //buzzer to arduino pin 3

void setup(){

pinMode(buzzer, OUTPUT); // Set buzzer - pin 3 as an output

}

void loop(){

tone(buzzer, 1000); // Send 1KHz sound signal...
delay(1000); | // ...for 1 sec
noTone(buzzer); | // Stop sound...
delay(1000); | // ...for 1sec

}

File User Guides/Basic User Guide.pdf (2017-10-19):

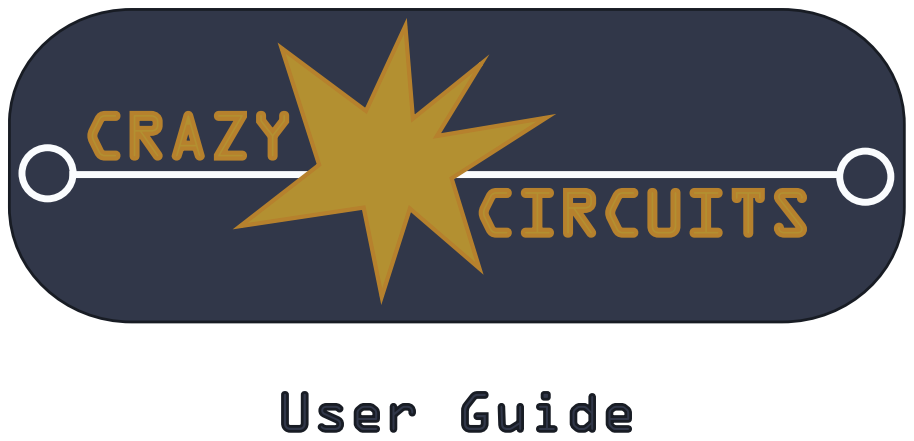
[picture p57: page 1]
CRAZY; CIRCUITS; User Guide

## TABLE OF CONTENTS

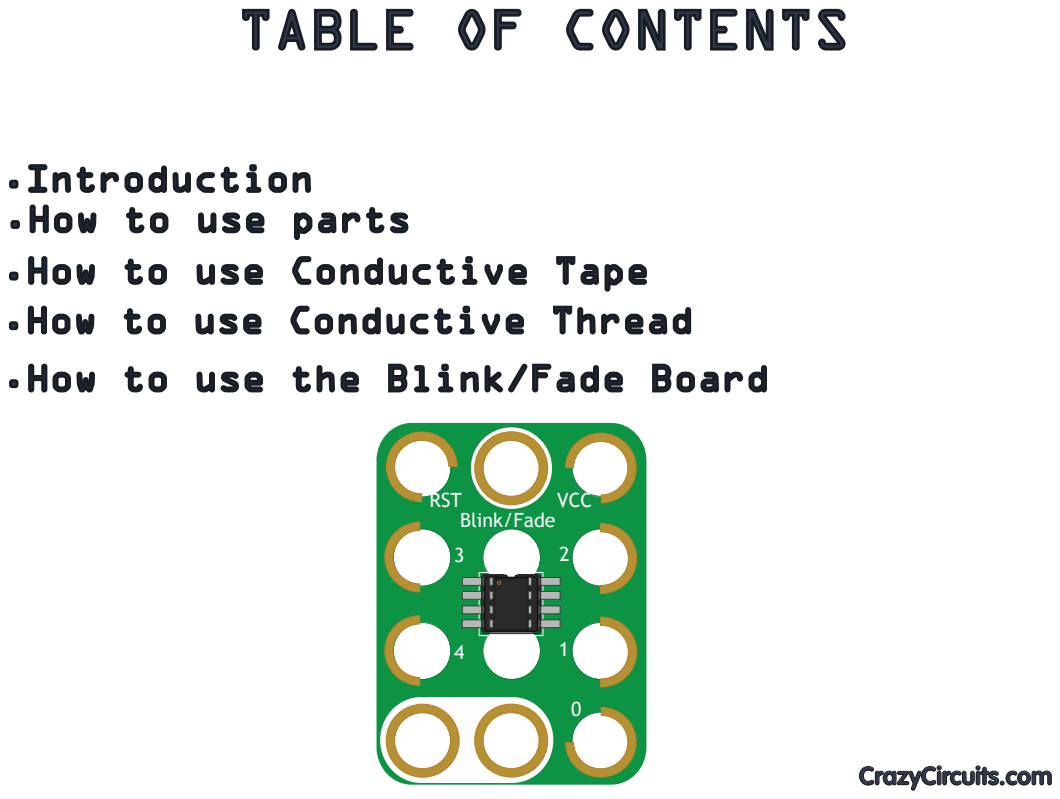
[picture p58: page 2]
CrazyCircuits.com; RST; VCC; Blink/Fade

.Introduction
.How to use parts
.How to use Conductive Tape
.How to use Conductive Thread
.How to use the Blink/Fade Board

# Welcome !

Before you start using Crazy Circuits please read over this Basic User Guide. Inside

you'll find tips and tricks on how our parts connect together, how to use our special Conductive Tape and Thread, as well as some example circuits.

This guide does NOT contain information on our Robotics and Touch Boards. Those

parts have their own user guides which can be found on CrazyCircuits.com.

Individual project guides with written directions, diagrams, and videos can be found

Share your projects with other Crazy Circuits users on our web forums. Enter your

projects into our monthly contests for the chance to win prizes and gift cards.

Follow us on Facebook to see our weekly project builds and videos as well as special

facebook.com/BrownDogGadgets

## How to use parts

Crazy Circuits parts come in a wide variety of size, shape, and colors but all work the

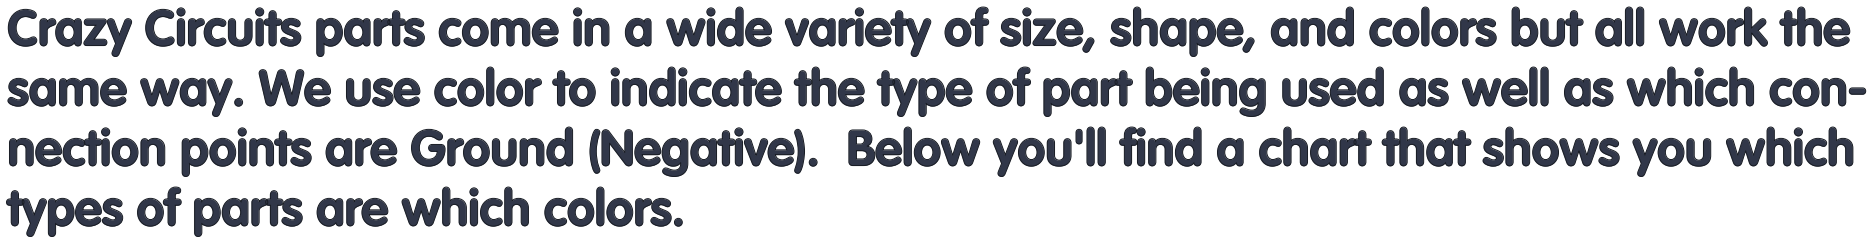
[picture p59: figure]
types of parts are which colors.

same way. We use color to indicate the type of part being used as well as which connection points are Ground (Negative). Below you'll find a chart that shows you which

White - Always Ground (Negative)
Black - Outputs. Parts that do something, such as LEDs.
Red - Inputs. Parts that react to the world, such as buttons.
Orange - Power Inputs.
Purple - Connectors. Parts that adapt other parts into Crazy Circuits.
Green - Programed Parts. Parts that are either preprogramed or can be programed.

## How parts connect

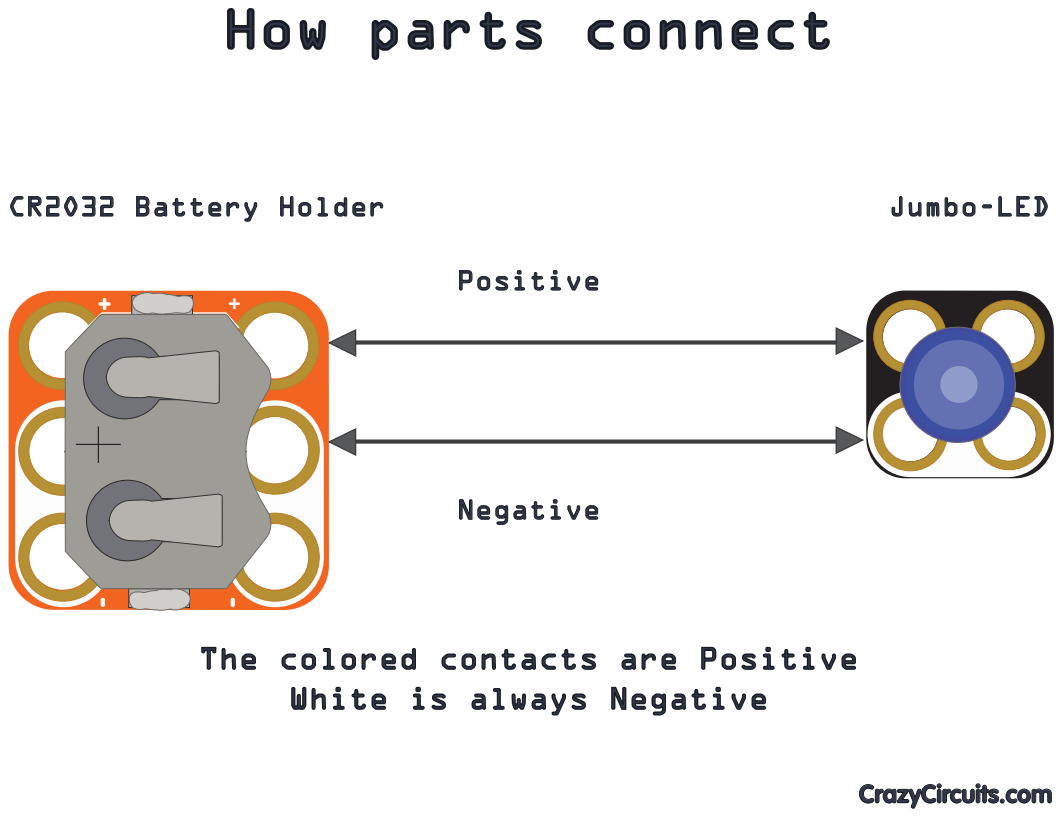
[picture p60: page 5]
Negative; Positive; CR2O32 Battery Holder; Jumbo-LED

The colored contacts are Positive

White is always Negative

## Push Button

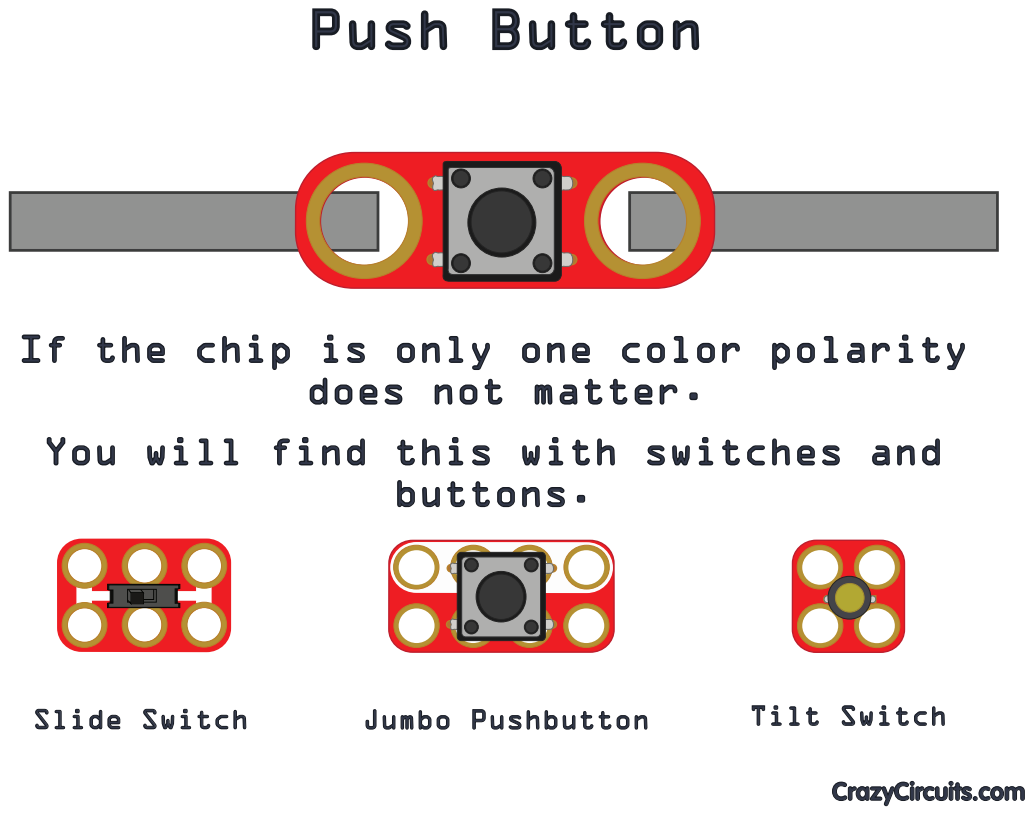
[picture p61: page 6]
buttons.; Slide Switch; Jumbo Pushbutton; Tilt Switch

If the chip is only one color polarity

does not matter.

You will find this with switches and

## How to use Conductive Tape

Crazy Circuits parts work with a variety of conductive materials, but our favorite is our

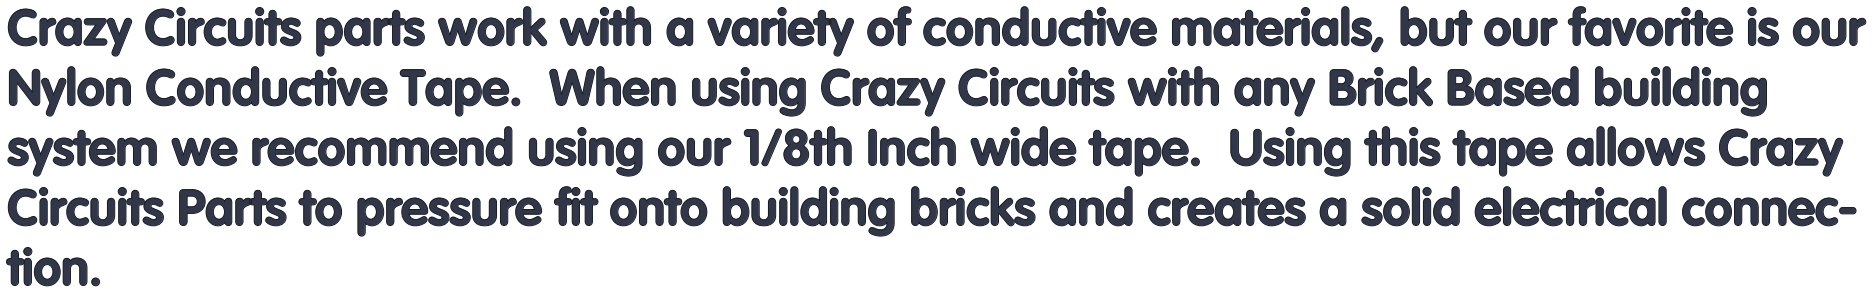
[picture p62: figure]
tion.

Nylon Conductive Tape. When using Crazy Circuits with any Brick Based building system we recommend using our 1/8th Inch wide tape. Using this tape allows Crazy Circuits Parts to pressure fit onto building bricks and creates a solid electrical connec-

In the next couple of pages we show you some basic tips and tricks to using Conduc-

tive Nylon Tape with building bricks. Follow these simple directions and your projects

Note: Never use copper foil tape with building bricks. It breaks far too easily and is

near impossible to remove from building bricks.

## Halfway over a stud

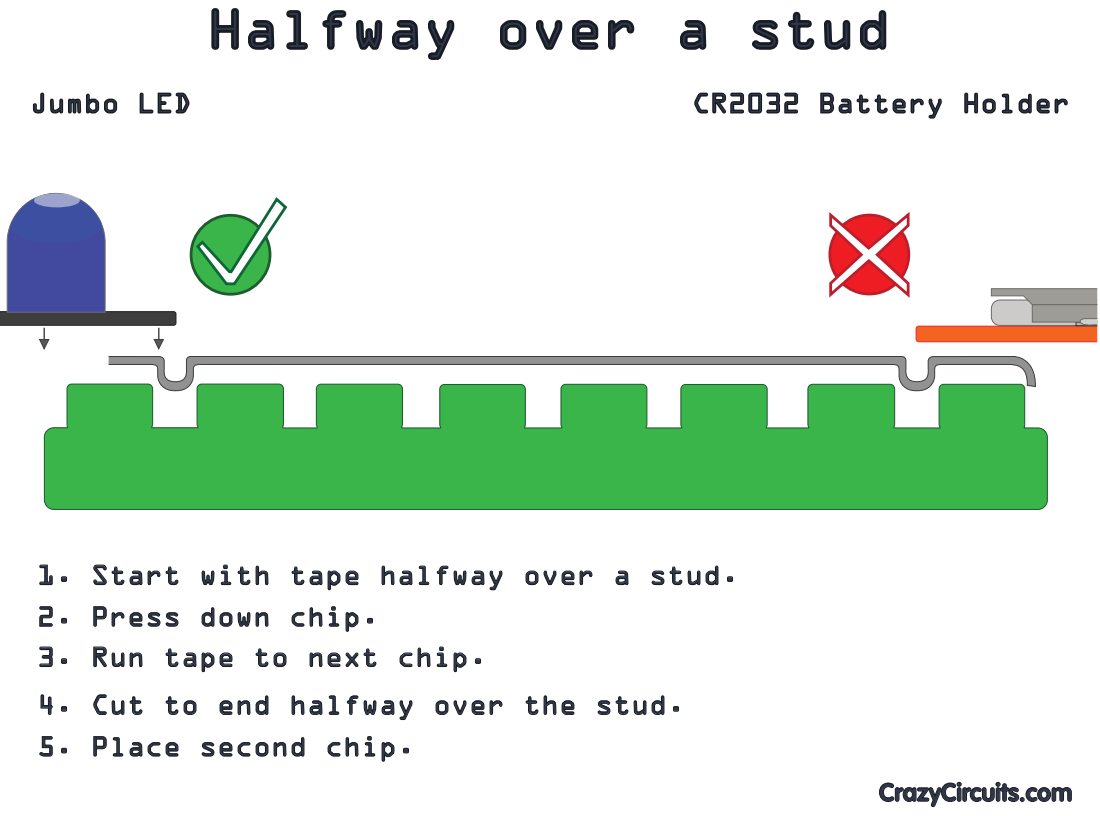
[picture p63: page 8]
Jumbo LED; CR2032 Battery Holder

1. Start with tape halfway over a stud.
2. Press down chip.
3. Run tape to next chip.
4. Cut to end halfway over the stud.
5. Place second chip.

## Top View

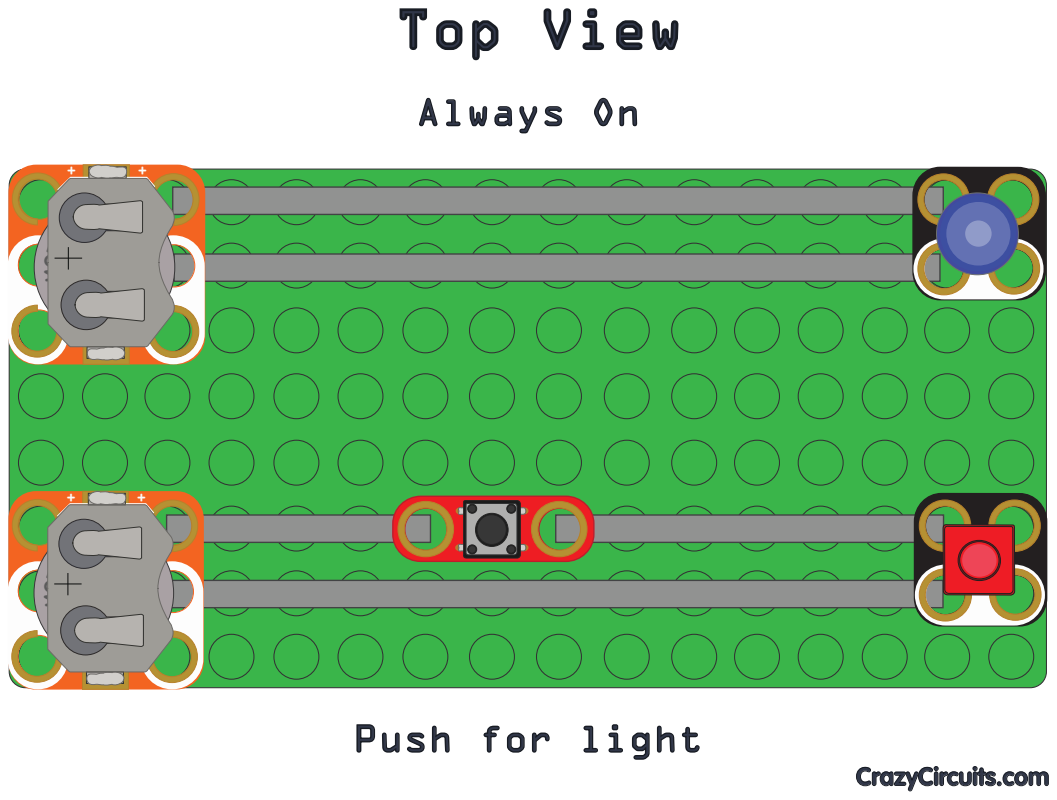
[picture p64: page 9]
+ Battery; UB TTO; N CELL; Always On

Push for light

## Tape tips and tricks

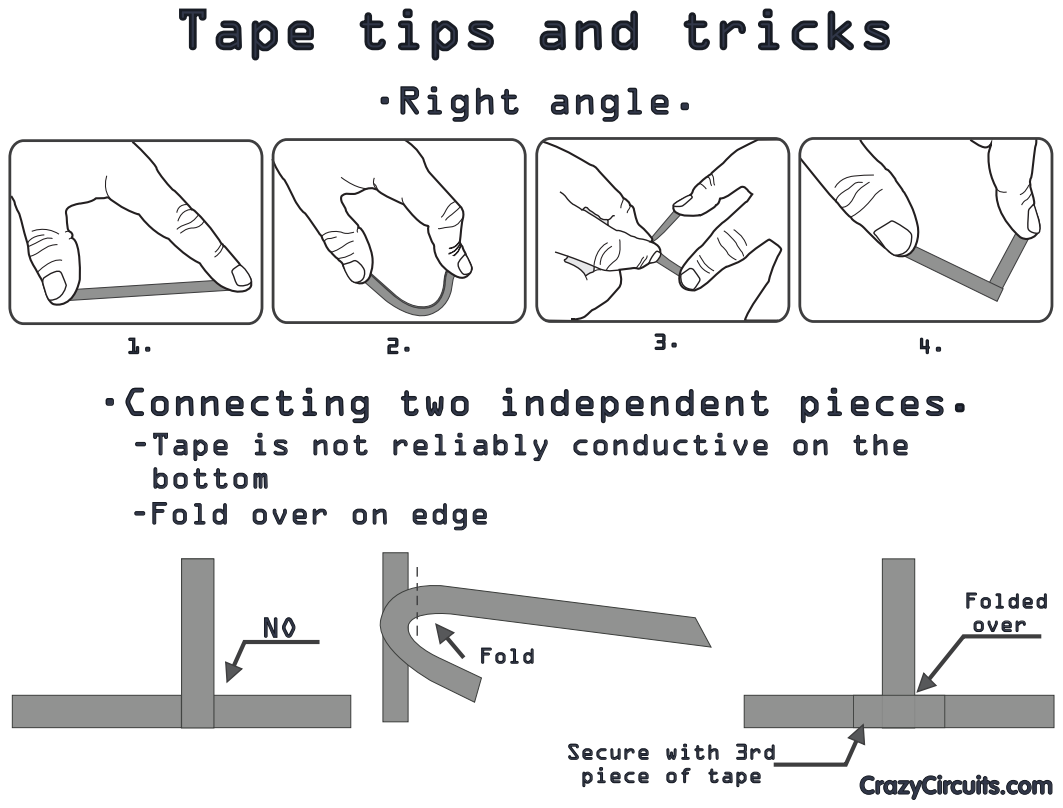
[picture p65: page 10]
∙Right angle.; Folded over; Fold

∙Connecting two independent pieces.
-Tape is not reliably conductive on the
bottom
-Fold over on edge

Secure with 3rd
piece of tape

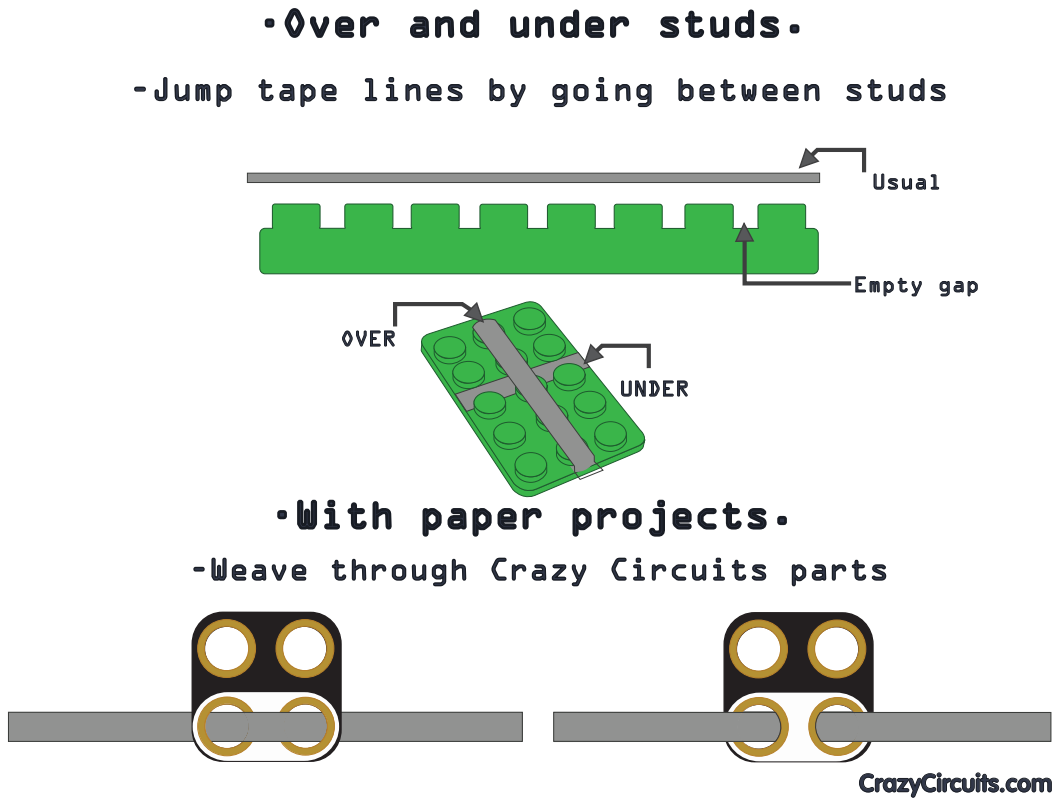
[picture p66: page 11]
OVER; UNDER; Empty gap; Usual

∙Over and under studs.

-Jump tape lines by going between studs

∙With paper projects.

-Weave through Crazy Circuits parts

## How to use Conductive Thread

All Crazy Circuits parts are naturally compatible with Conductive Thread for sewing. If

you're familiar with sewing just think of Crazy Circuits parts as really fancy buttons.

When using Conductive Thread for sewing follow these tips.

- Conductive Thread should never be used with a sewing machine.
- Conductive Thread acts just like wire or tape. Cross a positive and a negative line of
- Be careful about loose bits of thread. These are the #1 cause of issues.
- Metal button snaps are great ways to add switches to sewing projects.
- Never machine wash projects. If you must wash a project, remove all batteries, hand wash, and left air dry.
- In very complicated sewing projects you may wish to use a sewing machine and regular thread to secure your lines of conductive thread. This prevents loose thread odds and

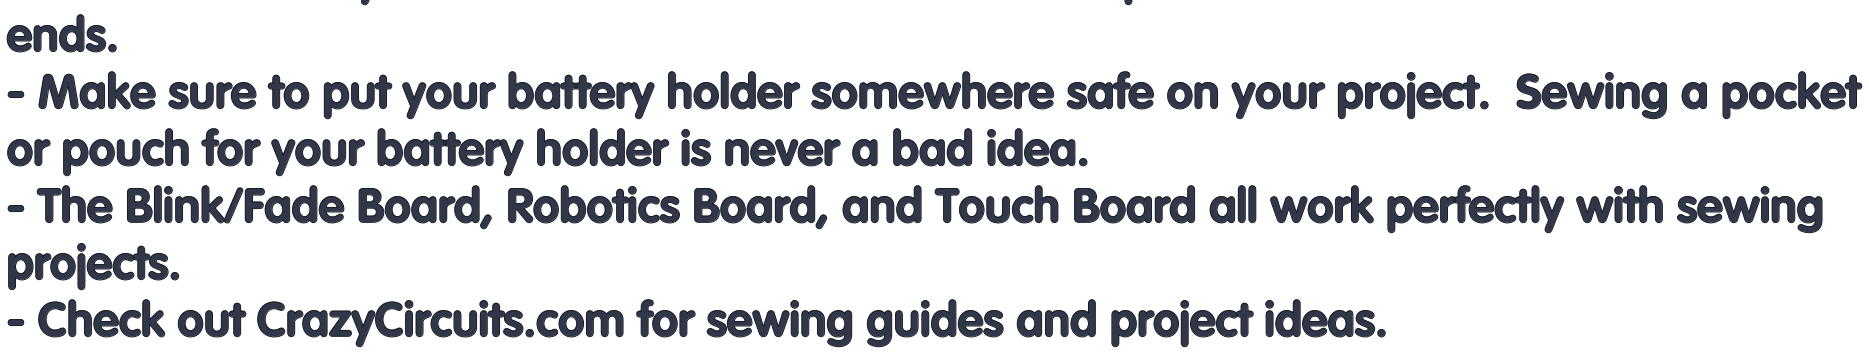
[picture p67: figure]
ends.; projects.

- Make sure to put your battery holder somewhere safe on your project. Sewing a pocket or pouch for your battery holder is never a bad idea.
- The Blink/Fade Board, Robotics Board, and Touch Board all work perfectly with sewing
- Check out CrazyCircuits.com for sewing guides and project ideas.

## Thread Guide

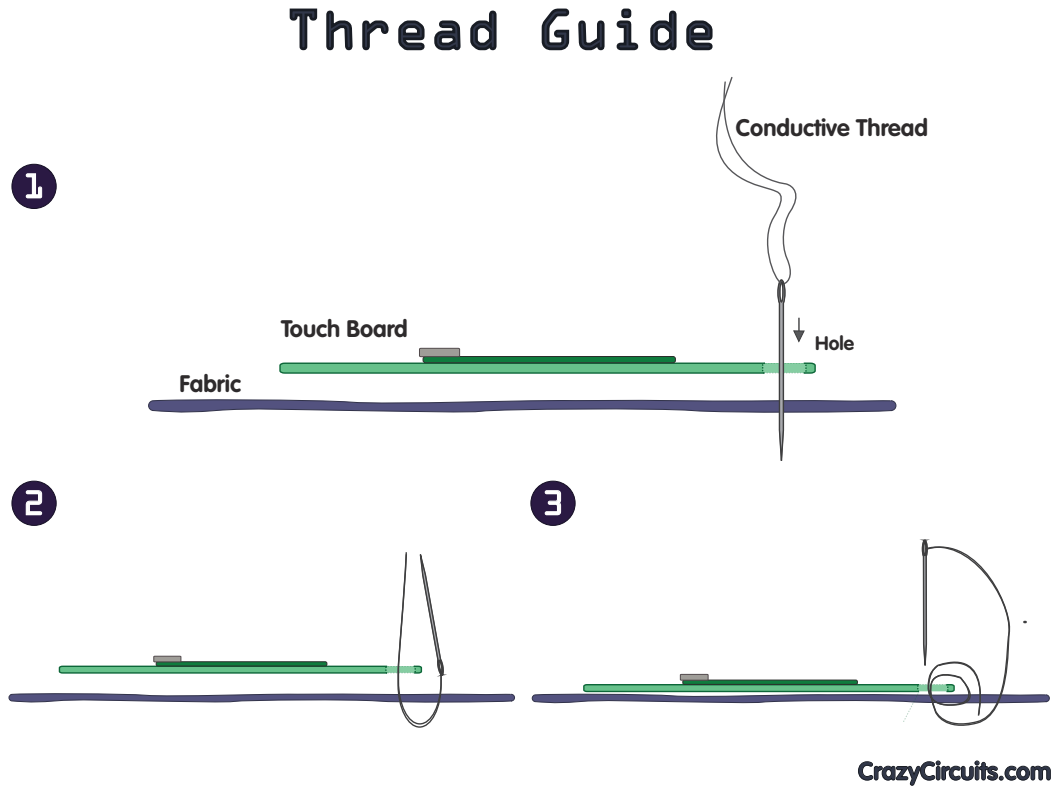
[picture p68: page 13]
Fabric; Touch Board; Conductive Thread; Hole

## Bracelet using snaps

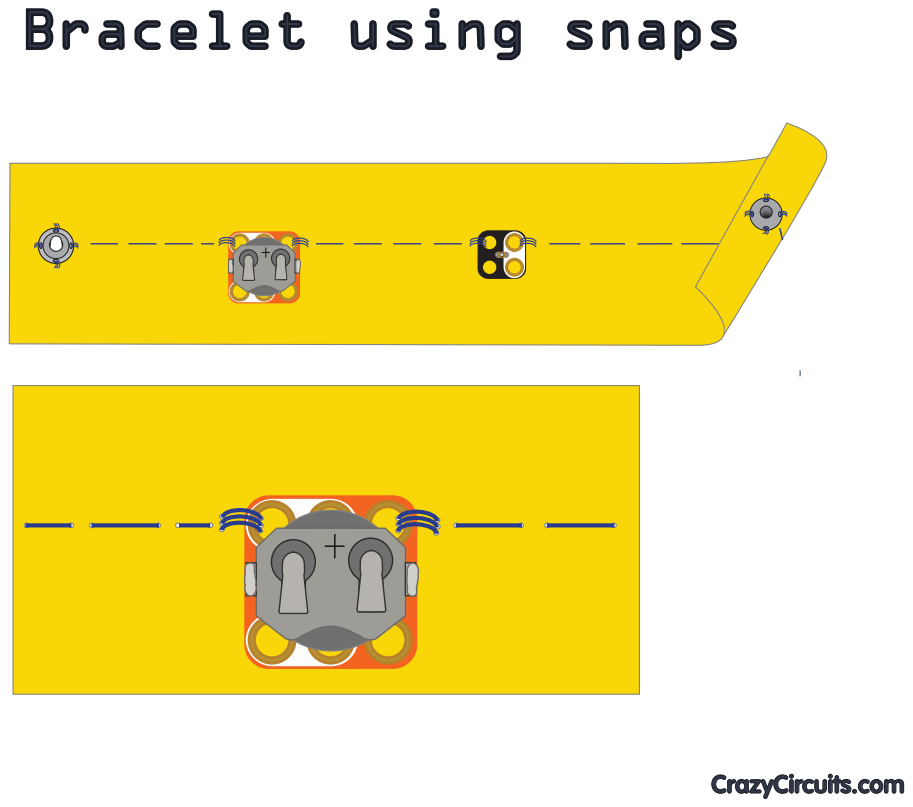
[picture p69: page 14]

## Blink Fade Board

The Crazy Circuits Blink/Fade Board is a fun way to add effects to your LEDs. The Board

has the ability to make LEDs fade, blink, and alternate blinking.

Connect the Blink/Fade Board together the same way you'd hook up any other part.

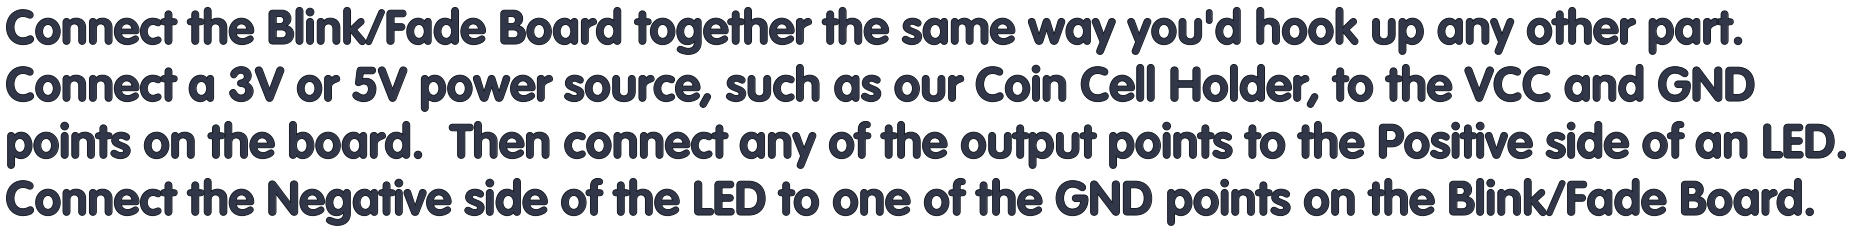
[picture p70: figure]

Connect a 3V or 5V power source, such as our Coin Cell Holder, to the VCC and GND points on the board. Then connect any of the output points to the Positive side of an LED. Connect the Negative side of the LED to one of the GND points on the Blink/Fade Board.

You can easily hook up several LEDs to the same effect spot by wiring them up in Parallel.

It is also entirely possible to run LEDs off every effect spot at the same time.

The Blink/Fade Board also works well with Conductive Thread. Directions and use will not

## Blink Fade Schematic

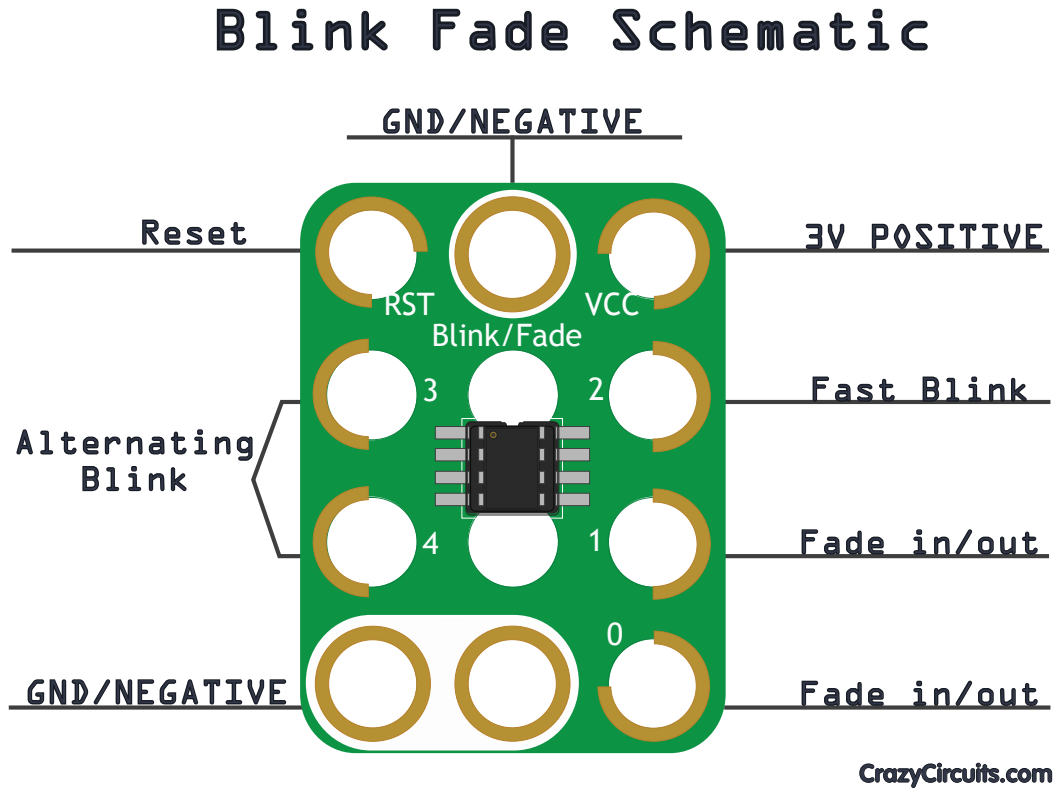
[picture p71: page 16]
RST; VCC; Blink/Fade; Alternating Blink; Reset; 3V POSITIVE; Fast Blink; GND/NEGATIVE

Fade in/out

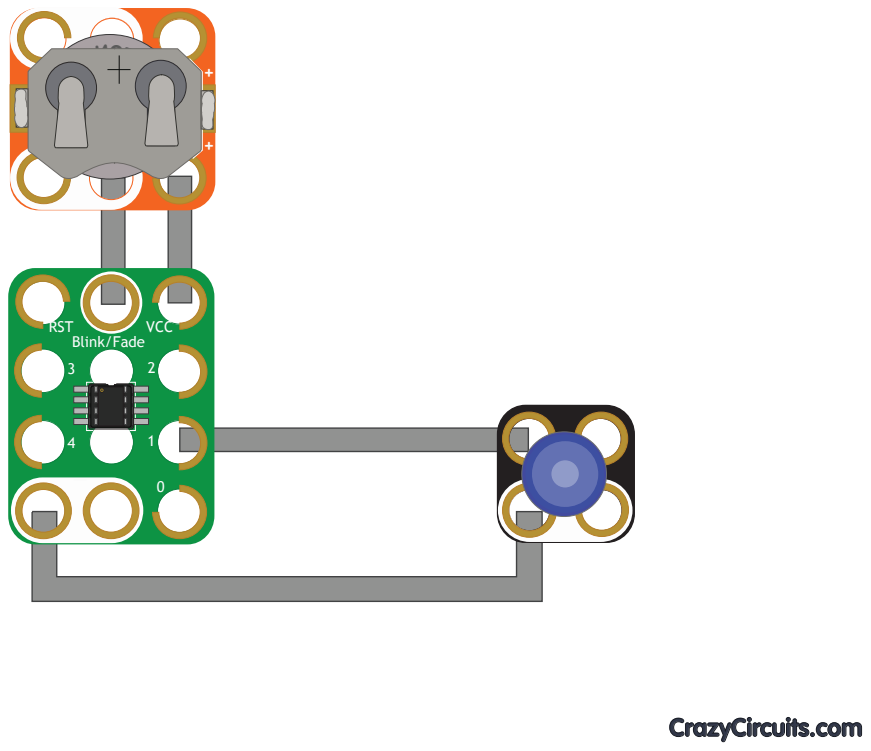
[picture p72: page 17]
RST; VCC; Blink/Fade; Battery

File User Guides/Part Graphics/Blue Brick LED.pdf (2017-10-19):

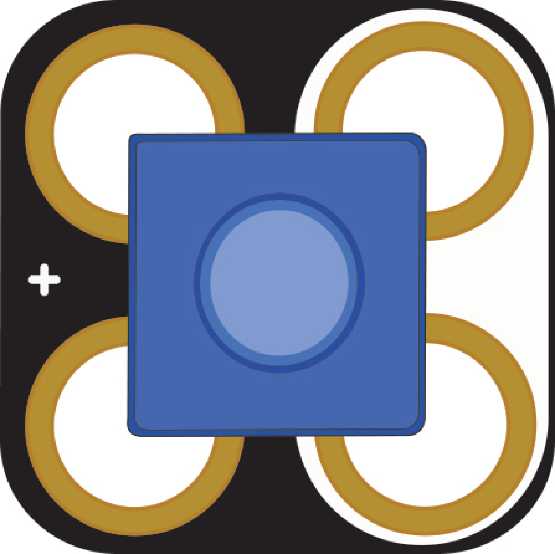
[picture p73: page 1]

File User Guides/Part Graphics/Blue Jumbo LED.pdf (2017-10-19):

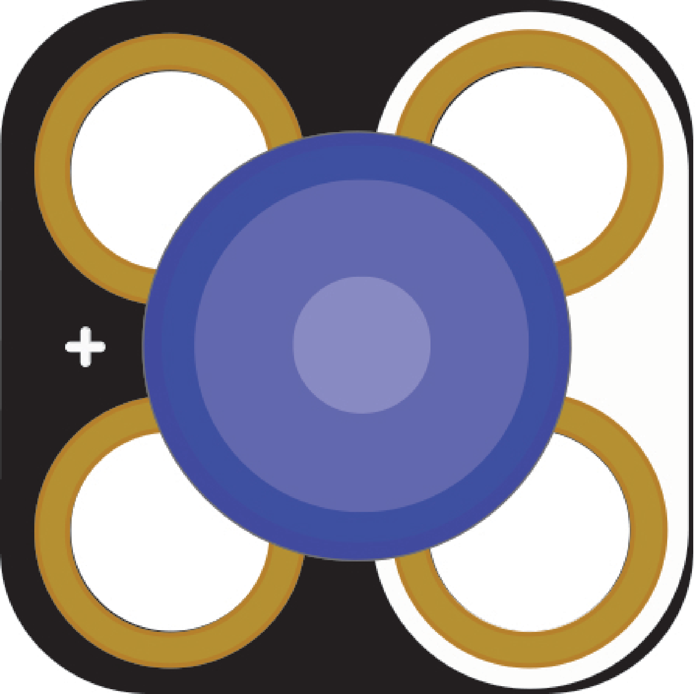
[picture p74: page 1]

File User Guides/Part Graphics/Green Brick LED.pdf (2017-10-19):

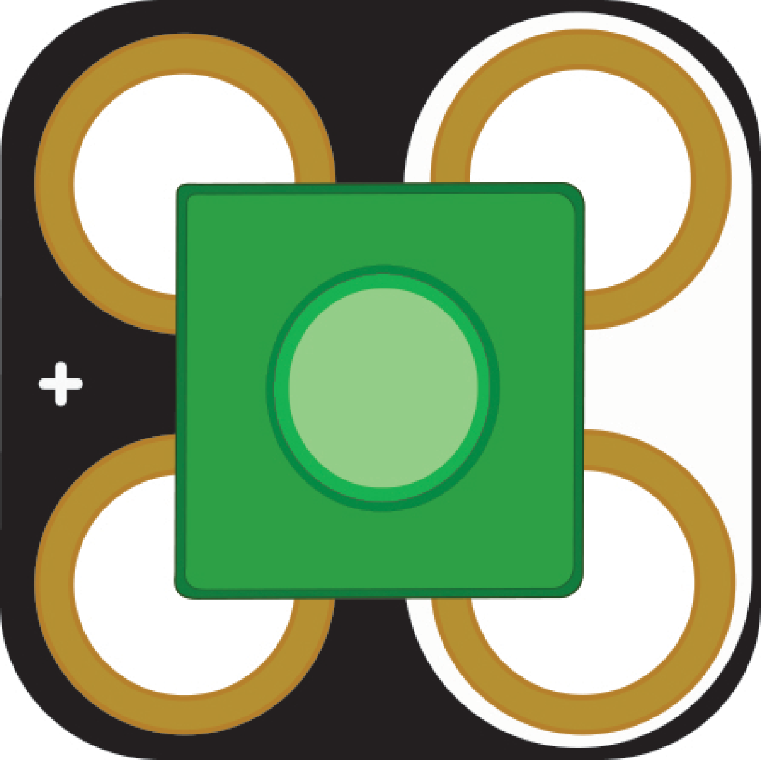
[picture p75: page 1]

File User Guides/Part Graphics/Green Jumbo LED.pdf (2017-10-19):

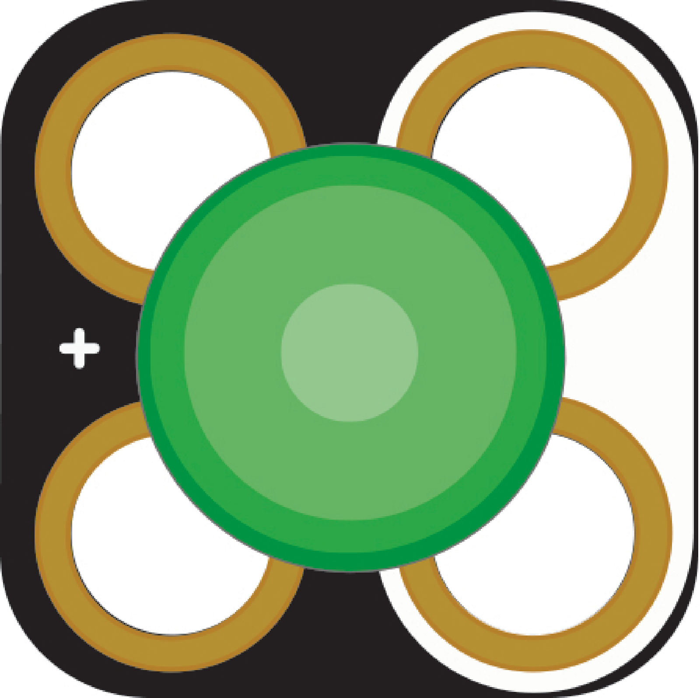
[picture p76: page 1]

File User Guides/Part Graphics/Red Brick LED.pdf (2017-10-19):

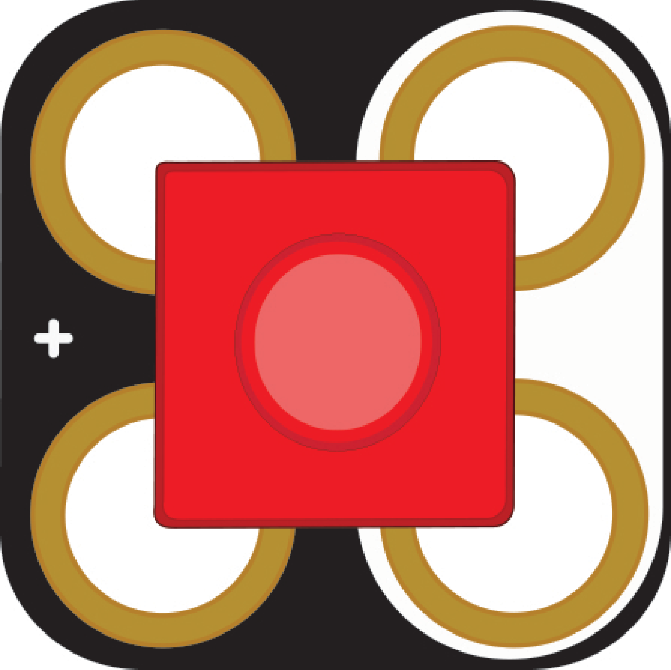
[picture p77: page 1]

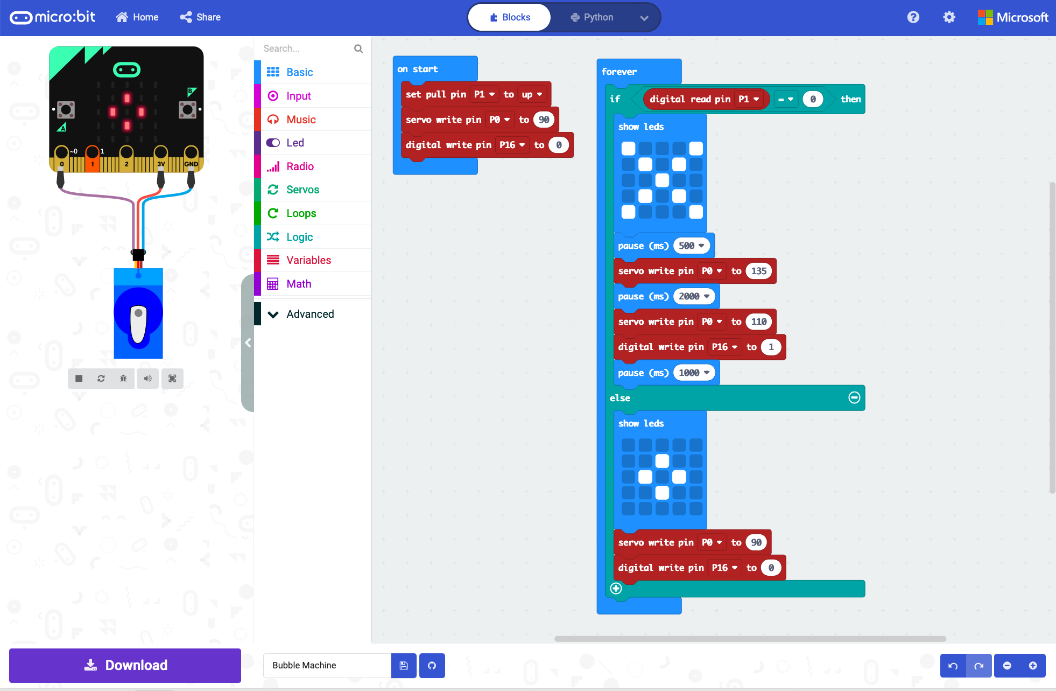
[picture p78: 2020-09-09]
Projects/Bubble Machine/Images/microbit-makecode.png

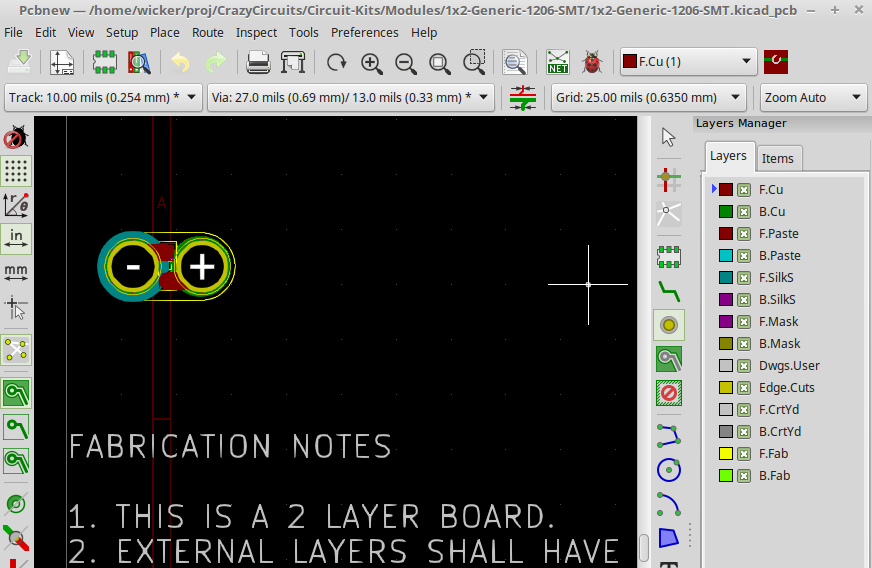
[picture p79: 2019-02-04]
Development/images/8-layers-setup.png

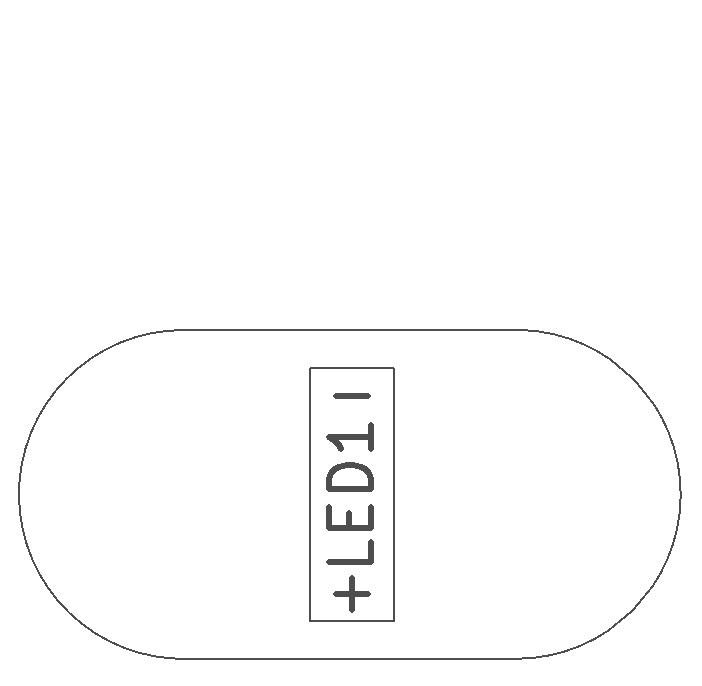
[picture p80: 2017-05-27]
Circuit-Kits/Modules/1x2-LED-1206-SMT/assembly.png

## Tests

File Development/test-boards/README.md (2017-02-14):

# Rewire Circuit Test Boards 
### Test boards to verify library and to prepare for manufacturing

These are historical test boards to try out different things.

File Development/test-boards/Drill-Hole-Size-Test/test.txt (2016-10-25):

Yes, I was assembling an RGB LED circuit today with legos to try out several different copper tapes.  I found it was difficult to put legos next to the PCBs because they were a hair too big.  Shrinking them according to the attached drawing will help.  I'm not sure what the tolerance is on the PCB routing, so take the number labeled max and subtract from that.  

I also found the best way to connect the PCBs to legos and other components was to run tape up and over the lego pegs.  The 194 hole sample you provided was just a hair too small for this, 196 should fit well given tolerances.  Pics attached of this too.  

Let me know if you have any questions.

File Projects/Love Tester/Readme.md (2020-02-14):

Resource files for the Love Tester project.

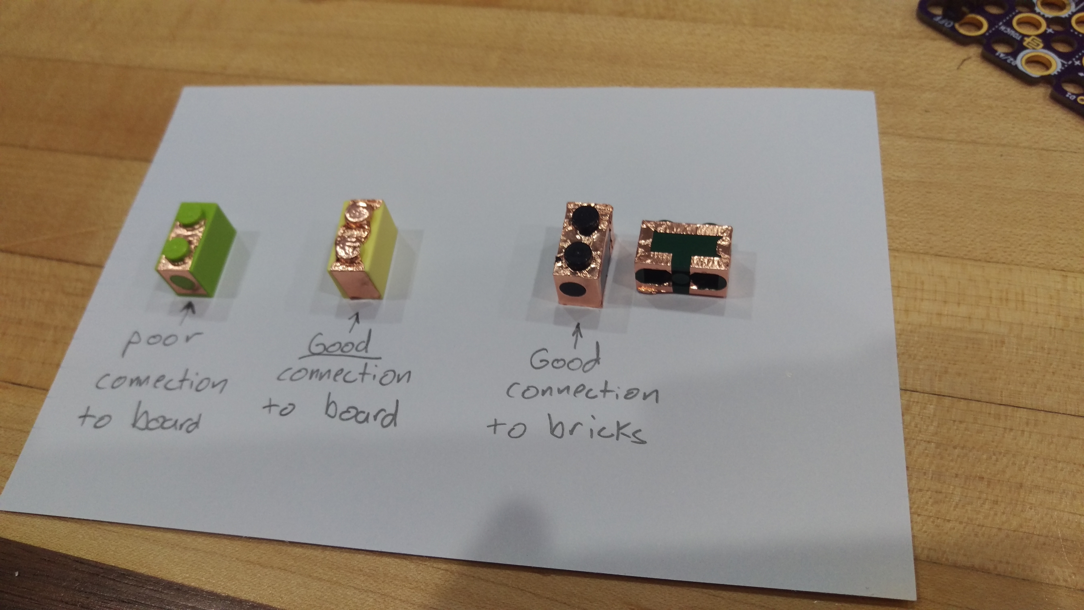
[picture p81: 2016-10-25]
Development/test-boards/Drill-Hole-Size-Test/IMAG0543.jpg

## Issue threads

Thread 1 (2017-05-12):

How to fit into LEGO pieces?

weeberp, 2017-05-12:
I've seen that PCBs for mini Arduino, Teensy ... have no holes in the inside, so they can not fit into the standard lego bricks. These bricks should not have pins in the inside either. It is not like this?.
You would have to define these PCBs so that they have holes in them, or make a hole-only PCB so they would get underneath and raise this PCB (Well I'm not too sure about this second).
Thanks.

Joshua-BrownDogGadgets, 2017-05-12:
Good questions.

We made that design choice on purpose.  Due to the many small through hole pins on a NANO or TEENSY board we could not get things to line up with LEGO holes.  The exception to this is the ATTiny85 where we were able to get things worked out for both TH and SMT versions of the 85.

The way we use the NANO and TEENSY boards is to just slightly elevate the PCB with legos.  You can see that in many of our pictures.  Even using a few 1x2 or a couple of 1x8 thin LEGO strips is enough to  elevate the PCBs from any LEGO structure.

https://github.com/BrownDogGadgets/CrazyCircuits/blob/master/Crazy%20Circuits%20Arduino.JPG

It's annoying, but it's the only way we could get things working.  Spacing just is way too difficult.

weeberp, 2017-05-13:
OK, thanks, I see it better.
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

Joshua-BrownDogGadgets, 2017-05-13:
Bingo.  Just use a 1 or 2 stud wide brick.  That works just fine as as a base.

For a couple of projects we also have them hanging off the sides of a brick board.  It really depends on your project.

Closed 2017-05-13.

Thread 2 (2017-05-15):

There are no resistors, capacitors ...?

weeberp, 2017-05-15:
Would not it be necessary to include a resistor on the PCB itself? For example for LED (although in arduino you can activate pull-up) to use as output. Or for LDR or use button as input.
And some capacitor for the 555 timer?

https://github.com/BrownDogGadgets/CrazyCircuits/tree/master/Circuit-Kits/Modules/2x2-LED-TH-2.54mm-Pitch
https://github.com/BrownDogGadgets/CrazyCircuits/tree/master/Circuit-Kits/Modules/1x3-Button-Momentary
https://github.com/BrownDogGadgets/CrazyCircuits/tree/master/Circuit-Kits/Modules/2x2-CdS-Photocell-TH
https://github.com/BrownDogGadgets/CrazyCircuits/tree/master/Circuit-Kits/Modules/3x4-555-Timer-8DIP-Breakout
thanks.

Joshua-BrownDogGadgets, 2017-05-15:
It's not necessary to include one.  Not for the low voltages we're using with the LEDs.  The life of the LED may be diminished a bit, but not in any noticeable way.

We're not getting the LDR or 555 manufactured any time soon, so we're not even thinking about that.

The buttons are fine the way they are.  If someone really wants to add in a resistor for a project they can do so via a screw terminal.  We have a few solutions for how to add in caps or resistors in the future for projects.

weeberp, 2017-05-15:
Ok, Batery 3V CR2032 and 3,3V for Led is right, but 5V from Arduino Nano, I do not think so, some LEDs if supported by others not.
Screwing it is a good solution.

Joshua-BrownDogGadgets, 2017-05-17:
We've done a couple of projects using LEDs off our boards WITHOUT resistors and they work fine.  The big issue for most of them is that you will decrease the life of the LEDs.  This may mean that you'll only get 5,000 hours of use out of it instead of 10,000 hours.  That being said, these are inexpensive LEDs so we're not really worried about them.

Closed 2017-05-17.

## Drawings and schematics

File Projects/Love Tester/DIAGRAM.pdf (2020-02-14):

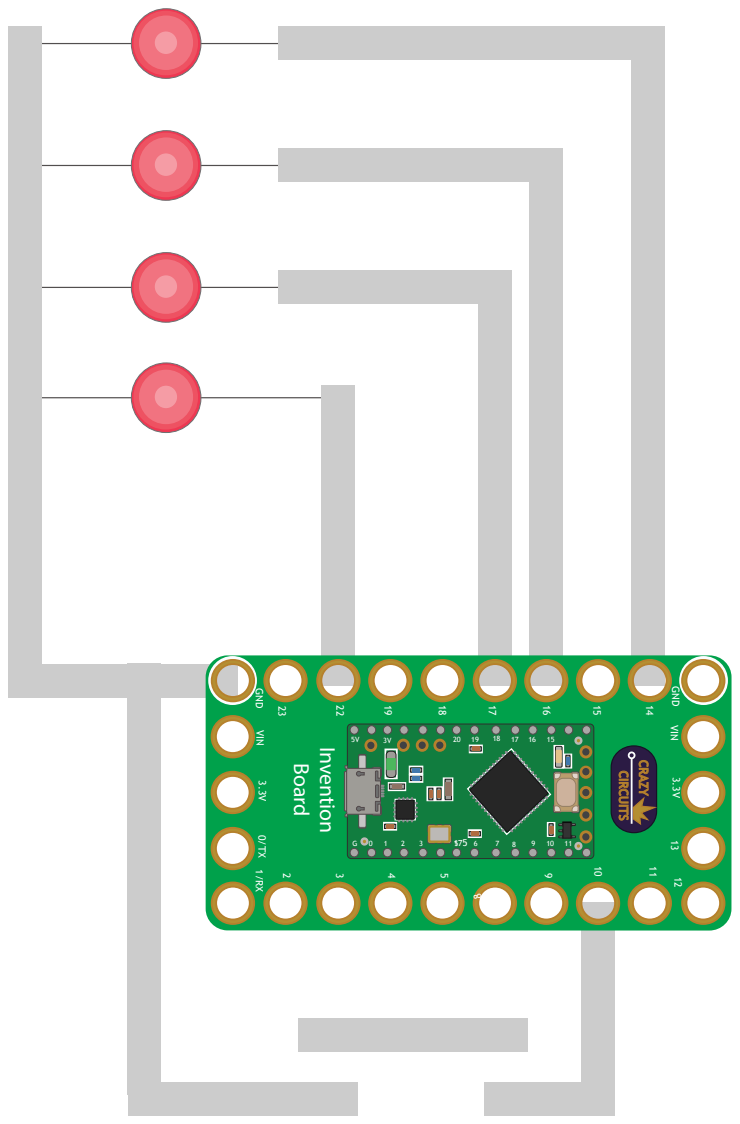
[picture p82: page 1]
VIN; GND; CRAZY; CIRCUITS; Invention Board

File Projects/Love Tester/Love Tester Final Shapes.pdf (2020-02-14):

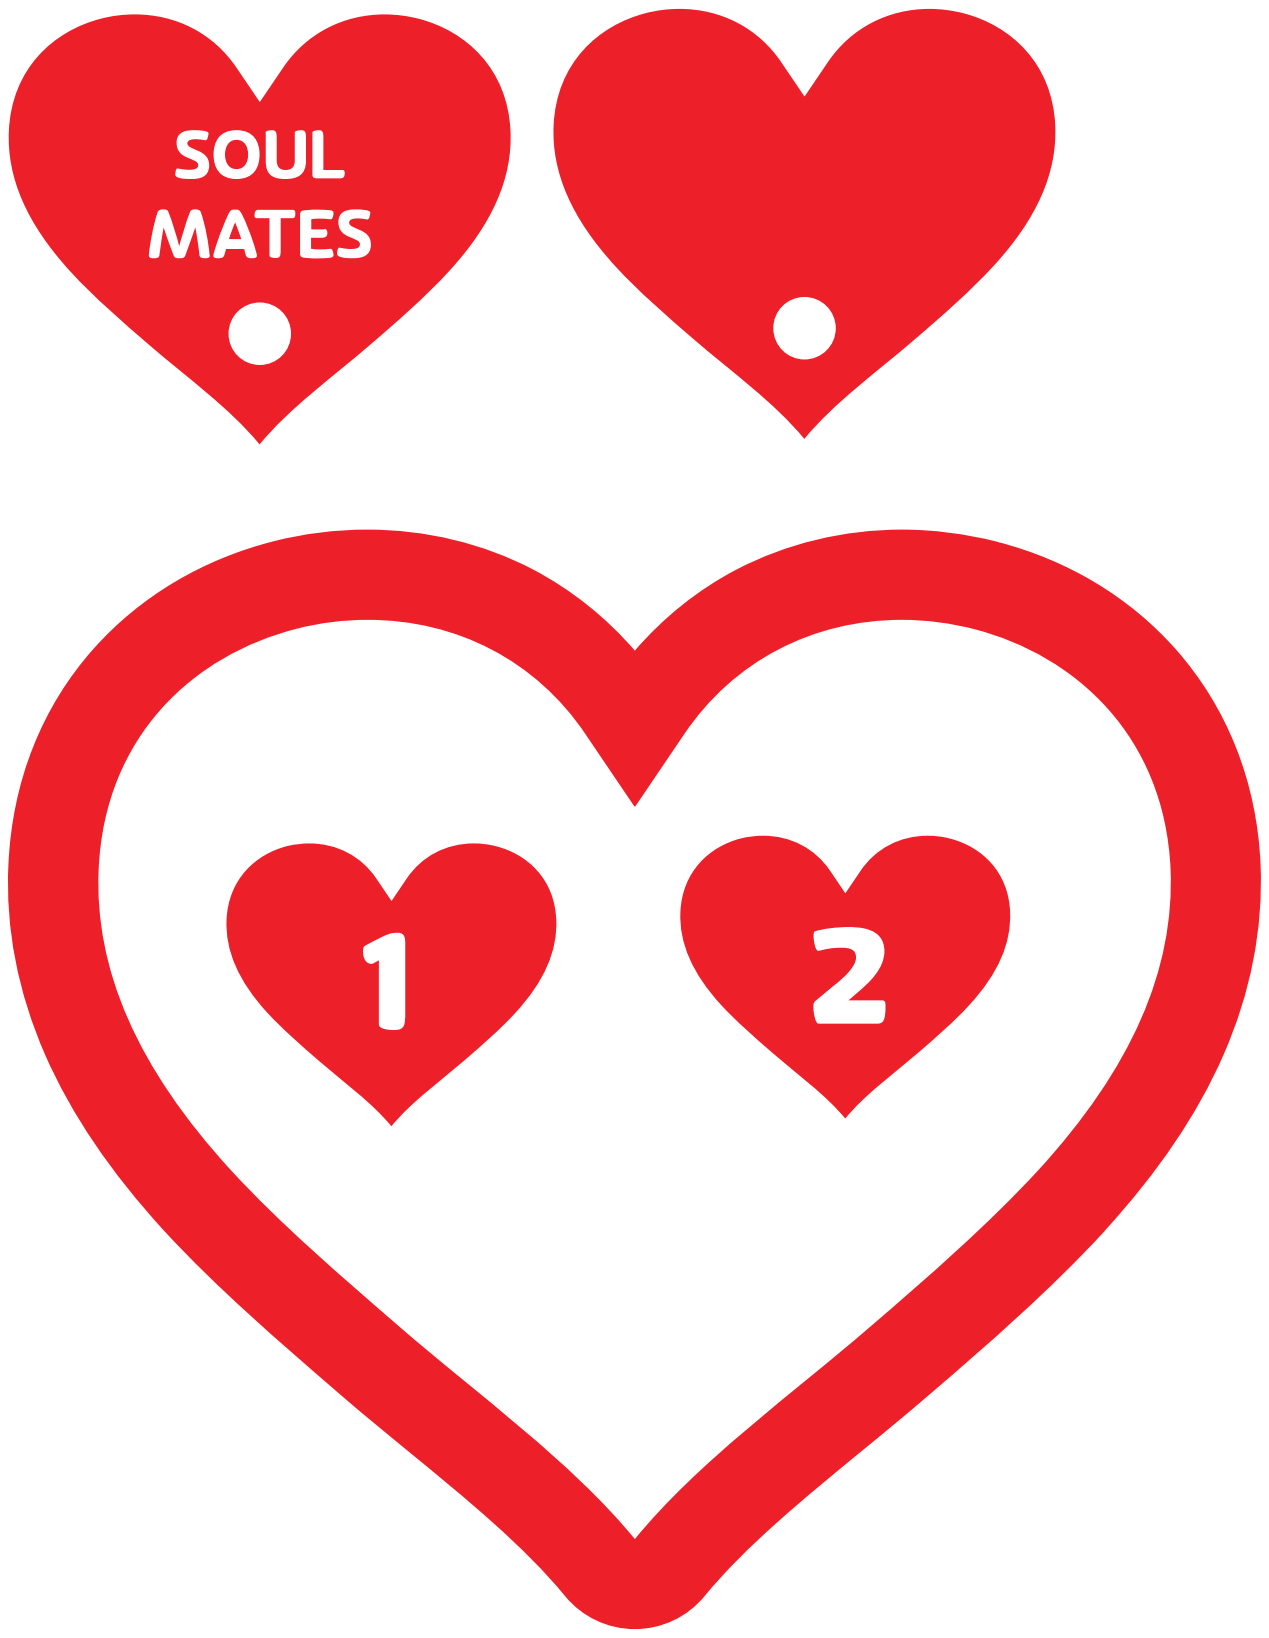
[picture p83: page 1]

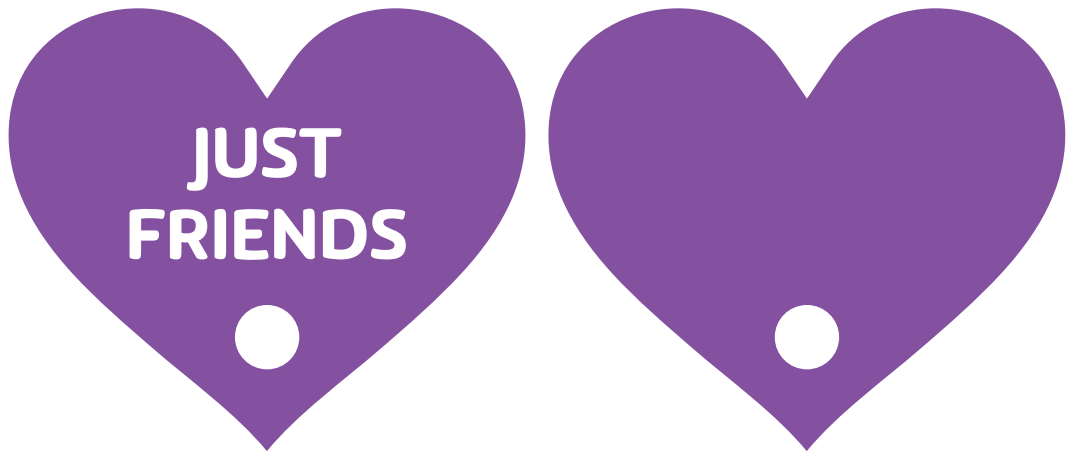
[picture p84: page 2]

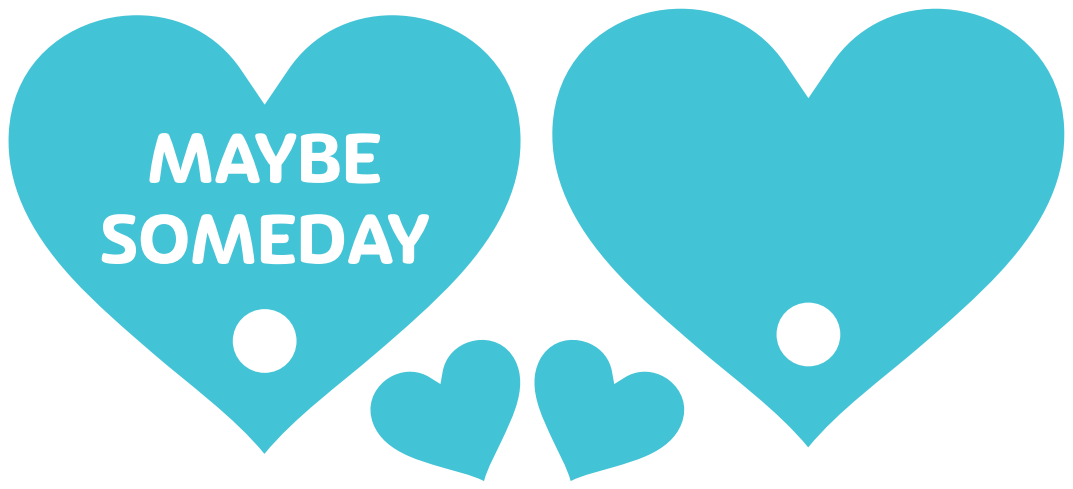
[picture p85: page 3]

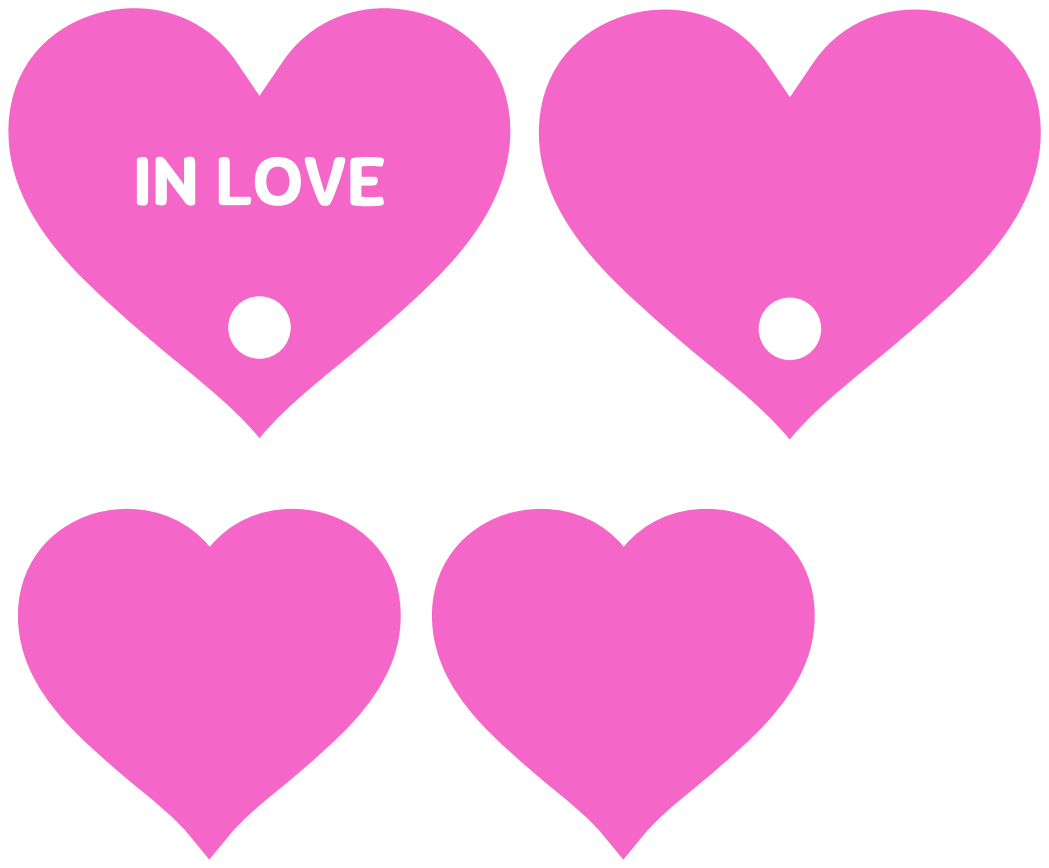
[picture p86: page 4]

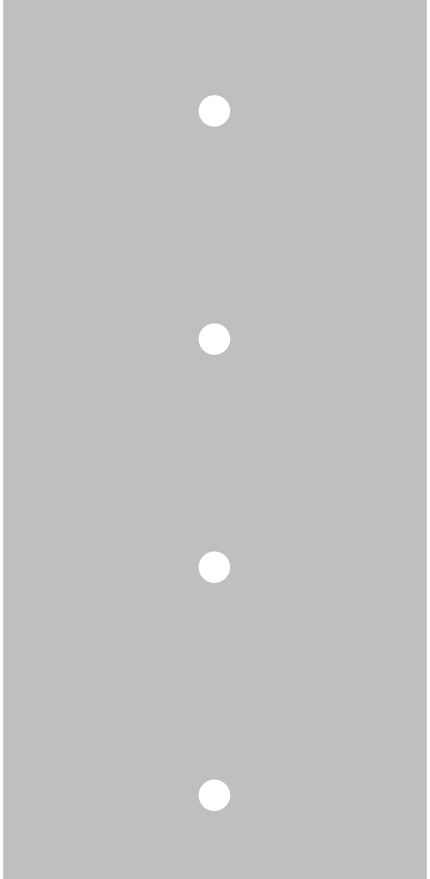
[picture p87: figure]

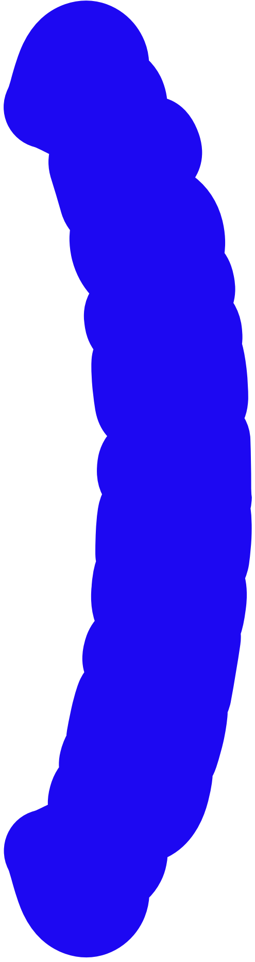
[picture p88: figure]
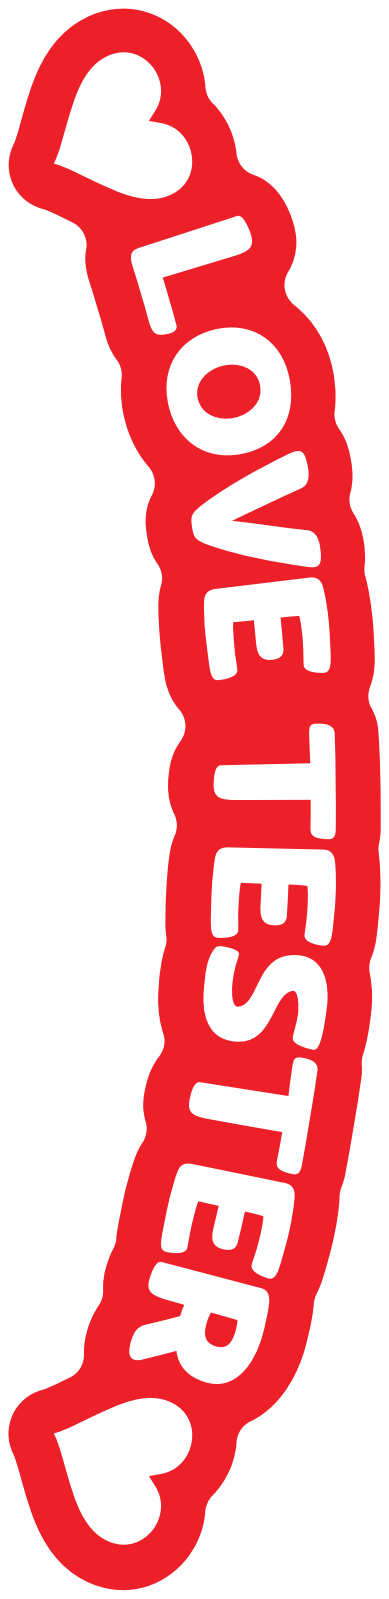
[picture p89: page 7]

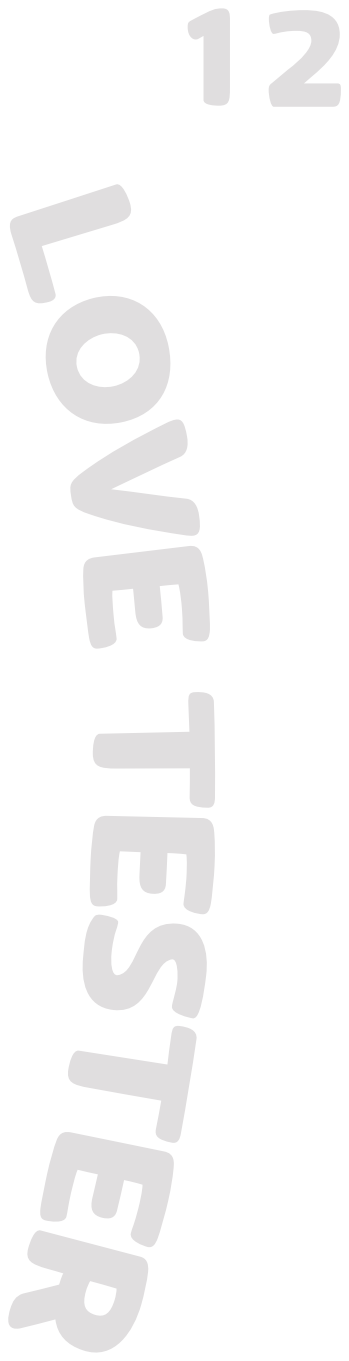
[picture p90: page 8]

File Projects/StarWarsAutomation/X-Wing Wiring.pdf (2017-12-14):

T

R

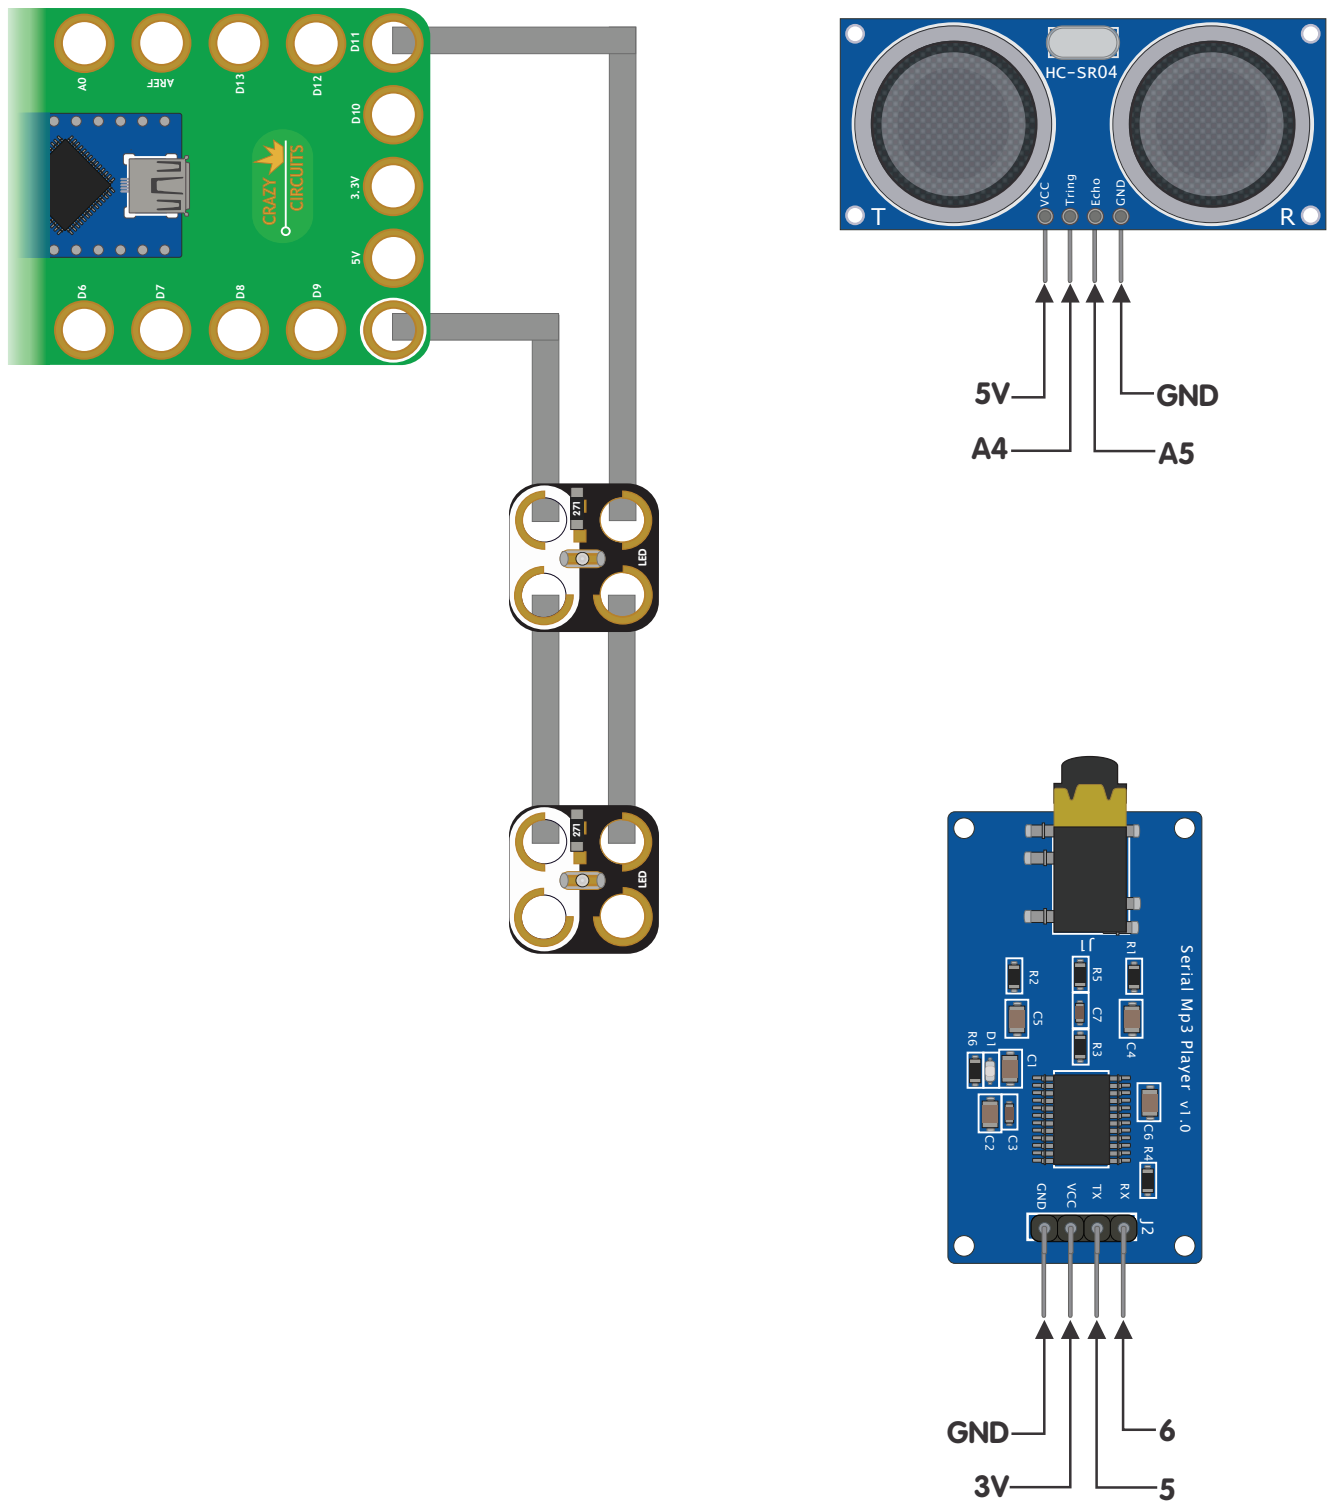
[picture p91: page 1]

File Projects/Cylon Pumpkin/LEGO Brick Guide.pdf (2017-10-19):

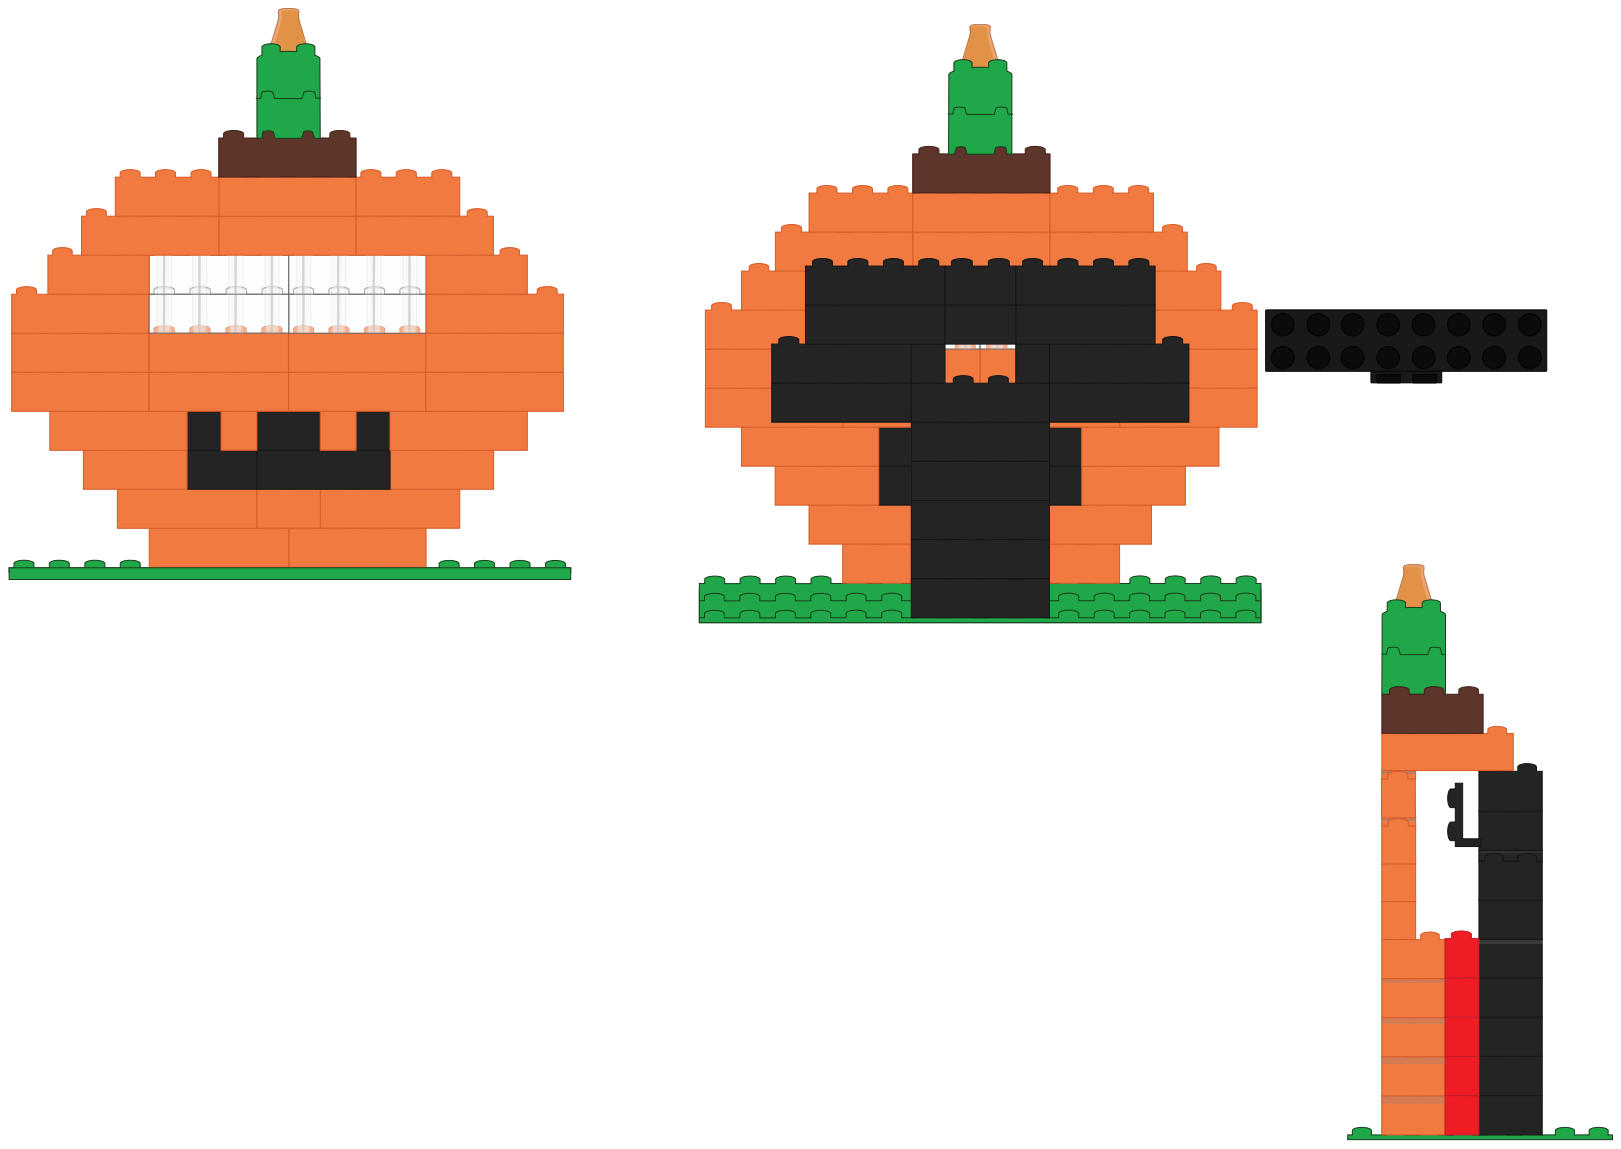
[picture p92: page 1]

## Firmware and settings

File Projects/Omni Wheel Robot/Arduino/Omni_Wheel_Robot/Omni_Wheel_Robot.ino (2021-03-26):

/*
 * Omni_Wheel_Robot.ino
 * 
 * Full Guide: https://browndoggadgets.dozuki.com/Guide/Omni+Wheel+Robot/310
 * 
 * Pete Prodoehl <pete@browndoggadgets.com>
 * 
 */

#include <Servo.h>

// create the 4 servos
Servo servoA;
Servo servoB;
Servo servoC;
Servo servoD;

// set the values for stopped, forward, and backward
int halt = 1500;
int rotX = 700;
int rotY = 2300;

int quarterRotation = 1290; // this may need adjustment

void setup() {

  // attach the four servos
  servoA.attach(3);
  servoB.attach(5);
  servoC.attach(6);
  servoD.attach(9);

  // wait 2 seconds before starting
  delay(2000);

}

void loop() {

  forwardLeftRoll(500);
  backwardRightRoll(500);
  forwardRightRoll(500);
  backwardLeftRoll(500);

  forwardRoll(500);
  leftRoll(500);
  backwardRoll(500);
  rightRoll(500);

  spinLeft(quarterRotation * 4);
  spinRight(quarterRotation * 4);

  forwardLeftRoll(1000);
  backwardRightRoll(1000);
  forwardRightRoll(1000);
  backwardLeftRoll(1000);

  forwardRoll(1000);
  leftRoll(1000);
  backwardRoll(1000);
  rightRoll(1000);

}



/* ------------ functions are below ------------ */

// each function take a parameter which is
// the number of milliseconds it should run
// 1000 milliseconds = 1 second


/* -------- move straight -------- */

void forwardRoll(int howLong) {
  allStop();
  servoA.write(rotX);
  servoB.write(rotY);
  servoC.write(halt);
  servoD.write(halt);
  delay(howLong);
}

void backwardRoll(int howLong) {
  allStop();
  servoA.write(rotY);
  servoB.write(rotX);
  servoC.write(halt);
  servoD.write(halt);
  delay(howLong);
}

void leftRoll(int howLong) {
  allStop();
  servoA.write(halt);
  servoB.write(halt);
  servoC.write(rotX);
  servoD.write(rotY);
  delay(howLong);
}

void rightRoll(int howLong) {
  allStop();
  servoA.write(halt);
  servoB.write(halt);
  servoC.write(rotY);
  servoD.write(rotX);
  delay(howLong);
}


/* -------- move on an angle -------- */

void forwardLeftRoll(int howLong) {
  allStop();
  servoA.write(rotY);
  servoB.write(rotX);
  servoC.write(rotX);
  servoD.write(rotY);
  delay(howLong);
}

void forwardRightRoll(int howLong) {
  allStop();
  servoA.write(rotY);
  servoB.write(rotX);
  servoC.write(rotY);
  servoD.write(rotX);
  delay(howLong);
}

void backwardRightRoll(int howLong) {
  allStop();
  servoA.write(rotX);
  servoB.write(rotY);
  servoC.write(rotY);
  servoD.write(rotX);
  delay(howLong);
}

void backwardLeftRoll(int howLong) {
  allStop();
  servoA.write(rotX);
  servoB.write(rotY);
  servoC.write(rotX);
  servoD.write(rotY);
  delay(howLong);
}


/* -------- spin around -------- */

void spinRight(int howLong) {
  allStop();
  servoA.write(rotX);
  servoB.write(rotX);
  servoC.write(rotX);
  servoD.write(rotX);
  delay(howLong);
}

void spinLeft(int howLong) {
  allStop();
  servoA.write(rotY);
  servoB.write(rotY);
  servoC.write(rotY);
  servoD.write(rotY);
  delay(howLong);
}


/* -------- stop moving -------- */

void allStop() {
  servoA.write(halt);
  servoB.write(halt);
  servoC.write(halt);
  servoD.write(halt);
  delay(500);
}

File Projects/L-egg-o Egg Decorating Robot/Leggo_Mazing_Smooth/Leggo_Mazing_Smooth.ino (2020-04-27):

// Code for DIY L"egg"o Amazing Egg Decorator with Lego
// By Natasha Dzurny for Brown Dog Gadgets

// Circuit: Connect Potentiometers to A0, A3 and A5, Connect the grey servos to D3 and D5, and the orange servo to D6



#include <Servo.h> //Include the library that lets you command the servo

Servo servoAngle;                 // Servos
Servo servoTilt;
Servo servoDrive;

const int servoAnglePin = 3;          // Servo Pins
const int servoTiltPin = 5;
const int servoDrivePin = 6;

const int numReadings = 10;          // how many readings does the code average to smooth the servo motion?

int readingsRight[numReadings];      // the reading from each potentiometer
int readingsMid[numReadings];     
int readingsLeft[numReadings];      
int readIndexRight = 0;              // the index of the current reading
int readIndexMid = 0;            
int readIndexLeft = 0;            
int totalRight = 0;                  // the total of all current readings
int totalMid = 0;               
int totalLeft = 0;                
int averageRight = 0;                // the average
int averageMid = 0;           
int averageLeft = 0;             


int readLeft = A0;                  // where to read the analog pins
int readMid = A3;
int readRight = A5;

int leftPosition;                   // the mapped position of the servos
int midPosition;
int rightPosition;



void setup() {
  servoAngle.attach(servoAnglePin);  // Attach Servos
  servoTilt.attach(servoTiltPin);
  servoDrive.attach(servoDrivePin);
  Serial.begin(9600);

  for (int thisReading = 0; thisReading < numReadings; thisReading++) { // Set all readings to 0
    readingsRight[thisReading] = 0;
    readingsMid[thisReading] = 0;
    readingsLeft[thisReading] = 0;
  }

}

void loop() {

  totalLeft = totalLeft - readingsLeft[readIndexLeft];      // Remove the current reading
  totalMid = totalMid - readingsMid[readIndexMid];
  totalRight = totalRight - readingsRight[readIndexRight];

  readingsLeft[readIndexLeft] = analogRead(readLeft);       // Read the potentiometers
  readingsMid[readIndexMid] = analogRead(readMid);
  readingsRight[readIndexRight] = analogRead(readRight);

  totalLeft = totalLeft + readingsLeft[readIndexLeft];      // Add the new reading
  totalMid = totalMid + readingsMid[readIndexMid];
  totalRight = totalRight + readingsRight[readIndexRight];

  readIndexLeft = readIndexLeft + 1;                         // Move the index forward one
  readIndexMid = readIndexMid + 1;
  readIndexRight = readIndexRight + 1;

  if (readIndexLeft >= numReadings) {                        // Return index to 0 if it is greater than or equal to the number of Readings setting
    readIndexLeft = 0;
  }
  if (readIndexMid >= numReadings) {
    readIndexMid = 0;
  }
  if (readIndexRight >= numReadings) {
    readIndexRight = 0;
  }


  averageLeft = totalLeft / numReadings;                  // Divide to get average
  averageMid = totalMid / numReadings;
  averageRight = totalRight / numReadings;


  // Map averages to positions of servos:
  leftPosition = map(averageLeft, 0, 1023, 0, 50); // = degrees the motor can spin the arm left to right = 50 (change if necessary)
  midPosition = map(averageMid, 0, 1023, 0, 45); // = degrees that the motor can tilt the pen up and down = 45 (change if necessary)
  rightPosition = map(averageRight, 0, 1023, 0, 179); // total degrees for a continuous rotation servo (DON'T change)

  Serial.print("leftPosition: ");         // print the values for testing
  Serial.print(leftPosition);
  Serial.print("  midPosition: ");
  Serial.print(midPosition);

  servoAngle.write(leftPosition);         // Move the servos to the position
  servoTilt.write(midPosition);

  if (rightPosition >= 80) {              // The continuous servo stands still at 90 degrees, and moves in one direction or the other at 0 or 180 degrees
    servoDrive.write(rightPosition);      // The larger or lower the number, the faster the servo moves in that direction (fll speed at 0 and 180, slower toward 90)
  } else if (rightPosition <= 179) {
    servoDrive.write(rightPosition);
  } else if (rightPosition >= 81 && rightPosition <= 99) { // If the position is close to 90, also stand still so that you don't have to be exact
    servoDrive.write(90);
  }

  Serial.print("  rightPosition: ");      // print the values for testing
  Serial.println(rightPosition);

  delay(15);                              // Give the code a little rest

}

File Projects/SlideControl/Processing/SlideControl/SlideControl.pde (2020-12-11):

import processing.sound.*;
import themidibus.*;

MidiBus myBus;

SoundFile slideForward;
SoundFile slideBack;

void setup() {
  size(260, 130);
  background(0);
  color(200);
  textSize(48);
  textAlign(CENTER);
  text("Waiting...", 125, 75);

  // Load sound files
  slideForward = new SoundFile(this, "SlideForward.wav");
  slideBack = new SoundFile(this, "SlideBack.wav");

  MidiBus.list(); // List all available MIDI devices on STDOUT. This will show each device's index and name.
  
  myBus = new MidiBus(this, 0, 1); // Create a new MidiBus that matches what we see in the list
  
}

void draw() {
  int channel = 0;
  int pitch = 64;
  int velocity = 127;

  myBus.sendNoteOn(channel, pitch, velocity); // Send a Midi noteOn
  delay(100);
  myBus.sendNoteOff(channel, pitch, velocity); // Send a Midi nodeOff

  int number = 0;
  int value = 90;

  myBus.sendControllerChange(channel, number, value); // Send a controllerChange
  delay(1000);
}

void noteOn(int channel, int pitch, int velocity) {

  if (pitch == 60) {
    background(0);
    text("Back", 130, 75);
    slideBack.play();
    delay(1000);
  }
  
  if (pitch == 61) {
    background(0);
    text("Forward", 130, 75);
    slideForward.play();
    delay(1000);
  }
  
}

void noteOff(int channel, int pitch, int velocity) {
  // Receive a noteOff
  println();
  println("Note Off:");
  println("--------");
  println("Channel:"+channel);
  println("Pitch:"+pitch);
  println("Velocity:"+velocity);
  
  background(0);
  text("Waiting...", 130, 75);  
    
}

void controllerChange(int channel, int number, int value) {
  // Receive a controllerChange
  println();
  println("Controller Change:");
  println("--------");
  println("Channel:"+channel);
  println("Number:"+number);
  println("Value:"+value);
}

void delay(int time) {
  int current = millis();
  while (millis () < current+time) Thread.yield();
}

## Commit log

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2016-10-25 Broke out circuit kits from test boards.
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2016-10-25 Added initial size test Eagle project for historical reasons.
    [structure.brd, structure.sch]
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2016-10-25 Moved Ken stuff. Sent in questions to Joshua.
    [LEGO_LED-B_Cu.gbr, LEGO_LED-B_Mask.gbr, LEGO_LED-B_SilkS.gbr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]
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2016-10-27 Added v1.1 with protosnap but more clover-like boards.
    [LegoLED-Button-Battery.kicad_pcb]
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2016-11-21 Created USB Breakout with Reset v1.0
    [USB-Breakout-with-Reset-B.Cu.gbl, USB-Breakout-with-Reset-B.Fab.gbr, USB-Breakout-with-Reset-B.Mask.gbs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]
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2016-11-21 Placed mask over top holes to prevent contact.
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2016-12-07 Tented the Lego holes on top side of CR2032 footprint.
    [LegoLED-Button-Battery-B.Cu.gbl, LegoLED-Button-Battery-B.Fab.gbr, LegoLED-Button-Battery-B.Mask.gbs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]
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2016-12-13 Moved finished contents into two dirs so README stays visible.
    [LegoLED-Button-Battery-B.Cu.gbl, LegoLED-Button-Battery-B.Fab.gbr, LegoLED-Button-Battery-B.Mask.gbs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]
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2016-12-15 Finished script to create new mod or ck project.
    [rewire-circuit-kit.kicad_pcb, rewire-circuit-kit.sch]
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2016-12-28 Converted to Crazy Circuit Kit with new logo.
    [LegoLED-Button-Battery-B.Cu.gbl, LegoLED-Button-Battery-B.Fab.gbr, LegoLED-Button-Battery-B.Mask.gbs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]
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2016-12-29 Broke out project into two parts.
    [10mmLED-Button-Battery-B.Cu.gbl, 10mmLED-Button-Battery-B.Fab.gbr, 10mmLED-Button-Battery-B.Mask.gbs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]
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2016-12-29 Release LegoLED version 1.3 fix.
    [LegoLED-Button-Battery-B.Cu.gbl, LegoLED-Button-Battery-B.Fab.gbr, LegoLED-Button-Battery-B.Mask.gbs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]
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2016-12-29 Release USB-Breakout-with-Reset v1.0 fix.
    [10mmLED-Button-Battery.kicad_pcb, LegoLED-Button-Battery.kicad_pcb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]
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2017-01-13 Changed 10mm from 5mm pitch to 2.54mm pitch.
    [10mmLED-Button-Battery-B.Cu.gbl, 10mmLED-Button-Battery-B.Fab.gbr, 10mmLED-Button-Battery-B.Mask.gbs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]
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2017-01-13 Release 2x2 and 2x3 LEDs with 2.54mm pitch.
    [2x3-LED-TH-2.54mm-Pitch-Magnet-B.Cu.gbl, 2x3-LED-TH-2.54mm-Pitch-Magnet-B.Fab.gbr, 2x3-LED-TH-2.54mm-Pitch-Magnet-B.Mask.gbs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]
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2017-01-13 Release the 2x2 Generic 2.54mm and 5mm pitch parts.
    [2x2-Generic-2.54mm-Pitch-B.Cu.gbl, 2x2-Generic-2.54mm-Pitch-B.Fab.gbr, 2x2-Generic-2.54mm-Pitch-B.Mask.gbs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]
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2017-01-18 Silk changes to all generic. Added 2.54mm pitch 2x2.
    [2x2-Generic-2.54mm-Pitch-B.Cu.gbl, 2x2-Generic-2.54mm-Pitch-B.Fab.gbr, 2x2-Generic-2.54mm-Pitch-B.Mask.gbs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]
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2017-01-18 Fix LED silk.
    [2x2-LED-TH-5mm-Pitch-B.Cu.gbl, 2x2-LED-TH-5mm-Pitch-B.Fab.gbr, 2x2-LED-TH-5mm-Pitch-B.Mask.gbs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]
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2017-01-19 Fixed generic 3.5mm drill hole size.
    [2x2-Generic-3.5mm-Pitch-B.Cu.gbl, 2x2-Generic-3.5mm-Pitch-B.Fab.gbr, 2x2-Generic-3.5mm-Pitch-B.Mask.gbs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]
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2017-01-19 Prettier preview images. Removed servo 2x3 from list.
    [2x3-Servo-Header.kicad_pcb, 2x3-Servo-Header.sch]
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2017-01-21 Working on RGB LED and USB Power, not done yet.
    [2x2-LED-RGB-SMT-B.Cu.gbl, 2x2-LED-RGB-SMT-B.Fab.gbr, 2x2-LED-RGB-SMT-B.Mask.gbs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]
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2017-01-24 Added logo and fixed pins on Teensy 4x10
    [4x10-Teensy-LC-Breakout-B.Cu.gbl, 4x10-Teensy-LC-Breakout-B.Fab.gbr, 4x10-Teensy-LC-Breakout-B.Mask.gbs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]
2017-01-24 Updated 5x10 Teensy to logo and new pins.
    [5x10-Teensy-LC-Breakout-B.Cu.gbl, 5x10-Teensy-LC-Breakout-B.Fab.gbr, 5x10-Teensy-LC-Breakout-B.Mask.gbs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]
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2017-01-26 Added 2x2 USB v1.1 with 3.3V and GND.
    [2x2-USB-Power-Connector-B.Cu.gbl, 2x2-USB-Power-Connector-B.Fab.gbr, 2x2-USB-Power-Connector-B.Mask.gbs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]
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2017-02-09 Release v1.2 with 30mil mask dam and copper fixes.
    [LegoLED-SMTButton-Battery-B.Cu.gbl, LegoLED-SMTButton-Battery-B.Fab.gbr, LegoLED-SMTButton-Battery-B.Mask.gbs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]
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2017-03-17 Fixed path change Crazy-Circuits to CrazyCircuits.
    [2x2-Slide-Switch-CL-SB-SMT.kicad_pcb, 2x2-Slide-Switch-CL-SB-SMT.sch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]
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2017-03-17 Add 2x2 and 2x3 Pushbutton schematics and parts.
    [2x2-Push-Terminal-3mm-Pitch-SMT.sch, 2x3-Push-Terminal-3mm-Pitch-SMT.sch, 2x3-Screw-Terminal-3.5mm-Pitch.sch]
2017-03-17 Add 3x4 555 Timer and 3x4 ATtiny85 schematic.
    [3x4-555-Timer-8SOIC-Breakout.sch, 3x4-ATtiny85-8SOIC-Breakout.sch]
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2017-03-17 Added schematics for 2x3 and 2x2 Slide Switch CL-SB
    [2x2-Slide-Switch-CL-SB-SMT.sch, 2x3-Slide-Switch-CL-SB-SMT.sch]
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2017-03-18 Fixed copper on Tilt 2x2 v1.0
    [2x2-Tilt-Switch-TH-B.Cu.gbl, 2x2-Tilt-Switch-TH-B.Mask.gbs, 2x2-Tilt-Switch-TH-B.Paste.gbp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]
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2017-03-21 Add ATtiny85, 555 Timer pads. Silk looks awful.
    [3x4-ATtiny85-8SOIC-Breakout.kicad_pcb]
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2017-04-22 Fix silk/mask on 555 Timer 8SOIC
    [3x4-555-Timer-8SOIC-Breakout-B.Cu.gbl, 3x4-555-Timer-8SOIC-Breakout-B.Mask.gbs, 3x4-555-Timer-8SOIC-Breakout-B.Paste.gbp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]
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2017-04-22 Fix silk on v1.0 ATtiny85 8SOIC
    [3x4-ATtiny85-8SOIC-Breakout-B.Cu.gbl, 3x4-ATtiny85-8SOIC-Breakout-B.Mask.gbs, 3x4-ATtiny85-8SOIC-Breakout-B.Paste.gbp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]
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2017-05-06 Add Arduino Nano Robot v1.1 with schematic in PDF.
    [2x3-Stereo-Headphone-Jack.sch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]
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2017-05-23 Add top copper rings to v1.2 1x3 Momentary TH Button
    [1x3-Button-Momentary-B.Cu.gbl, 1x3-Button-Momentary-B.Mask.gbs, 1x3-Button-Momentary-B.Paste.gbp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]
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2017-05-26 Add top copper rings. Release v1.1 EG1218 TH 2x2
    [2x2-Slide-Switch-EG1218-TH-B.Cu.gbl, 2x2-Slide-Switch-EG1218-TH-B.Mask.gbs, 2x2-Slide-Switch-EG1218-TH-B.Paste.gbp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]
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2017-05-27 Add top copper. Fix silk. Release v1.1 Photocell 2x2 TH
    [2x2-CdS-Photocell-TH-B.Cu.gbl, 2x2-CdS-Photocell-TH-B.Mask.gbs, 2x2-CdS-Photocell-TH-B.Paste.gbp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]
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2017-05-27 Silk fix on v1.2 2x2 LED SMT
    [2x2-LED-SMT-B.Cu.gbl, 2x2-LED-SMT-B.Mask.gbs, 2x2-LED-SMT-B.Paste.gbp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]
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2017-05-29 Add top copper rings. Release Audio Jack v1.1, only Mono not Stereo.
    [2x3-Stereo-Headphone-Jack-B.Cu.gbl, 2x3-Stereo-Headphone-Jack-B.Mask.gbs, 2x3-Stereo-Headphone-Jack-B.Paste.gbp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]
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2017-05-29 Fixed RGB pin silk.
    [2x3-LED-RGB-SMT-B.Cu.gbl, 2x3-LED-RGB-SMT-B.Mask.gbs, 2x3-LED-RGB-SMT-B.Paste.gbp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]
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2017-07-07 Fixed open trace. Released v1.3 2x2 Limited SMT LED
    [2x2-LED-SMT-LIMITED-B.Cu.gbl, 2x2-LED-SMT-LIMITED-B.Mask.gbs, 2x2-LED-SMT-LIMITED-B.Paste.gbp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]
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2017-08-07 Release v1.2 ATtiny85 3x4 with fixed copper.
    [3x4-ATtiny85-8DIP-Breakout-B.Cu.gbl, 3x4-ATtiny85-8DIP-Breakout-B.Mask.gbs, 3x4-ATtiny85-8DIP-Breakout-B.Paste.gbp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]
2017-08-07 Release v1.2 Teensy LC 5x10 with silk fixes.
    [5x10-Teensy-LC-Breakout-B.Cu.gbl, 5x10-Teensy-LC-Breakout-B.Mask.gbs, 5x10-Teensy-LC-Breakout-B.Paste.gbp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]
2017-08-08 Replace v1.2 Arduino Nano 5x11 with silk fix.
    [5x11-Arduino-Nano-Robot-Version-B.Cu.gbl, 5x11-Arduino-Nano-Robot-Version-B.Mask.gbs, 5x11-Arduino-Nano-Robot-Version-B.Paste.gbp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]
2017-08-08 Fixed complete zip of v1.2 5x11 Arduino Nano.
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2017-09-07 Add bottom & top mask dam on v1.2 2x3 Slide Switch EG1218 TH
    [2x3-Slide-Switch-EG1218-TH-B.Cu.gbl, 2x3-Slide-Switch-EG1218-TH-B.Mask.gbs, 2x3-Slide-Switch-EG1218-TH-B.Paste.gbp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]
2017-10-07 Release v1.2 2x2 Slide Switch TH with fixes for wave soldering.
    [2x2-Slide-Switch-EG1218-TH-B.Cu.gbl, 2x2-Slide-Switch-EG1218-TH-B.Mask.gbs, 2x2-Slide-Switch-EG1218-TH-B.Paste.gbp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]
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2017-10-07 Release v1.2 2x2 CdS Photocell TH with wave solder fix.
    [2x2-CdS-Photocell-TH-B.Cu.gbl, 2x2-CdS-Photocell-TH-B.Mask.gbs, 2x2-CdS-Photocell-TH-B.Paste.gbp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]
2017-10-07 Release v1.1 3x4 8DIP Breakout with wave solder fix.
    [3x4-555-Timer-8DIP-Breakout-B.Cu.gbl, 3x4-555-Timer-8DIP-Breakout-B.Mask.gbs, 3x4-555-Timer-8DIP-Breakout-B.Paste.gbp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]
2017-10-07 Release v1.3 3x4 ATtiny85 8DIP Breakout with wave solder fix.
    [3x4-ATtiny85-8DIP-Breakout-B.Cu.gbl, 3x4-ATtiny85-8DIP-Breakout-B.Mask.gbs, 3x4-ATtiny85-8DIP-Breakout-B.Paste.gbp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]
2017-10-07 Release v1.3 2x3 TH 2.54mm LED Breakout wave solder fix.
    [2x3-LED-TH-2.54mm-Pitch-Magnet-B.Cu.gbl, 2x3-LED-TH-2.54mm-Pitch-Magnet-B.Mask.gbs, 2x3-LED-TH-2.54mm-Pitch-Magnet-B.Paste.gbp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]
2017-10-07 Release v1.2 2x3 TH Screw Terminal wave solder fix.
    [2x3-Screw-Terminal-3.5mm-Pitch-B.Cu.gbl, 2x3-Screw-Terminal-3.5mm-Pitch-B.Mask.gbs, 2x3-Screw-Terminal-3.5mm-Pitch-B.Paste.gbp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]
2017-10-07 Release v1.2 2x3 TH Mini Pot 3386 wave solder fix.
    [2x3-Mini-Potentiometer-3386P-TH-B.Cu.gbl, 2x3-Mini-Potentiometer-3386P-TH-B.Mask.gbs, 2x3-Mini-Potentiometer-3386P-TH-B.Paste.gbp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]
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2017-10-07 Release v1.3 2x3 TH Potentiometer wave solder fix.
    [2x3-Potentiometer-P160K-TH-B.Cu.gbl, 2x3-Potentiometer-P160K-TH-B.Mask.gbs, 2x3-Potentiometer-P160K-TH-B.Paste.gbp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]
2017-10-07 Release v1.2 2x2 Servo TH wave solder fix.
    [2x2-Servo-Header-B.Cu.gbl, 2x2-Servo-Header-B.Mask.gbs, 2x2-Servo-Header-B.Paste.gbp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]
2017-10-07 Release v1.3 2x3 Servo TH wave solder fix.
    [2x3-Servo-Header-B.Cu.gbl, 2x3-Servo-Header-B.Mask.gbs, 2x3-Servo-Header-B.Paste.gbp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]
2017-10-07 Release v1.2 2x3 Vibe Motor TH wave solder fix.
    [2x3-Vibe-Motor-TH-B.Cu.gbl, 2x3-Vibe-Motor-TH-B.Mask.gbs, 2x3-Vibe-Motor-TH-B.Paste.gbp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]
2017-10-07 Release v1.2 2x2 Tilt TH wave solder fix.
    [03-Seeeduino_PCB_specification.xlsx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]
2017-10-07 Release v1.1 2x2 Tilt TH 520D wave solder fix.
    [2x2-Tilt-Switch-SW-520D-TH-B.Cu.gbl, 2x2-Tilt-Switch-SW-520D-TH-B.Mask.gbs, 2x2-Tilt-Switch-SW-520D-TH-B.Paste.gbp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]
2017-10-07 Wave solder fixes for v1.3 10mmLED-Button-Battery kit
    [10mmLED-Button-Battery-B.Cu.gbl, 10mmLED-Button-Battery-B.Mask.gbs, 10mmLED-Button-Battery-B.Paste.gbp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]
2017-10-07 Wave solder fixes for v1.5 LegoLED-Button-Battery kit
    [LegoLED-Button-Battery-B.Cu.gbl, LegoLED-Button-Battery-B.Mask.gbs, LegoLED-Button-Battery-B.Paste.gbp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]
2017-10-07 Wave solder fixes for v1.2 LegoLED-SMTButton-Battery kit
    [LegoLED-SMTButton-Battery-B.Cu.gbl, LegoLED-SMTButton-Battery-B.Mask.gbs, LegoLED-SMTButton-Battery-B.Paste.gbp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]
2017-10-07 Wave solder fixes for v1.3 VibeMotor-Button-Battery kit
    [VibeMotor-Button-Battery-B.Cu.gbl, VibeMotor-Button-Battery-B.Mask.gbs, VibeMotor-Button-Battery-B.Paste.gbp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]
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2018-07-31 Release 6x10 Photon v1.1 with fixed pin width
    [6x10-Photon-Breakout-B.Cu.gbl, 6x10-Photon-Breakout-B.Mask.gbs, 6x10-Photon-Breakout-B.Paste.gbp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]
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2018-09-25 Fix assembly diagram.
    [2x3-Dark-Detector-B.Cu.gbl, 2x3-Dark-Detector-B.Mask.gbs, 2x3-Dark-Detector-B.SilkS.gbo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]
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2018-09-25 Swap RST/GND. Release Attiny85 8SOIC 3x4 v1.3
    [3x4-ATtiny85-8SOIC-Breakout-B.Cu.gbl, 3x4-ATtiny85-8SOIC-Breakout-B.Mask.gbs, 3x4-ATtiny85-8SOIC-Breakout-B.Paste.gbp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]
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2018-10-08 Fix connection on 2x3 Neopixel
    [2x3-LED-RGB-NeoPixel-SMT-B.Cu.gbl, 2x3-LED-RGB-NeoPixel-SMT-B.Mask.gbs, 2x3-LED-RGB-NeoPixel-SMT-B.SilkS.gbo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]
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2019-04-24 Increase mask clearance. Release 3x3 CR2032 v1.4
    [3x3-CR2032-Coin-Cell-B.Cu.gbl, 3x3-CR2032-Coin-Cell-B.Mask.gbs, 3x3-CR2032-Coin-Cell-B.SilkS.gbo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]
2019-04-24 Increase mask clearance. Release 3x4 CR2032 v1.4
    [3x4-CR2032-Coin-Cell-Magnet-B.Cu.gbl, 3x4-CR2032-Coin-Cell-Magnet-B.Mask.gbs, 3x4-CR2032-Coin-Cell-Magnet-B.SilkS.gbo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]
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2019-04-24 Update pads-mask clearance to 10 mils
    [crazy.kicad_pcb]
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2020-01-08 add 2x3-Mini-Potentiometer-3386P-TH top silk lines
    Add lines to the top silk of x3-Mini-Potentiometer-3386P-TH per
    instructions from Josh.
    [2x3-Mini-Potentiometer-3386P-TH.kicad_pcb]
2020-01-08 add gerbers with top silk fix from Drew
    I plotted new gerbers in KiCad after adding lines to the top silk
    layer according to direction from Josh
    [2x3-Mini-Potentiometer-3386P-TH-B_Cu.gbl, 2x3-Mini-Potentiometer-3386P-TH-B_Fab.gbr, 2x3-Mini-Potentiometer-3386P-TH-B_Mask.gbs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]
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2021-04-16 Adapting design
    * Modified footprint to remove nano
    * Made the VCC for analog headers be 3.3v
    [5x11-Raspi-Pico-Robot-Version.kicad_pcb, 5x11-Raspi-Pico-Robot-Version.sch]
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2021-04-28 Updated Schematic, GP2-5 to D2, D3, D4, D5 and A0, A1, and a 7th header for A2.
    [5x11-Raspi-Pico-Robot-Version.sch]
2021-04-28 Fix nets for J7
    [5x11-Raspi-Pico-Robot-Version.sch]
2021-04-28 Update 5x11-Raspi-Pico-Robot-Version.kicad_pcb
    Added U7 for ADC2
    Changed PWM pins to different GPIO
    [5x11-Raspi-Pico-Robot-Version.kicad_pcb]
2021-04-30 Updates
    Silkscreen changed to reflect the IO on the pico
    Moved board outline into PCB
    Connected AREF
    [5x11-Raspi-Pico-Robot-Version.kicad_pcb, 5x11-Raspi-Pico-Robot-Version.sch]
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2021-04-30 Silk Edits
    Labels for 3 pin connectors added.
    Orientation guide placed above logo.
    [5x11-Raspi-Pico-Robot-Version.kicad_pcb]
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2021-05-24 Fix missing board outline
2021-05-24 Update footprint with correct outline.
    [6x11-Raspi-Pico-Robot-Version.kicad_pcb]
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2021-05-25 Design Changes
    * Removed D0 and D16
    * Shifted pins
    * Added silkscreen labels for 3v
    * Broke out VBUS and VSYS
    [6x11-Raspi-Pico-Robot-Version.kicad_pcb, 6x11-Raspi-Pico-Robot-Version.sch]
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2021-05-27 Added plus and minus to the left and right of top pin headers.
    [6x11-Raspi-Pico-Robot-Version.kicad_pcb]
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2021-05-27 fixed silk labels on right
    [6x11-Raspi-Pico-Robot-Version.kicad_pcb]
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2021-09-29 LEGO Avoidance Tank Added
    [LEGO-Avoidance-Tank.ino]
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2022-04-17 Added new Vsys Connector, replaced old a2 connector.
    [6x11-Raspi-Pico-Robot-Version.sch]
2022-04-17 Added Vsys connector and replaced a2 connector
    [6x11-Raspi-Pico-Robot-Version.kicad_pcb]
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2025-01-09 Flipped direction of pin to the right
    [2x2-Power-Connector-2.54mm-Pitch.kicad_pcb]
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2025-12-10 Swap polarity of connector
    [2x3-Power-Connector-2.54mm-Pitch.kicad_pcb, 2x3-Power-Connector-2.54mm-Pitch.kicad_sch]
